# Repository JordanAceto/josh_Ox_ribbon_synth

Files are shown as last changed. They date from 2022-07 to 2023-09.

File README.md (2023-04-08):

# josh_Ox_ribbon_synth
Ribbon synth for [Josh Oxford](https://www.joshoxford.com/)

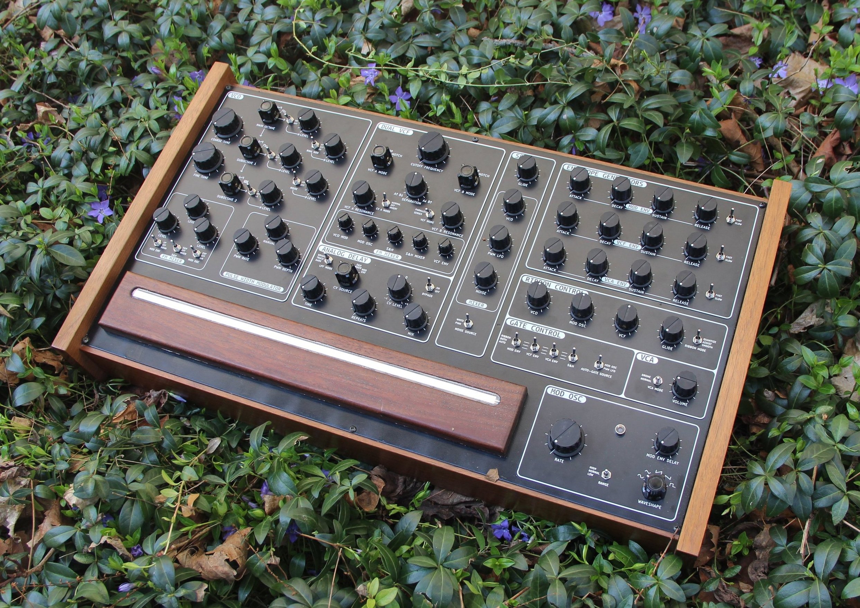
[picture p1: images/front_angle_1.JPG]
synth front synth from front


## Main Features 
- Single VCO with two sub-oscillators
- Transformer/diode based Ring Modulator
- Dual State-Variable Filter
- Bucket brigade Analog Delay with modulation
- Envelope VCA
- Volume VCA
- Three ADSR's
- Sample and Hold
- Flexible gate control
- Versatile Modulation Oscillator
- Ribbon controller with quantizer

## Status:

A complete synthesizer has been built with the current documents here. This instrument has been road tested on a few gigs. The current files represent a working instrument.

There are a few small PCB kludges required, and some potential future enhancements.
See the `github Issues` and `github Discussions` for little things that could be improved and an idea of what may change in the future.

The synth is constructed with semi-independent PCBs and panels for the major circuit blocks, which allows for gradually upgrading the components over time.

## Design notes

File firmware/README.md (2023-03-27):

# Rust Language STM32L412KBU Digital Ribbon Controller

## The firmware is installed on an STM32 microcontroller on the ribbon board via SWD header

---

## What it does
- Reads the analog ribbon controller and converts it into position and finger-down information
- Reads incoming MIDI messages and merges MIDI note information with the ribbon control
- Generates analog 1volt/octave and gate signals which can be used to control the VCO, MODOSC, VCF, and ADSRs

---

## Features
- Independent VCO, MODOSC, and VCF attenuators
- Glide control
- Quantizer for VCO only with three modes:
  - QUANTIZE: hard quantization, notes zipper to one another
  - ASSIST: initial finger presses attempt to play in-tune, but sliding is smooth
  - SMOOTH: unquantized smooth ribbon

---

## MIDI implementation
- There is some MIDI functionality baked into the hardware, but it is not complete.
- Same for the software, MIDI input is farther along than MIDI output.
- At this moment, there is no MIDI jack exposed to the outside world, so there is no way for the user to use MIDI.
- It is possible that future improvements will expand on the MIDI functionality. There are internal headers on the ribbon circuit board for future MIDI IO expansion.

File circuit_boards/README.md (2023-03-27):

# Ox Ribbon Synth Circuit Boards

## The synth is made up of the following components:
- Power Entry and step-down AC transformer
- AC-DC power supply board
    - Provides regulated +/- 15 VDC to the rest of the system
- Main VCO board
    - Contains two fully featured sub-scillators, a ring-modulator, pulse-width modulation LFO, and audio mixer
- VCF/VCA/BBD board
    - Contains a dual State Variable Filter setup with series/parallel switching and rich modulation
    - Linear VCA for envelope control
    - Analog delay effects unit
    - Linear VCA for final volume control
- Sample & Hold board
    - With three input mixer, white/pink noise source, and glide control
- Modulation Oscillator
    - Wide frequency range, five waveforms, and delayed modulation capability
- ADSR board
    - Three independent ADSR generators
- Ribbon board
    - Generates ribbon CV and gate signals
    - routes and combines ribbon gate and auto-gate

## Each major system component has its own subdirectory with:
- All files needed to edit the schematic and PCB layout with KiCad
- Documentation files needed to build and troubleshoot the circuits

## The approximate current draw of the circuitboards is:

| Board | V+ | V- |
| --- | ----- | ----- |
| ADSR | 30mA  | 20mA  |
| main VCO  | 120mA | 100mA |
| mod osc | 20mA  | 10mA  |
| ribbon | 40mA  | 20mA  |
| S&H | 20mA  | 20mA  |
| VCF/VCA | 60mA  | 50mA  |
| | | |
| **TOTAL** | 290mA | 220mA |

## The block diagram below illustrates how the components interact:
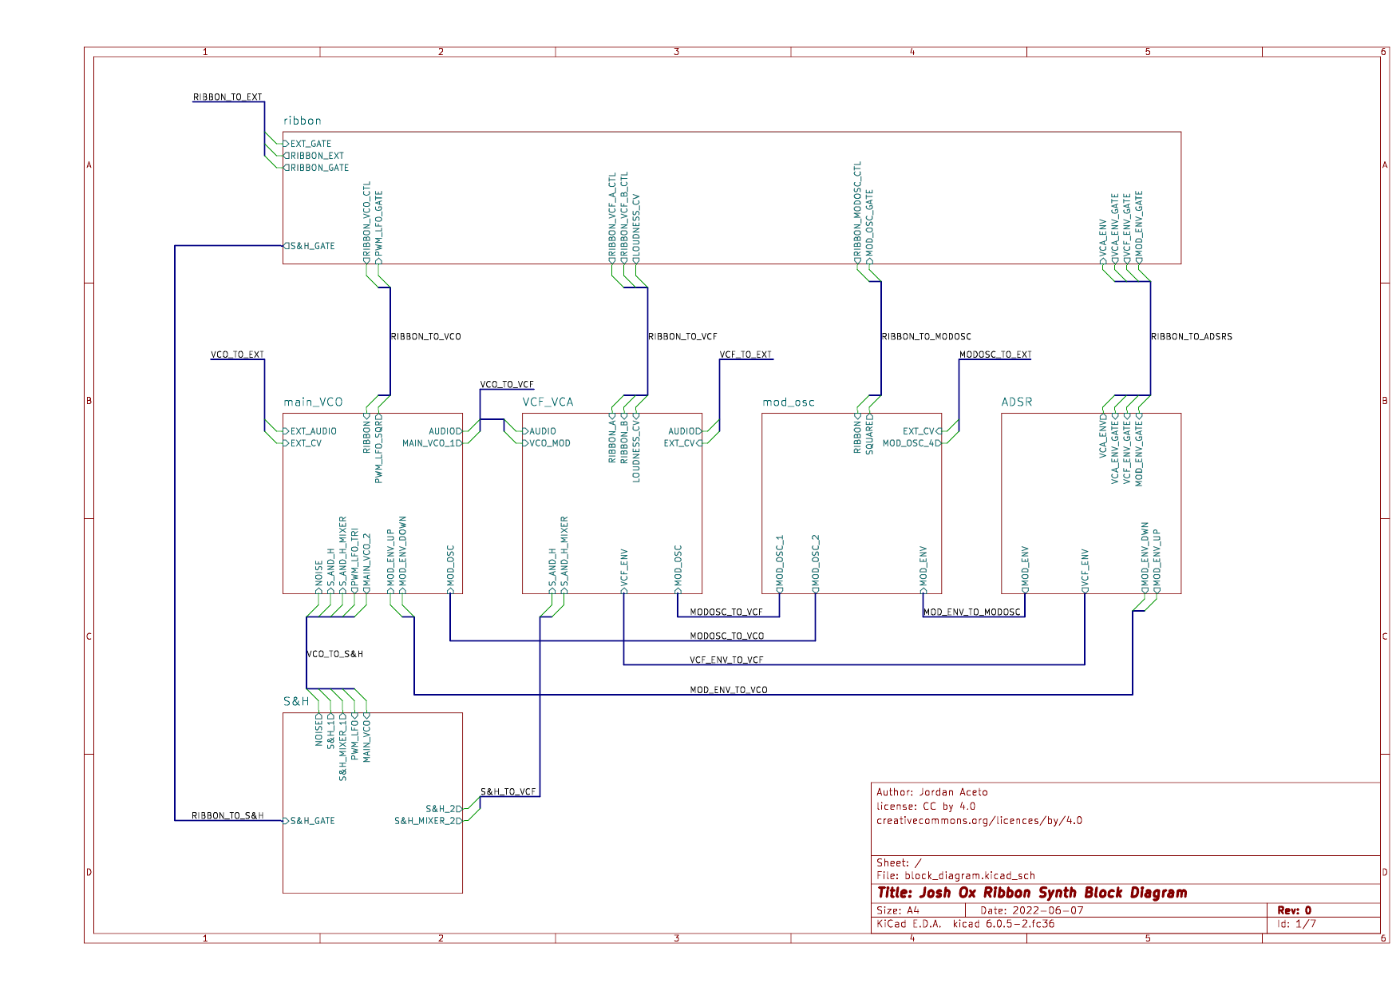
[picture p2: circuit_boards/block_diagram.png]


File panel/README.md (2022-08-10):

# Panel Files

The front panel is made of an aluminum sheet, with individual 0.8mm thick PCB panels for each major circuit block.

The PCB panels are a cheap way to get a decent looking front panel. Using individual panels keeps the cost of each panel down, and allows for flexibility: if a circuit block needs to be modified in the future, we can remake just the individual panel section, and not the whole front panel.

See the individual directories for details.

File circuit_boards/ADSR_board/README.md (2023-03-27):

# Triple ADSR Board

## [SCHEMATIC](https://github.com/JordanAceto/josh_Ox_ribbon_synth/blob/master/circuit_boards/ADSR_board/docs/ADSR_board_schematic.pdf)

Three ADSR envelope generators with short and long time range switch.

A comparator and analog switch ensure that the sustain control reacts quickly during sustain phases, even when the decay control is set for long time constants.

pcb render

pcb render

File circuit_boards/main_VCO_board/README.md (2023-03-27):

# Complex VCO

## [SCHEMATIC](https://github.com/JordanAceto/josh_Ox_ribbon_synth/blob/master/circuit_boards/main_VCO_board/docs/main_VCO_board_schematic.pdf)

Single VCO with tons 'o extra stuff
- SSI2130 VCO core
- sine, triangle, sawtooth, and variable pulse waveforms
- two suboscillators, each with all four waveforms, phase modulated (not locked) to the main VCO
- PWM LFO
- transformer/diode based ring modulator
- audio mixer
- FM mixer

pcb render

pcb render

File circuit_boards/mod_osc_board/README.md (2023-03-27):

# Modulation Oscillator

## [SCHEMATIC](https://github.com/JordanAceto/josh_Ox_ribbon_synth/blob/master/circuit_boards/mod_osc_board/docs/mod_osc_board_schematic.pdf)

Auxilliary modulation oscillator
- SSI21340 VCO core
- sine, triangle, up and down-going sawtooth, and square waveforms
- wide frequency range with three range settings (low, normal, high)
- tracks the ribbon controller

pcb render

pcb render

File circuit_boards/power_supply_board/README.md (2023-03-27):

# Power Supply Board

## [SCHEMATIC](https://github.com/JordanAceto/josh_Ox_ribbon_synth/blob/master/circuit_boards/power_supply_board/docs/power_supply_schematic.pdf)

This is an unremarkable LM317/LM337 based bipolar 15 volt DC supply which supplies power to the rest of the system.

pcb render

pcb render

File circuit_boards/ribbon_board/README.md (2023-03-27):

# ribbon_board

## [SCHEMATIC](https://github.com/JordanAceto/josh_Ox_ribbon_synth/blob/master/circuit_boards/ribbon_board/docs/ribbon_board_schematic.pdf)

Digital ribbon controller, gate combiner, and VCA control scaler

PCB front

PCB back

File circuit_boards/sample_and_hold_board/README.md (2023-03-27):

# Sample And Hold

## [SCHEMATIC](https://github.com/JordanAceto/josh_Ox_ribbon_synth/blob/master/circuit_boards/sample_and_hold_board/docs/sample_and_hold_board_schematic.pdf)

Basic Sample & Hold with three input mixer, noise source, and glide control.

pcb render

pcb render

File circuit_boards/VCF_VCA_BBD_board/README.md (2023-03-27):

# VCF/VCA/BBD Board

## [SCHEMATIC](https://github.com/JordanAceto/josh_Ox_ribbon_synth/blob/master/circuit_boards/VCF_VCA_BBD_board/docs/VCF_VCA_BBD_board_schematic.pdf)

This board contains a dual State Variable Filter, Bucket Brigade Analog Delay, and two linear audio VCAs.

### State Variable Filters
- each filter has Lowpass, Bandpass, Highpass and Notch outputs
- filters can be routed in either Serial or Parallel configuration
- CV mixer for a variety of modulation
- control to filter A can be inverted relative to filter B

### Analog Delay
- about 40 milliseconds to 1 second of delay
- modulation input with attenuverter
- three lowpass filter modes:
    - `BRIGHT`: no filtration, aliasing occurs at long delay times. Aliasing is normally avoided, but it can sound good in a nasty way. Useful for extreme effects
    - `TRACK`: lowpass filter tracks the delay clock, brighter at short times and darker at long times
    - `DARK`: classic warm BBD sound

### VCAs
- one VCA for the volume ADSR before the analog delay
- one VCA for the final master volume control after the delay

pcb render

pcb render

## Measurements to aid in calibration (no ribbon ctl, no modulation, knob swept ccw to cw, approx):
- VCF freq range: 12Hz, 12kHz
- delay clk: 100kHz, 4kHz
- delay lpf
    - track mode: 60kHz, 3kHz
    - bright mode: fixed 20kHz
    - dark mode: fixed 3kHz

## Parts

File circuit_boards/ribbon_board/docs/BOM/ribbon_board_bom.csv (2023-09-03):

# | Reference | Qty | Value | Footprint | DNP
1 | C201, C202, C203, C204, C205, C206, C207, C208, C209, C210, C211, C301, C302, C303, C304, C306, C307, C308, C309, C310, C311, C312, C903, C904, C906, C909, C910, C911, C912, C913, C914, C915, C916, C917 | 34 | 100n | Capacitor_SMD:C_0603_1608Metric
2 | C212, C213 | 2 | 4p3 | Capacitor_SMD:C_0603_1608Metric
3 | C305, C907 | 2 | 1u | Capacitor_SMD:C_0805_2012Metric
4 | C901, C902 | 2 | 10u | Capacitor_THT:CP_Radial_D6.3mm_P2.50mm
5 | C905 | 1 | 2u2 | Capacitor_SMD:C_0805_2012Metric
6 | D201 | 1 | DNF | Diode_SMD:D_SOD-123 | DNP
7 | D202, D301, D501, D502, D503, D504, D601, D602, D603, D604, D701, D702, D703, D704, D801, D802, D803, D804 | 18 | 1N4148W | Diode_SMD:D_SOD-123
8 | D302, D303 | 2 | 5v1 | Diode_SMD:D_SOD-123
9 | FB1001, FB1002 | 2 | 100R @ 100MHz | Inductor_SMD:L_0805_2012Metric
10 | J1 | 1 | VCO_port | Connector_Molex:Molex_KK-254_AE-6410-03A_1x03_P2.54mm_Vertical
11 | J2 | 1 | VCF_port | Connector_Molex:Molex_KK-254_AE-6410-05A_1x05_P2.54mm_Vertical
12 | J3 | 1 | mod_osc_port | Connector_Molex:Molex_KK-254_AE-6410-04A_1x04_P2.54mm_Vertical
13 | J4 | 1 | ADSR_port | Connector_Molex:Molex_KK-254_AE-6410-05A_1x05_P2.54mm_Vertical
14 | J5 | 1 | S&H_port | Connector_Molex:Molex_KK-254_AE-6410-02A_1x02_P2.54mm_Vertical
15 | J6 | 1 | ext_port | Connector_Molex:Molex_KK-254_AE-6410-04A_1x04_P2.54mm_Vertical
16 | J7 | 1 | power_entry | Connector_IDC:IDC-Header_2x05_P2.54mm_Vertical
17 | J8 | 1 | MIDI_IO_port | Connector_Molex:Molex_KK-254_AE-6410-05A_1x05_P2.54mm_Vertical
18 | J201 | 1 | SWD_header | Connector_PinHeader_2.54mm:PinHeader_1x04_P2.54mm_Vertical
19 | R101, R102, R204, R313, R904 | 5 | 1k | Resistor_SMD:R_0805_2012Metric
20 | R201 | 1 | 22 | Resistor_SMD:R_0805_2012Metric
21 | R202 | 1 | DNF | Resistor_SMD:R_0805_2012Metric | DNP
22 | R203, R206, R309, R310, R401, R402, R403, R404 | 8 | 10k | Resistor_SMD:R_0805_2012Metric
23 | R205 | 1 | 220 | Resistor_SMD:R_0805_2012Metric
24 | R207, R208 | 2 | 47 | Resistor_SMD:R_0805_2012Metric
25 | R301, R302, R303, R304 | 4 | 20k | Resistor_SMD:R_0805_2012Metric
26 | R305, R306, R307, R308 | 4 | 68k | Resistor_SMD:R_0805_2012Metric
27 | R311, R314, R405, R406, R501, R502, R601, R602, R701, R702, R801, R802, R903 | 13 | 100k | Resistor_SMD:R_0805_2012Metric
28 | R312, R407, R408 | 3 | 1M2 | Resistor_SMD:R_0805_2012Metric
29 | R315, R316, R317, R318 | 4 | 12k | Resistor_SMD:R_0805_2012Metric
30 | R901 | 1 | 82k | Resistor_SMD:R_0805_2012Metric
31 | R902 | 1 | 200k | Resistor_SMD:R_0805_2012Metric
32 | RV201 | 1 | 10k | Potentiometer_THT:Potentiometer_Alpha_RD901F-40-00D_Single_Vertical
33 | RV202, RV203 | 2 | 10k c.d. | Potentiometer_THT:Potentiometer_Alpha_RD901F-40-00D_Single_Vertical
34 | RV204 | 1 | 10k c.d. | Potentiometer_THT:Potentiometer_Alpha_RD901F-40-00D_Single_Vertical
35 | RV301, RV302, RV303, RV304 | 4 | 5k | Potentiometer_THT:Potentiometer_Bourns_3296W_Vertical
36 | RV901 | 1 | 100k | Potentiometer_THT:Potentiometer_Alpha_RD901F-40-00D_Single_Vertical
37 | SP201 | 1 | softpot | Connector_Molex:Molex_KK-254_AE-6410-03A_1x03_P2.54mm_Vertical
38 | SW201, SW501, SW601, SW701, SW801 | 5 | SW_SPDT_MSM | custom_footprints:SPDT_mini_toggle
39 | SW202 | 1 | MIDI_CH | Button_Switch_THT:SW_DIP_SPSTx04_Slide_9.78x12.34mm_W7.62mm_P2.54mm
40 | SW401, SW901 | 2 | SW_SPDT | custom_footprints:SPDT_mini_toggle
41 | TP201 | 1 | RAW_RIBBON | TestPoint:TestPoint_Keystone_5000-5004_Miniature
42 | TP301 | 1 | VCO_RIBBON | TestPoint:TestPoint_Keystone_5000-5004_Miniature
43 | TP302 | 1 | MODOSC_RIBBON | TestPoint:TestPoint_Keystone_5000-5004_Miniature
44 | TP303 | 1 | VCF_RIBBON | TestPoint:TestPoint_Keystone_5000-5004_Miniature
45 | TP304 | 1 | AUX_CV | TestPoint:TestPoint_Keystone_5000-5004_Miniature
46 | TP401 | 1 | rib_gate | TestPoint:TestPoint_Keystone_5000-5004_Miniature
47 | TP402 | 1 | auto_gate | TestPoint:TestPoint_Keystone_5000-5004_Miniature
48 | TP901 | 1 | VCA_ADSR_CV | TestPoint:TestPoint_Keystone_5000-5004_Miniature
49 | TP902 | 1 | VCA_VOL_CV | TestPoint:TestPoint_Keystone_5000-5004_Miniature
50 | TP1001 | 1 | V+ | TestPoint:TestPoint_Keystone_5000-5004_Miniature
51 | TP1002 | 1 | V- | TestPoint:TestPoint_Keystone_5000-5004_Miniature
52 | TP1003 | 1 | GND | TestPoint:TestPoint_Bridge_Pitch7.62mm_Drill1.3mm
53 | TP1004 | 1 | 3v3 | TestPoint:TestPoint_Keystone_5000-5004_Miniature
54 | U1 | 1 | STM32L412K8Ux | Package_DFN_QFN:QFN-32-1EP_5x5mm_P0.5mm_EP3.45x3.45mm
55 | U2 | 1 | VO0600T | Package_SO:SOIC-8_3.9x4.9mm_P1.27mm
56 | U3, U4 | 2 | SN74LV1T34DBV | Package_TO_SOT_SMD:SOT-23-5
57 | U5 | 1 | DAC8164 | Package_SO:TSSOP-16_4.4x5mm_P0.65mm
58 | U6, U7, U8, U9 | 4 | TL072 | Package_SO:SOIC-8_3.9x4.9mm_P1.27mm
59 | U10 | 1 | 4081 | Package_SO:SOIC-14_3.9x8.7mm_P1.27mm
60 | U1004 | 1 | L78L05_SOT89 | Package_TO_SOT_SMD:SOT-89-3
61 | U1006 | 1 | L78L33_SOT89 | Package_TO_SOT_SMD:SOT-89-3
62 | Y1 | 1 | 32_768KHZ | Crystal:Crystal_SMD_MicroCrystal_CC7V-T1A-2Pin_3.2x1.5mm

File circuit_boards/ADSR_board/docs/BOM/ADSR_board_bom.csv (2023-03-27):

# | Reference | Qty | Value | Footprint | DNP
1 | C101, C102 | 2 | 10u | Capacitor_THT:CP_Radial_D6.3mm_P2.50mm
2 | C103, C104, C205, C206, C207, C208, C209, C210, C305, C306, C307, C308, C309, C310, C405, C406, C407, C408, C409, C410 | 20 | 100n | Capacitor_SMD:C_0805_2012Metric
3 | C201, C202, C301, C302, C401, C402 | 6 | 1n | Capacitor_SMD:C_0805_2012Metric
4 | C203, C303, C403 | 3 | 2u2 | Capacitor_THT:CP_Radial_D6.3mm_P2.50mm
5 | C204, C304, C404 | 3 | 22u | Capacitor_THT:CP_Radial_D6.3mm_P2.50mm
6 | D201, D202, D301, D302, D401, D402 | 6 | 1N4148W | Diode_SMD:D_SOD-123
7 | J1 | 1 | ribbon_port | Connector_Molex:Molex_KK-254_AE-6410-05A_1x05_P2.54mm_Vertical
8 | J2 | 1 | modosc_port | Connector_Molex:Molex_KK-254_AE-6410-02A_1x02_P2.54mm_Vertical
9 | J3 | 1 | VCO_port | Connector_Molex:Molex_KK-254_AE-6410-03A_1x03_P2.54mm_Vertical
10 | J4 | 1 | VCF_port | Connector_Molex:Molex_KK-254_AE-6410-03A_1x03_P2.54mm_Vertical
11 | J5 | 1 | power_entry | Connector_IDC:IDC-Header_2x05_P2.54mm_Vertical
12 | Q201, Q301, Q401 | 3 | MMBT3904 | Package_TO_SOT_SMD:SOT-23
13 | R101, R102, R201, R202, R211, R301, R302, R311, R401, R402, R411 | 11 | 100k | Resistor_SMD:R_0805_2012Metric
14 | R203, R204, R212, R214, R303, R304, R312, R314, R403, R404, R412, R414 | 12 | 10k | Resistor_SMD:R_0805_2012Metric
15 | R205, R305, R405 | 3 | 5k6 | Resistor_SMD:R_0805_2012Metric
16 | R206, R207, R208, R306, R307, R308, R406, R407, R408 | 9 | 22 | Resistor_SMD:R_0805_2012Metric
17 | R209, R309, R409 | 3 | 100 | Resistor_SMD:R_0805_2012Metric
18 | R210, R310, R410 | 3 | 2k7 | Resistor_SMD:R_0805_2012Metric
19 | R213, R313, R413 | 3 | 2M2 | Resistor_SMD:R_0805_2012Metric
20 | RV201, RV202, RV204, RV301, RV302, RV304, RV401, RV402, RV404 | 9 | 1MA | Potentiometer_THT:Potentiometer_Alpha_RD901F-40-00D_Single_Vertical
21 | RV203, RV303, RV403 | 3 | 10k | Potentiometer_THT:Potentiometer_Alpha_RD901F-40-00D_Single_Vertical
22 | SW201, SW301, SW401 | 3 | SW_SPDT | custom_footprints:SPDT_mini_toggle
23 | TP1 | 1 | MOD env | TestPoint:TestPoint_Keystone_5000-5004_Miniature
24 | TP2 | 1 | inv mod env | TestPoint:TestPoint_Keystone_5000-5004_Miniature
25 | TP3 | 1 | VCF env | TestPoint:TestPoint_Keystone_5000-5004_Miniature
26 | TP4 | 1 | VCA env | TestPoint:TestPoint_Keystone_5000-5004_Miniature
27 | TP5 | 1 | V+ | TestPoint:TestPoint_Keystone_5000-5004_Miniature
28 | TP6 | 1 | GND | TestPoint:TestPoint_Bridge_Pitch7.62mm_Drill1.3mm
29 | TP7 | 1 | V- | TestPoint:TestPoint_Keystone_5000-5004_Miniature
30 | U101, U203, U303, U403 | 4 | TL072 | Package_SO:SOIC-8_3.9x4.9mm_P1.27mm
31 | U201, U301, U401 | 3 | TLC555 | Package_SO:SOIC-8_3.9x4.9mm_P1.27mm
32 | U202, U302, U402 | 3 | CD4052B | Package_SO:SOIC-16_3.9x9.9mm_P1.27mm
33 | U204, U304, U404 | 3 | DG470EY | Package_SO:SOIC-8_3.9x4.9mm_P1.27mm

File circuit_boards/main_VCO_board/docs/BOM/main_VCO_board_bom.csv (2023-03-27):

# | Reference | Qty | Value | Footprint | DNP
1 | C201, C402, C403, C404, C502, C803, C901, C1001, C1603, C1701, C1801, C2003, C2004, C2005, C2006, C2101, C2102, C2103, C2104 | 19 | 100p | Capacitor_SMD:C_0805_2012Metric
2 | C202, C601, C1401 | 3 | 1u | Capacitor_THT:C_Rect_L7.2mm_W5.5mm_P5.00mm_FKS2_FKP2_MKS2_MKP2
3 | C301, C801, C1601 | 3 | 10u | Capacitor_SMD:C_0805_2012Metric
4 | C302, C1101, C1202, C1901 | 4 | 10n | Capacitor_SMD:C_0805_2012Metric
5 | C303 | 1 | 3N9 COG | Capacitor_SMD:C_0805_2012Metric
6 | C401 | 1 | 10u BP | Capacitor_THT:C_Rect_L7.2mm_W3.5mm_P5.00mm_FKS2_FKP2_MKS2_MKP2
7 | C501 | 1 | 220n | Capacitor_THT:C_Rect_L7.0mm_W2.5mm_P5.00mm
8 | C701, C1201, C1501, C2001, C2002, C2201 | 6 | 10p | Capacitor_SMD:C_0805_2012Metric
9 | C802, C1602 | 2 | 10u BP | Capacitor_THT:C_Radial_D6.3mm_H5.0mm_P2.50mm
10 | C2301, C2302, C2303, C2304, C2305, C2306, C2307, C2308, C2309, C2310, C2313, C2314, C2315, C2316, C2317, C2318, C2321, C2322, C2323, C2324, C2325, C2326, C2327, C2328, C2329, C2330, C2331, C2332, C2333, C2334, C2335, C2336, C2337, C2338, C2339, C2340, C2341, C2342 | 38 | 100n | Capacitor_SMD:C_0805_2012Metric
11 | C2311, C2312 | 2 | 10u | Capacitor_THT:CP_Radial_D6.3mm_P2.50mm
12 | C2319, C2320 | 2 | 470n | Capacitor_SMD:C_0805_2012Metric
13 | D301, D302, D601, D602, D1001, D1002, D1801, D1802 | 8 | 1N4148W | Diode_SMD:D_SOD-123
14 | D501, D502, D2101, D2102, D2103, D2104 | 6 | BAT48ZFILM | Diode_SMD:D_SOD-123
15 | J101 | 1 | ribbon_port | Connector_Molex:Molex_KK-254_AE-6410-03A_1x03_P2.54mm_Vertical
16 | J102 | 1 | modosc_port | Connector_Molex:Molex_KK-254_AE-6410-02A_1x02_P2.54mm_Vertical
17 | J103 | 1 | ADSR_port | Connector_Molex:Molex_KK-254_AE-6410-03A_1x03_P2.54mm_Vertical
18 | J104 | 1 | S&H_port | Connector_Molex:Molex_KK-254_AE-6410-06A_1x06_P2.54mm_Vertical
19 | J105 | 1 | ext_con | Connector_Molex:Molex_KK-254_AE-6410-03A_1x03_P2.54mm_Vertical
20 | J106 | 1 | vcf_port | Connector_Molex:Molex_KK-254_AE-6410-03A_1x03_P2.54mm_Vertical
21 | J501 | 1 | aux_pwm | Connector_PinHeader_2.54mm:PinHeader_1x02_P2.54mm_Vertical
22 | J2301 | 1 | power_entry | Connector_IDC:IDC-Header_2x05_P2.54mm_Vertical
23 | JP101 | 1 | rm_x_select | Connector_PinHeader_2.54mm:PinHeader_1x03_P2.54mm_Vertical
24 | Q401 | 1 | 2N7002 | Package_TO_SOT_SMD:SOT-23
25 | Q1101, Q1102, Q1901, Q1902 | 4 | MMBT3904 | Package_TO_SOT_SMD:SOT-23
26 | R201 | 1 | 150k | Resistor_SMD:R_0805_2012Metric
27 | R202 | 1 | 56k | Resistor_SMD:R_0805_2012Metric
28 | R203, R804, R1004, R1006, R1604, R1804, R1806 | 7 | 120k | Resistor_SMD:R_0805_2012Metric
29 | R204, R205, R304, R306, R307, R308, R309, R310, R311, R317, R401, R403, R405, R501, R505, R506, R507, R508, R509, R602, R704, R705, R706, R805, R807, R808, R809, R811, R813, R815, R902, R1203, R1504, R1505, R1506, R1605, R1607, R1608, R1609, R1611, R1613, R1615, R1702, R2002, R2004, R2008, R2009, R2010, R2011, R2012, R2015, R2101, R2102, R2103, R2105, R2107, R2108, R2109, R2110, R2111, R2201, R2202, R2203, R2204, R2205 | 65 | 100k | Resistor_SMD:R_0805_2012Metric
30 | R206, R702, R703, R814, R1502, R1503, R1614, R2005, R2006 | 9 | 200k | Resistor_SMD:R_0805_2012Metric
31 | R301, R302, R406, R603, R604, R803, R1103, R1106, R1201, R1603, R1903, R1906, R2001, R2303, R2304 | 15 | 10k | Resistor_SMD:R_0805_2012Metric
32 | R303, R402, R901, R1701, R2206 | 5 | 33k | Resistor_SMD:R_0805_2012Metric
33 | R305 | 1 | 1M | Resistor_SMD:R_0805_2012Metric
34 | R312, R502 | 2 | 270k | Resistor_SMD:R_0805_2012Metric
35 | R313 | 1 | 47k | Resistor_SMD:R_0805_2012Metric
36 | R314 | 1 | 270 | Resistor_SMD:R_0805_2012Metric
37 | R315 | 1 | 470k | Resistor_SMD:R_0805_2012Metric
38 | R316, R319, R321, R2302 | 4 | 4k7 | Resistor_SMD:R_0805_2012Metric
39 | R318 | 1 | 3k9 | Resistor_SMD:R_0805_2012Metric
40 | R320, R1108, R1109, R1908, R1909 | 5 | 12k | Resistor_SMD:R_0805_2012Metric
41 | R322, R1105, R1905 | 3 | 18k | Resistor_SMD:R_0805_2012Metric
42 | R404, R503 | 2 | 100 | Resistor_SMD:R_0805_2012Metric
43 | R407, R408, R409, R2013 | 4 | 20k | Resistor_SMD:R_0805_2012Metric
44 | R504, R1102, R1107, R1205, R1902, R1907, R2007 | 7 | 2k2 | Resistor_SMD:R_0805_2012Metric
45 | R510, R511, R806, R810, R1206, R1606, R1610 | 7 | 1k | Resistor_SMD:R_0805_2012Metric
46 | R601 | 1 | 1M5 | Resistor_SMD:R_0805_2012Metric
47 | R701, R812, R1501, R1612, R2016 | 5 | 180k | Resistor_SMD:R_0805_2012Metric
48 | R801, R1601 | 2 | 8k2 | Resistor_SMD:R_0805_2012Metric
49 | R802, R1602 | 2 | 2k7 | Resistor_SMD:R_0805_2012Metric
50 | R1001, R1002, R1005, R1202, R1801, R1802, R1805 | 7 | 15k | Resistor_SMD:R_0805_2012Metric
51 | R1003, R1803 | 2 | 7k5 | Resistor_SMD:R_0805_2012Metric
52 | R1101, R1901 | 2 | 27k | Resistor_SMD:R_0805_2012Metric
53 | R1104, R1904 | 2 | 390 | Resistor_SMD:R_0805_2012Metric
54 | R1204, R2003 | 2 | 10M | Resistor_SMD:R_0805_2012Metric
55 | R1401 | 1 | 2M2 | Resistor_SMD:R_0805_2012Metric
56 | R2014 | 1 | 220k | Resistor_SMD:R_0805_2012Metric
57 | R2104, R2106 | 2 | 330 | Resistor_SMD:R_0805_2012Metric
58 | R2112 | 1 | 560k | Resistor_SMD:R_0805_2012Metric
59 | R2207 | 1 | 82k | Resistor_SMD:R_0805_2012Metric
60 | R2301 | 1 | 1k8 | Resistor_SMD:R_0805_2012Metric
61 | RV201, RV202 | 2 | 10k | Potentiometer_THT:Potentiometer_Alpha_RD901F-40-00D_Single_Vertical
62 | RV203, RV204, RV205, RV501, RV502, RV503, RV2201, RV2202, RV2203, RV2204, RV2205 | 11 | 100k | Potentiometer_THT:Potentiometer_Alpha_RD901F-40-00D_Single_Vertical
63 | RV301, RV302, RV303, RV802, RV1602 | 5 | 5k | Potentiometer_THT:Potentiometer_Bourns_3296W_Vertical
64 | RV701, RV801, RV1101, RV1102, RV1501, RV1601, RV1901, RV1902, RV2001, RV2101, RV2102 | 11 | 50k | Potentiometer_THT:Potentiometer_Bourns_3296W_Vertical
65 | SW201, SW202, SW203 | 3 | SW_SPDT_CO | custom_footprints:SPDT_mini_toggle
66 | SW301, SW602, SW1402 | 3 | SR1712F-0204 | custom_footprints:SR1712F_rotary_switch
67 | SW601, SW1401, SW2101 | 3 | SW_DPDT_CO | custom_footprints:DPDT_mini_toggle
68 | SW2201, SW2202 | 2 | SW_SPDT | custom_footprints:SPDT_mini_toggle
69 | TP101 | 1 | pwm_cv | TestPoint:TestPoint_Keystone_5000-5004_Miniature
70 | TP102 | 1 | oct_0 | TestPoint:TestPoint_Keystone_5000-5004_Miniature
71 | TP103 | 1 | oct_1 | TestPoint:TestPoint_Keystone_5000-5004_Miniature
72 | TP104 | 1 | oct_2 | TestPoint:TestPoint_Keystone_5000-5004_Miniature
73 | TP105 | 1 | ring_mod | TestPoint:TestPoint_Keystone_5000-5004_Miniature
74 | TP106 | 1 | mix | TestPoint:TestPoint_Keystone_5000-5004_Miniature
75 | TP801, TP1601 | 2 | anim_LFO | TestPoint:TestPoint_Keystone_5000-5004_Miniature
76 | TP2301 | 1 | V+ | TestPoint:TestPoint_Keystone_5000-5004_Miniature
77 | TP2302 | 1 | V- | TestPoint:TestPoint_Keystone_5000-5004_Miniature
78 | TP2303 | 1 | GND | TestPoint:TestPoint_Bridge_Pitch7.62mm_Drill1.3mm
79 | TP2304 | 1 | +5_REF | TestPoint:TestPoint_Keystone_5000-5004_Miniature
80 | TP2305 | 1 | +2V5 | TestPoint:TestPoint_Keystone_5000-5004_Miniature
81 | TP2306 | 1 | -5_REF | TestPoint:TestPoint_Keystone_5000-5004_Miniature
82 | TP2307 | 1 | +5 | TestPoint:TestPoint_Keystone_5000-5004_Miniature
83 | TP2308 | 1 | -5 | TestPoint:TestPoint_Keystone_5000-5004_Miniature
84 | TR2101, TR2102 | 2 | Triad_TY_141P | custom_footprints:Triad_TY-141P
85 | U1, U2, U6, U8, U11, U12, U14, U15, U16 | 9 | TL074 | Package_SO:SOIC-14_3.9x8.7mm_P1.27mm
86 | U3, U7, U13 | 3 | LM311 | Package_SO:SOIC-8_3.9x4.9mm_P1.27mm
87 | U4 | 1 | SSI2130 | custom_footprints:PQN32_HandSoldering
88 | U5 | 1 | 4013 | Package_SO:SOIC-14_3.9x8.7mm_P1.27mm
89 | U9 | 1 | LM555xM | Package_SO:SOIC-8_3.9x4.9mm_P1.27mm
90 | U10 | 1 | DG413xY | Package_SO:SOIC-16_3.9x9.9mm_P1.27mm
91 | U17 | 1 | NE5532 | Package_SO:SOIC-8_3.9x4.9mm_P1.27mm
92 | U18 | 1 | TL072 | Package_SO:SOIC-8_3.9x4.9mm_P1.27mm
93 | U19 | 1 | DG447DV | Package_SO:TSOP-6_1.65x3.05mm_P0.95mm
94 | U2301 | 1 | L78L05_SOT89 | Package_TO_SOT_SMD:SOT-89-3
95 | U2302 | 1 | L79L05_SOT89 | Package_TO_SOT_SMD:SOT-89-3
96 | U2303 | 1 | LM4040C-2.5 | Package_TO_SOT_SMD:SOT-23
97 | U2304 | 1 | LM4040DBZ-5 | Package_TO_SOT_SMD:SOT-23

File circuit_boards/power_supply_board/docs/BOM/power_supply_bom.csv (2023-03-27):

# | Reference | Qty | Value | Footprint | DNP
1 | C1, C2 | 2 | 3300u | Capacitor_THT:CP_Radial_D18.0mm_P7.50mm
2 | C3, C4, C5, C6 | 4 | 100n | Capacitor_THT:C_Rect_L7.0mm_W2.5mm_P5.00mm
3 | C7, C8 | 2 | 10u | Capacitor_THT:CP_Radial_D6.3mm_P2.50mm
4 | D1, D2, D3, D4, D5, D6, D7, D8 | 8 | 1N4002 | Diode_THT:D_DO-41_SOD81_P10.16mm_Horizontal
5 | J1, J2, J3, J4, J5, J6, J7, J8 | 8 | power_out | Connector_IDC:IDC-Header_2x05_P2.54mm_Vertical
6 | J9 | 1 | AC_power_in | Connector_Molex:Molex_Mini-Fit_Jr_5566-04A_2x02_P4.20mm_Vertical
7 | R1, R2 | 2 | 240 | Resistor_THT:R_Axial_DIN0207_L6.3mm_D2.5mm_P10.16mm_Horizontal
8 | RV1, RV2 | 2 | 5k | Potentiometer_THT:Potentiometer_Bourns_3296W_Vertical
9 | TP1 | 1 | V+ | TestPoint:TestPoint_Keystone_5000-5004_Miniature
10 | TP2 | 1 | V- | TestPoint:TestPoint_Keystone_5000-5004_Miniature
11 | TP3 | 1 | GND | TestPoint:TestPoint_Bridge_Pitch7.62mm_Drill1.3mm
12 | U1 | 1 | LM317_TO-220 | Package_TO_SOT_THT:TO-220-3_Vertical
13 | U2 | 1 | LM337_TO220 | Package_TO_SOT_THT:TO-220-3_Vertical

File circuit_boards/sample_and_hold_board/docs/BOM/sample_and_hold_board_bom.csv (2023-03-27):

# | Reference | Qty | Value | Footprint | DNP
1 | C1, C2 | 2 | 100p | Capacitor_SMD:C_0805_2012Metric
2 | C3, C8 | 2 | 10p | Capacitor_SMD:C_0805_2012Metric
3 | C4, C6 | 2 | 47u | Capacitor_THT:CP_Radial_D6.3mm_P2.50mm
4 | C5, C11, C15, C20 | 4 | 10u | Capacitor_THT:CP_Radial_D6.3mm_P2.50mm
5 | C7 | 1 | 1n | Capacitor_SMD:C_0805_2012Metric
6 | C9 | 1 | 3n3 | Capacitor_SMD:C_0805_2012Metric
7 | C10 | 1 | 47n | Capacitor_SMD:C_0805_2012Metric
8 | C12 | 1 | 2n2 | Capacitor_SMD:C_0805_2012Metric
9 | C13 | 1 | 470n | Capacitor_THT:C_Rect_L7.2mm_W5.5mm_P5.00mm_FKS2_FKP2_MKS2_MKP2
10 | C14 | 1 | 2n2 | Capacitor_THT:C_Rect_L7.2mm_W2.5mm_P5.00mm_FKS2_FKP2_MKS2_MKP2
11 | C16, C17, C18, C19, C21, C22, C23, C24 | 8 | 100n | Capacitor_SMD:C_0805_2012Metric
12 | D1 | 1 | 1N4148W | Diode_SMD:D_SOD-123
13 | J1 | 1 | VCO_port | Connector_Molex:Molex_KK-254_AE-6410-06A_1x06_P2.54mm_Vertical
14 | J2 | 1 | VCF_port | Connector_Molex:Molex_KK-254_AE-6410-03A_1x03_P2.54mm_Vertical
15 | J3 | 1 | ribbon_port | Connector_Molex:Molex_KK-254_AE-6410-02A_1x02_P2.54mm_Vertical
16 | J4 | 1 | power_entry | Connector_IDC:IDC-Header_2x05_P2.54mm_Vertical
17 | Q1, Q3 | 2 | MMBT3904 | Package_TO_SOT_SMD:SOT-23
18 | Q2 | 1 | 2N3904 | Package_TO_SOT_THT:TO-92_Inline_Wide
19 | R1, R2, R4, R5, R6, R16, R27 | 7 | 100k | Resistor_SMD:R_0805_2012Metric
20 | R3, R11 | 2 | 47k | Resistor_SMD:R_0805_2012Metric
21 | R7 | 1 | 47 | Resistor_SMD:R_0805_2012Metric
22 | R8, R19, R22, R25, R28 | 5 | 10k | Resistor_SMD:R_0805_2012Metric
23 | R9, R17 | 2 | 470k | Resistor_SMD:R_0805_2012Metric
24 | R10 | 1 | 33k | Resistor_SMD:R_0805_2012Metric
25 | R12 | 1 | 150k | Resistor_SMD:R_0805_2012Metric
26 | R13 | 1 | 3k9 | Resistor_SMD:R_0805_2012Metric
27 | R14 | 1 | 82k | Resistor_SMD:R_0805_2012Metric
28 | R15 | 1 | 18k | Resistor_SMD:R_0805_2012Metric
29 | R18 | 1 | 390k | Resistor_SMD:R_0805_2012Metric
30 | R20, R21 | 2 | 1M | Resistor_SMD:R_0805_2012Metric
31 | R23 | 1 | 5k6 | Resistor_SMD:R_0805_2012Metric
32 | R24 | 1 | 150 | Resistor_SMD:R_0805_2012Metric
33 | R26 | 1 | 1k8 | Resistor_SMD:R_0805_2012Metric
34 | RV1, RV2, RV3 | 3 | 100k | Potentiometer_THT:Potentiometer_Alpha_RD901F-40-00D_Single_Vertical
35 | RV4 | 1 | 1M | Potentiometer_THT:Potentiometer_Alpha_RD901F-40-00D_Single_Vertical
36 | SW1 | 1 | SW_SPDT | custom_footprints:SPDT_mini_toggle
37 | TP1 | 1 | S&H mixer | TestPoint:TestPoint_Keystone_5000-5004_Miniature
38 | TP2 | 1 | S&H | TestPoint:TestPoint_Keystone_5000-5004_Miniature
39 | TP3 | 1 | trigger | TestPoint:TestPoint_Keystone_5000-5004_Miniature
40 | TP4 | 1 | white noise | TestPoint:TestPoint_Keystone_5000-5004_Miniature
41 | TP5 | 1 | pink noise | TestPoint:TestPoint_Keystone_5000-5004_Miniature
42 | TP6 | 1 | V+ | TestPoint:TestPoint_Keystone_5000-5004_Miniature
43 | TP7 | 1 | GND | TestPoint:TestPoint_Bridge_Pitch7.62mm_Drill1.3mm
44 | TP8 | 1 | V- | TestPoint:TestPoint_Keystone_5000-5004_Miniature
45 | U1, U2, U3 | 3 | TL072 | Package_SO:SO-8_5.3x6.2mm_P1.27mm
46 | U4 | 1 | LF398_SOIC14 | Package_SO:SOIC-14_3.9x8.7mm_P1.27mm

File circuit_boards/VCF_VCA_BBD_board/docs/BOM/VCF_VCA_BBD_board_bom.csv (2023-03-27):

# | Reference | Qty | Value | Footprint | DNP
1 | C101 | 1 | 10u | Capacitor_THT:C_Radial_D6.3mm_H7.0mm_P2.50mm
2 | C201, C203, C301, C303, C502, C503, C1105, C1302, C1303 | 9 | 1n | Capacitor_SMD:C_0805_2012Metric
3 | C202, C204, C302, C304, C801, C802, C803, C804, C1001, C1002, C1003, C1004 | 12 | 220p C0G | Capacitor_SMD:C_0805_2012Metric
4 | C401, C402, C403, C404, C405, C501, C504, C601, C1201, C1202, C1203, C1301, C1304 | 13 | 100p | Capacitor_SMD:C_0805_2012Metric
5 | C701, C706, C901, C903, C906, C1101, C1104 | 7 | 470n | Capacitor_THT:C_Rect_L7.0mm_W3.5mm_P5.00mm
6 | C702, C1103 | 2 | 220p | Capacitor_SMD:C_0805_2012Metric
7 | C703, C1102 | 2 | 220n | Capacitor_SMD:C_0805_2012Metric
8 | C704, C902, C904, C905 | 4 | 10u | Capacitor_SMD:C_0805_2012Metric
9 | C705 | 1 | 2u2 | Capacitor_SMD:C_0805_2012Metric
10 | C805, C1005, C1205 | 3 | 470p | Capacitor_SMD:C_0805_2012Metric
11 | C907, C908, C1207, C1403, C1404, C1405, C1406, C1407, C1408, C1409, C1410, C1411, C1412, C1413, C1414, C1415, C1416, C1417, C1418, C1419, C1420, C1421, C1422, C1423, C1424, C1425, C1426, C1427, C1428, C1429, C1430, C1431, C1432, C1433, C1434, C1435, C1436, C1437, C1438, C1439, C1440, C1441, C1442, C1443 | 44 | 100n | Capacitor_SMD:C_0805_2012Metric
12 | C1106 | 1 | 33p | Capacitor_SMD:C_0805_2012Metric
13 | C1204 | 1 | 10n | Capacitor_SMD:C_0805_2012Metric
14 | C1206 | 1 | 330p C0G | Capacitor_SMD:C_0805_2012Metric
15 | C1401, C1402 | 2 | 10u | Capacitor_THT:CP_Radial_D6.3mm_P2.50mm
16 | D101, D102 | 2 | 2v4 | Diode_SMD:D_SOD-123
17 | D201, D202, D301, D302 | 4 | 5v1 | Diode_SMD:D_SOD-123
18 | D401, D402, D403, D404, D901, D902, D1201, D1202, D1203, D1204 | 10 | 1N4148W | Diode_SMD:D_SOD-123
19 | J2 | 1 | ext_port | Connector_Molex:Molex_KK-254_AE-6410-04A_1x04_P2.54mm_Vertical
20 | J3 | 1 | mod_osc_port | Connector_Molex:Molex_KK-254_AE-6410-02A_1x02_P2.54mm_Vertical
21 | J4 | 1 | S&H_port | Connector_Molex:Molex_KK-254_AE-6410-03A_1x03_P2.54mm_Vertical
22 | J5 | 1 | ADSR_port | Connector_Molex:Molex_KK-254_AE-6410-03A_1x03_P2.54mm_Vertical
23 | J6 | 1 | ribbon_port | Connector_Molex:Molex_KK-254_AE-6410-05A_1x05_P2.54mm_Vertical
24 | J7 | 1 | power_entry | Connector_IDC:IDC-Header_2x05_P2.54mm_Vertical
25 | J101 | 1 | VCO_port | Connector_Molex:Molex_KK-254_AE-6410-03A_1x03_P2.54mm_Vertical
26 | JP801, JP1001 | 2 | self_osc | Connector_PinHeader_2.54mm:PinHeader_1x02_P2.54mm_Vertical
27 | Q1201 | 1 | MMBT3904 | Package_TO_SOT_SMD:SOT-23
28 | Q1202 | 1 | BCM847 | custom_footprints:SOT457
29 | R101, R401, R402, R403, R404, R405, R406, R407, R408, R409, R410, R411, R413, R414, R415, R417, R419, R420, R421, R422, R424, R502, R505, R601, R602, R603, R604, R702, R903, R904, R905, R908, R909, R910, R1104, R1201, R1205, R1218, R1302, R1305, R1402, R1403 | 42 | 100k | Resistor_SMD:R_0805_2012Metric
30 | R102, R815, R1015 | 3 | 1k | Resistor_SMD:R_0805_2012Metric
31 | R201, R203, R204, R206, R208, R209, R210, R211, R212, R301, R303, R304, R306, R308, R309, R310, R311, R312, R506, R507, R509, R1306, R1307, R1309 | 24 | 30k | Resistor_SMD:R_0805_2012Metric
32 | R202, R302, R416, R423 | 4 | 390k | Resistor_SMD:R_0805_2012Metric
33 | R205, R305, R706, R801, R803, R804, R806, R808, R810, R811, R813, R814, R911, R1001, R1003, R1004, R1006, R1008, R1010, R1011, R1013, R1014, R1101, R1219, R1220, R1221, R1224 | 27 | 10k | Resistor_SMD:R_0805_2012Metric
34 | R207, R213, R307, R313, R503, R508, R1303, R1308 | 8 | 270 | Resistor_SMD:R_0805_2012Metric
35 | R412, R426 | 2 | 18k | Resistor_SMD:R_0805_2012Metric
36 | R418, R425, R1212 | 3 | 220k | Resistor_SMD:R_0805_2012Metric
37 | R501, R1301 | 2 | 10M | Resistor_SMD:R_0805_2012Metric
38 | R504, R901, R902, R906, R907, R1304 | 6 | 4k7 | Resistor_SMD:R_0805_2012Metric
39 | R701 | 1 | 150k | Resistor_SMD:R_0805_2012Metric
40 | R703, R705, R1214 | 3 | 22k | Resistor_SMD:R_0805_2012Metric
41 | R704, R1102, R1204 | 3 | 2M2 | Resistor_SMD:R_0805_2012Metric
42 | R802, R805, R809, R812, R1002, R1005, R1009, R1012 | 8 | 200 | Resistor_SMD:R_0805_2012Metric
43 | R807, R1007 | 2 | 51k | Resistor_SMD:R_0805_2012Metric
44 | R816, R1016 | 2 | 12k | Resistor_SMD:R_0805_2012Metric
45 | R817, R1017 | 2 | 56k | Resistor_SMD:R_0805_2012Metric
46 | R1103 | 1 | 68k | Resistor_SMD:R_0805_2012Metric
47 | R1105 | 1 | 270k | Resistor_SMD:R_0805_2012Metric
48 | R1202, R1206, R1217 | 3 | 1M | Resistor_SMD:R_0805_2012Metric
49 | R1203, R1207, R1208 | 3 | 200k | Resistor_SMD:R_0805_2012Metric
50 | R1209 | 1 | 2k 3300ppm/C PTC | Resistor_THT:R_Axial_DIN0207_L6.3mm_D2.5mm_P10.16mm_Horizontal
51 | R1210 | 1 | 110k | Resistor_SMD:R_0805_2012Metric
52 | R1211 | 1 | 330 | Resistor_SMD:R_0805_2012Metric
53 | R1213 | 1 | 15k | Resistor_SMD:R_0805_2012Metric
54 | R1215 | 1 | 5k6 | Resistor_SMD:R_0805_2012Metric
55 | R1216 | 1 | 47k | Resistor_SMD:R_0805_2012Metric
56 | R1222 | 1 | 2k2 | Resistor_SMD:R_0805_2012Metric
57 | R1223 | 1 | 6k8 | Resistor_SMD:R_0805_2012Metric
58 | R1225 | 1 | 470k | Resistor_SMD:R_0805_2012Metric
59 | R1401 | 1 | 3k9 | Resistor_SMD:R_0805_2012Metric
60 | RV201, RV301, RV401, RV402, RV403, RV404, RV405, RV406, RV601, RV701, RV1101 | 11 | 100k | Potentiometer_THT:Potentiometer_Alpha_RD901F-40-00D_Single_Vertical
61 | RV407, RV602 | 2 | 100k c.d. | Potentiometer_THT:Potentiometer_Alpha_RD901F-40-00D_Single_Vertical
62 | RV408, RV410, RV1201, RV1202, RV1206 | 5 | 100k | Potentiometer_THT:Potentiometer_Bourns_3296W_Vertical
63 | RV409, RV411 | 2 | 5k | Potentiometer_THT:Potentiometer_Bourns_3296W_Vertical
64 | RV901, RV902, RV903, RV904, RV1204, RV1205 | 6 | 10k | Potentiometer_THT:Potentiometer_Bourns_3296W_Vertical
65 | RV1203 | 1 | 100 | Potentiometer_THT:Potentiometer_Bourns_3296W_Vertical
66 | SW1, SW2, SW4 | 3 | SR1712F-0204 | custom_footprints:SR1712F_rotary_switch
67 | SW3 | 1 | series_parallel_switch | custom_footprints:DPDT_mini_toggle
68 | SW5 | 1 | delay_bypass_switch | custom_footprints:SPDT_mini_toggle
69 | SW401 | 1 | SW_SPDT_MSM | custom_footprints:SPDT_mini_toggle
70 | SW1201 | 1 | SW_DP_on_on_on | custom_footprints:DPDT_mini_toggle
71 | TP101 | 1 | DRY | TestPoint:TestPoint_Keystone_5000-5004_Miniature
72 | TP102 | 1 | CV_A | TestPoint:TestPoint_Keystone_5000-5004_Miniature
73 | TP103 | 1 | ENV_VCA | TestPoint:TestPoint_Keystone_5000-5004_Miniature
74 | TP104 | 1 | VCF_A | TestPoint:TestPoint_Keystone_5000-5004_Miniature
75 | TP105 | 1 | DELAY | TestPoint:TestPoint_Keystone_5000-5004_Miniature
76 | TP106 | 1 | CV_B | TestPoint:TestPoint_Keystone_5000-5004_Miniature
77 | TP107 | 1 | FINAL_AUDIO | TestPoint:TestPoint_Keystone_5000-5004_Miniature
78 | TP108 | 1 | VCF_B | TestPoint:TestPoint_Keystone_5000-5004_Miniature
79 | TP601 | 1 | COMPRESSOR | TestPoint:TestPoint_Keystone_5000-5004_Miniature
80 | TP602 | 1 | BBD_LPF_1 | TestPoint:TestPoint_Keystone_5000-5004_Miniature
81 | TP603 | 1 | BBD_LPF_2 | TestPoint:TestPoint_Keystone_5000-5004_Miniature
82 | TP901 | 1 | BBD_1 | TestPoint:TestPoint_Keystone_5000-5004_Miniature
83 | TP902 | 1 | BBD_2 | TestPoint:TestPoint_Keystone_5000-5004_Miniature
84 | TP1201 | 1 | BBD_LPF_CV | TestPoint:TestPoint_Keystone_5000-5004_Miniature
85 | TP1401 | 1 | V+ | TestPoint:TestPoint_Keystone_5000-5004_Miniature
86 | TP1402 | 1 | V- | TestPoint:TestPoint_Keystone_5000-5004_Miniature
87 | TP1403 | 1 | GND | TestPoint:TestPoint_Bridge_Pitch7.62mm_Drill1.3mm
88 | TP1404 | 1 | REF+ | TestPoint:TestPoint_Keystone_5000-5004_Miniature
89 | TP1405 | 1 | REF- | TestPoint:TestPoint_Keystone_5000-5004_Miniature
90 | U1, U2, U4, U5, U6, U7, U8, U9, U13, U17, U18, U19, U23, U24 | 14 | TL072 | Package_SO:SOIC-8_3.9x4.9mm_P1.27mm
91 | U3, U10 | 2 | SSI2164 | Package_SO:SOIC-16_3.9x9.9mm_P1.27mm
92 | U11 | 1 | NE570 | Package_DIP:DIP-16_W7.62mm_Socket
93 | U12, U16 | 2 | SSI2140 | Package_SO:TSSOP-20_4.4x6.5mm_P0.65mm
94 | U14, U15 | 2 | MN3005 | custom_footprints:DIP-8-14_W7.62mm_Socket
95 | U20 | 1 | LM331 | Package_DIP:DIP-8_W7.62mm_Socket
96 | U21 | 1 | 4013 | Package_SO:SOIC-14_3.9x8.7mm_P1.27mm
97 | U22 | 1 | CD4049 | Package_SO:TSSOP-16_4.4x5mm_P0.65mm
98 | U1407 | 1 | LM4040DBZ-5 | Package_TO_SOT_SMD:SOT-23

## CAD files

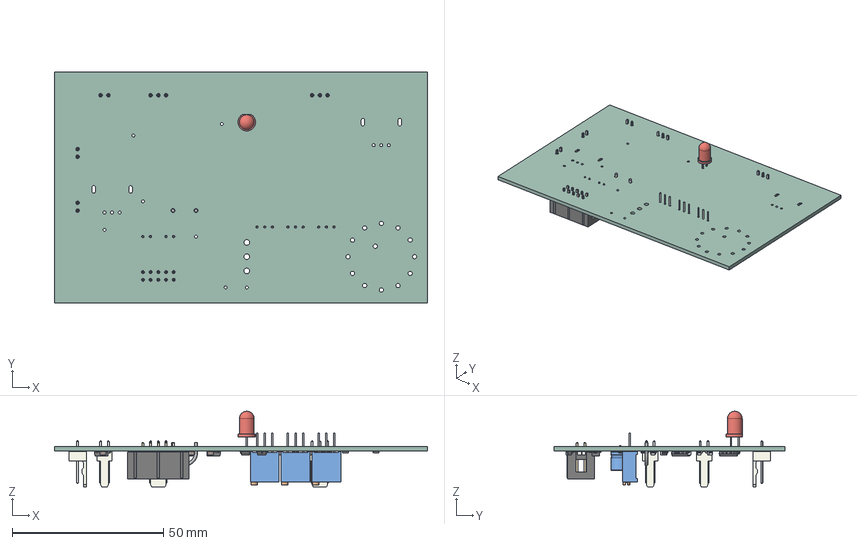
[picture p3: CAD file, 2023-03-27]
circuit_boards/mod_osc_board/docs/3D/mod_osc_board.step
123.2 x 76.2 x 25.0 mm
PCB

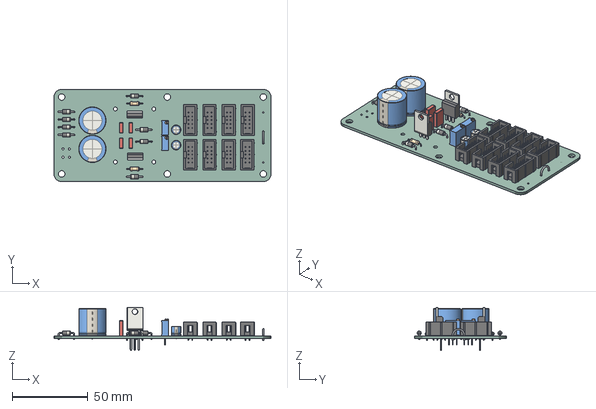
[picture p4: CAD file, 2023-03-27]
circuit_boards/power_supply_board/docs/3D/power_supply.step
143.5 x 61.0 x 28.5 mm
PCB

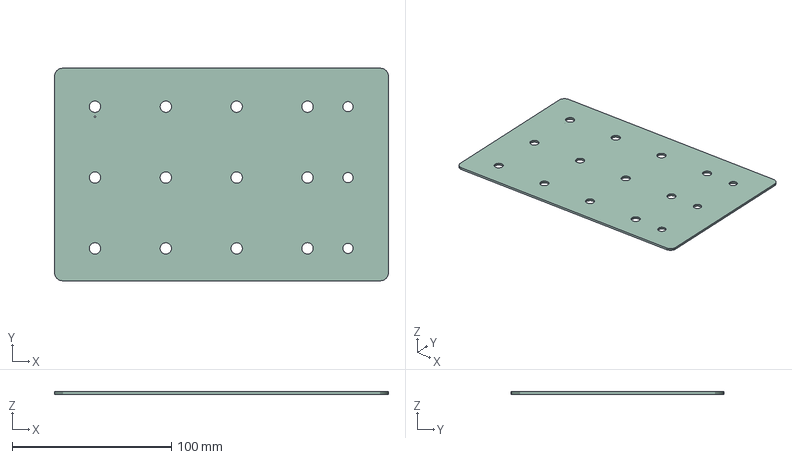
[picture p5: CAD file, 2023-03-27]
panel/ADSR_pcb_panel/docs/3D/ADSR_pcb_panel.step
209.6 x 133.4 x 1.58 mm

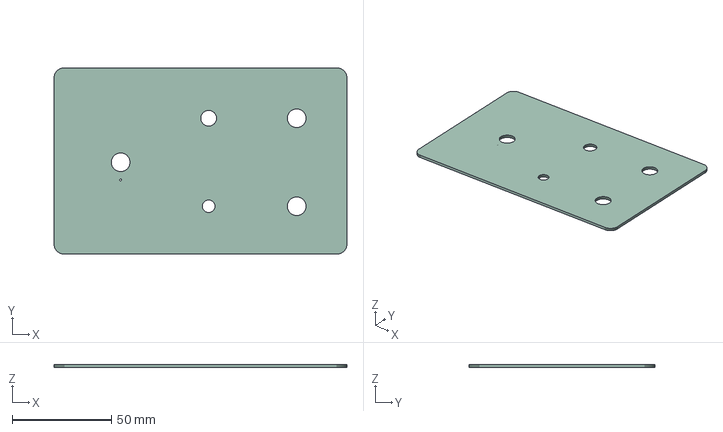
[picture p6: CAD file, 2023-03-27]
panel/mod_osc_pcb_panel/docs/3D/mod_osc_pcb_panel.step
148.0 x 94.0 x 1.58 mm

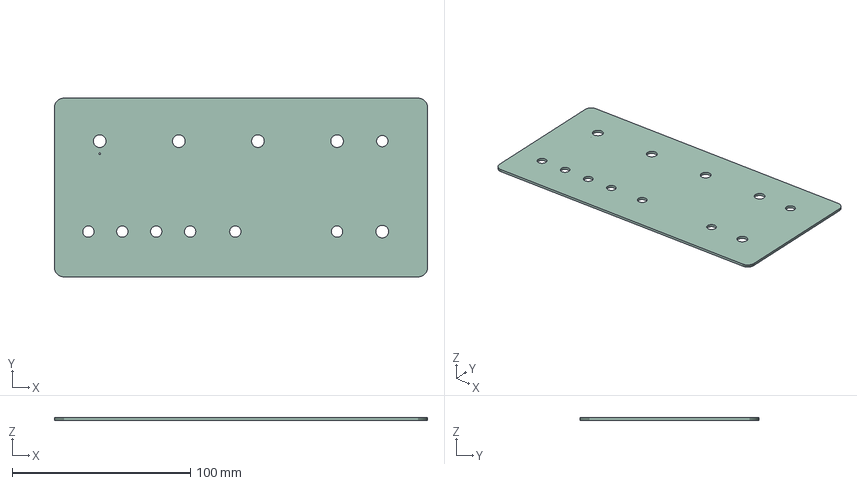
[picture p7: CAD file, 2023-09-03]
panel/ribbon_pcb_panel/docs/3D/ribbon_pcb_panel.step
209.6 x 100.3 x 1.58 mm

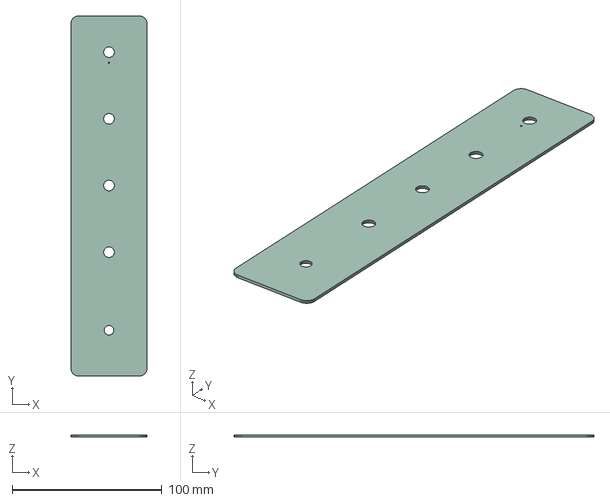
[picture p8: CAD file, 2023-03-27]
panel/s_and_h_pcb_panel/docs/3D/s_and_h_pcb_panel.step
50.8 x 240.0 x 1.58 mm

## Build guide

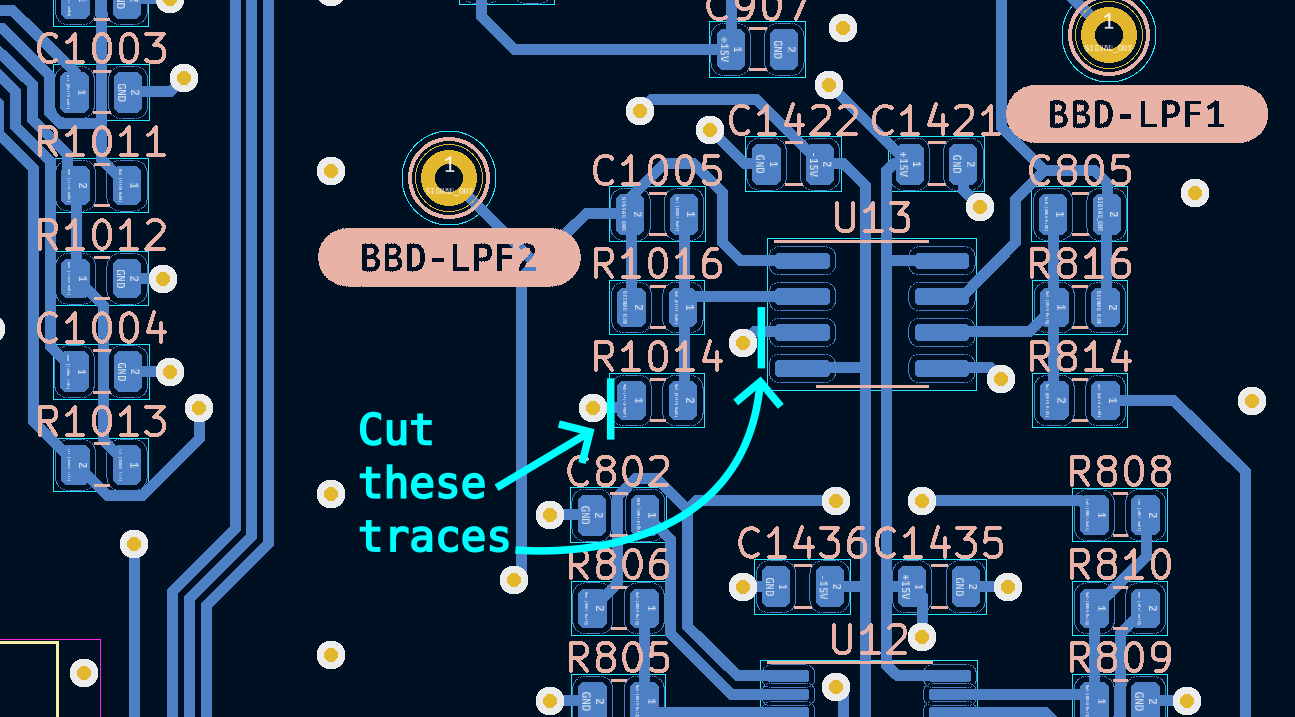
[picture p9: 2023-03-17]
circuit_boards/VCF_VCA_BBD_board/pcb_kludges/images/opamp_step_1.png

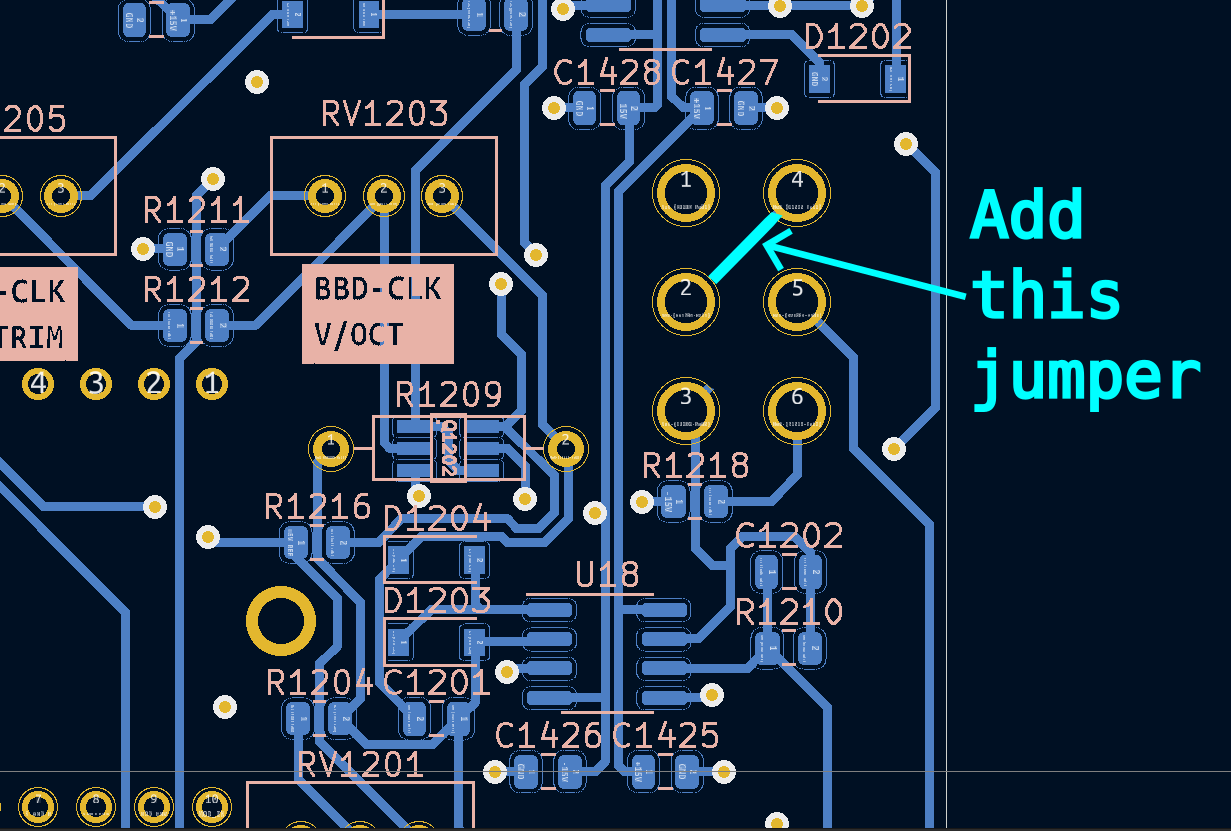
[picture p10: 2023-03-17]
circuit_boards/VCF_VCA_BBD_board/pcb_kludges/images/switch_step_3.png

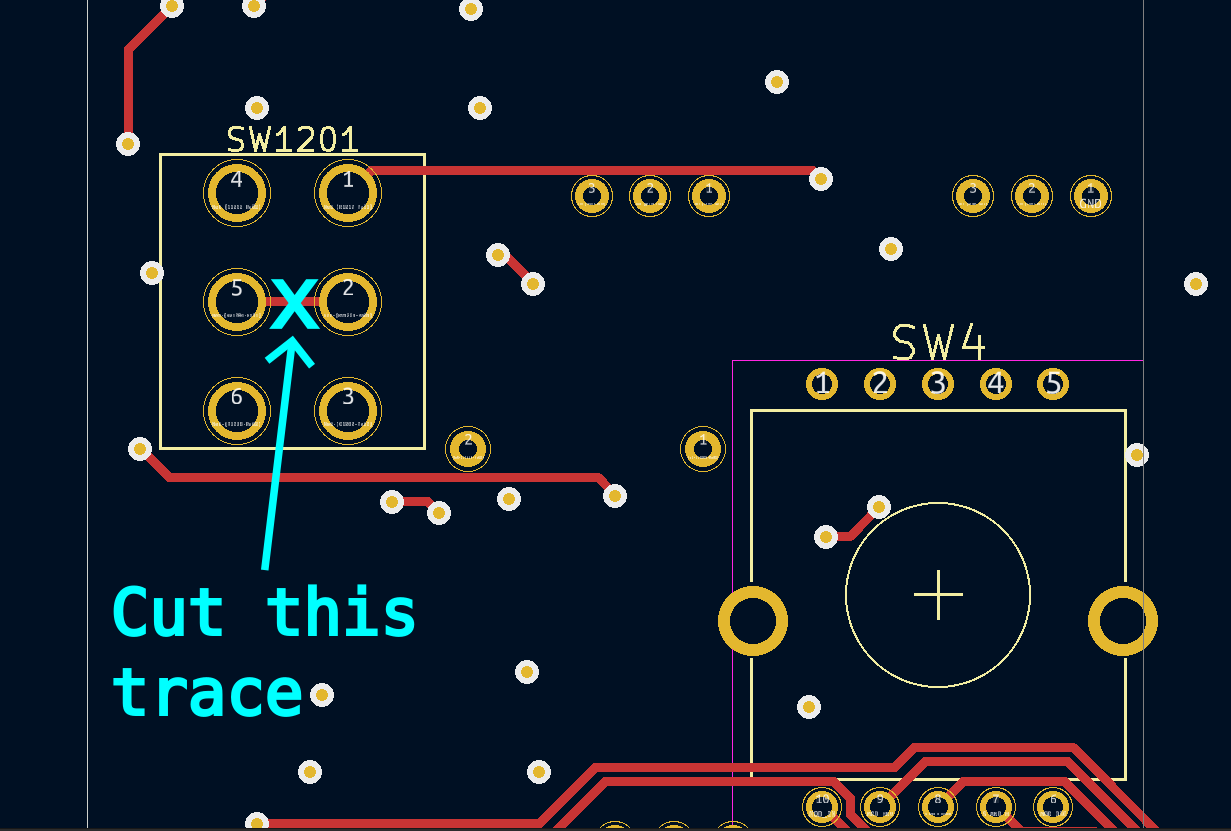
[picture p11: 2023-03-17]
circuit_boards/VCF_VCA_BBD_board/pcb_kludges/images/switch_step_1.png

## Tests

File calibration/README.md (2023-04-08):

# Calibration Instructions

The steps below outline how to calibrate the instrument.

These instructions assume some familiarity with synthesizer calibration and access to test gear such as multimeters, oscilloscopes, frequency counters, and audio amplifiers for listening.

To calibrate the 1 volt per octave response of the VCO, Mod Osc, and VCF you can either use the calibrated ribbon controller in `QUANTIZE` mode or use external gear capable of providing a calibrated 1v/oct signal. This could be a CV sequencer or keyboard.

These are not exhaustive, step-by-step instructions, but it should be enough to get you going if you know what you're doing.

Be aware that there is mains voltage inside the synth, keep away from the IEC power inlet, fuse holder, and power switch.

---

## Accessing the electronics

The easiest way to access the inside of the instrument for calibration, repairs, or mods is to remove the wooden **bottom** cover. Leave the front panel attached to the wooden frame.

Once the bottom cover is off, I usually set the instrument on its side so that it sticks up in the air tall-ways. This makes it easier to access the front panel controls, jacks, and circuitboards all at the same time. It makes calibration easier if you can tweak the front panel controls as you adjust the internal trim potentiometers.

---

## Power Supply Board

**GOAL:** Provide +15.00 and -15.00 volts DC to the rest of the system

The power supply board must be calibrated first thing, before any other circuit board calibration is attempted.

1. Apply 120VAC mains power to the IEC jack and turn the power switch ON
2. Clip the black lead of a multimeter to the `GND` test point
3. Monitor the `V+` test point with the red lead of the multimeter and adjust `RV1` for +15VDC
4. Do the same process with the `V-` test point and adjust `RV2` for -15VDC

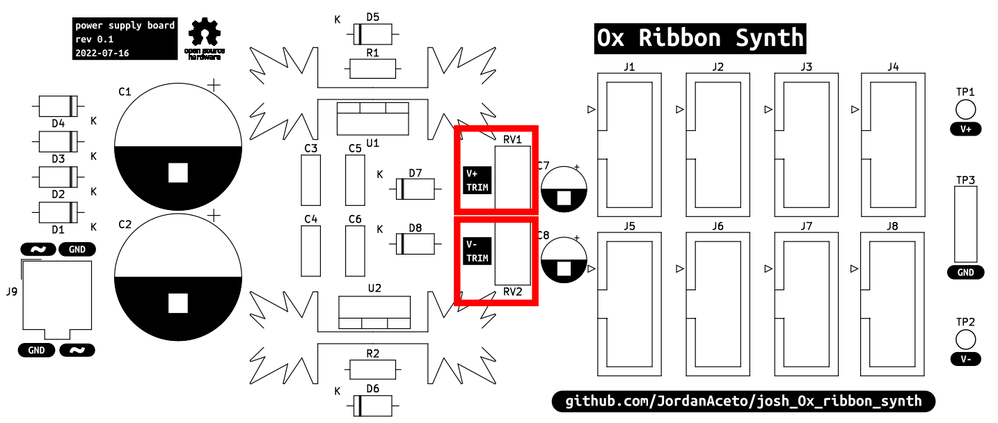
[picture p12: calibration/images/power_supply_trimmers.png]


---

## Ribbon board

**GOAL:** Adjust the ribbon controller so that octaves are 1.000 volts apart

There are three ribbon outputs to calibrated:
1. Main VCO ribbon control
2. MODOSC ribbon control
3. VCF ribbon control
4. There is a 4th ribbon `AUX CTL`, currently unused

To calibrate the VCO control:
1. Turn the front panel `VCO` attenuator on the Ribbon front panel all the way clockwise
2. Set the front  panel `RIBBON MODE` switch to `QUANTIZE`
3. Slide your finger to the lowest point on the ribbon
4. Measure the voltage at the `VCO CTL` output, either on the Molex header or the small test point near the `VCO CTL` trimmer
5. This should be a very small voltage near 0.000, jot down the measured voltage as DELTA. If it is closer to 0.08 volts, make sure you're pressing at the lowest point of the ribbon
6. Slide your finger to the highest note on the ribbon
7. Adjust the `VCO CTL` trimmer until you measure (4.000 + DELTA) volts DC

Repeat these steps for the `MODOSC CTL` and `VCF CTL` trimmers
- Note that only the VCO ribbon signal is quantized, so expect more drifiting and variation from the MODOSC and VCF ribbon signals
- The VCO control is the most important. For the MODOSC and VCF just get them "good enough"
- Ignore the `AUX CTL` trimmer, unless you have added some functionality of your own

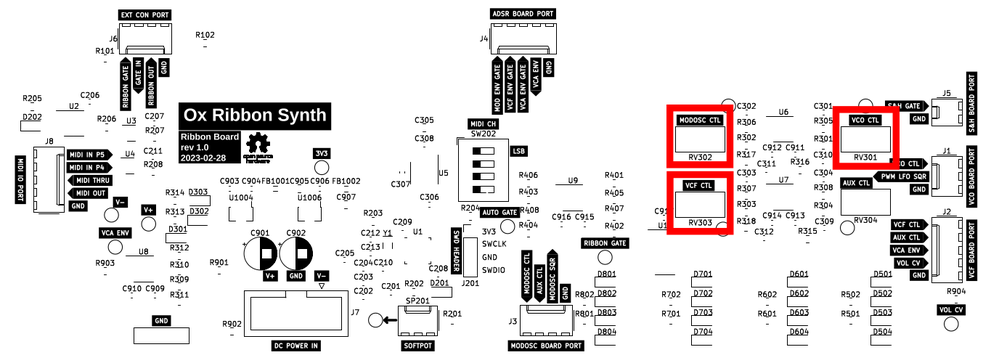
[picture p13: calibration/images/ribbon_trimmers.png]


---

## Main VCO Board

This board has a **lot** of trimmers, but it is less scary than it looks.

There are three main calibration groups:
- 1 volt per octave and tuning related calibration
- Suboscillator waveshape calibration
- Ring modulator reject calibration

Of these, the tuning calibration is the most important, the waveshape trimming is a matter of taste, and the ring-mod calibration can be ignored with no ill effect.

### VCO tuning calibration

**GOAL:** Trim the VCO to play in tune when fed with 1volt/octave CV sources

There are three trimmers relating to tuning:
- `BASE TRIM` sets the base frequency for the VCO
- `SCALE TRIM` sets the 1 volt per octave scaling
- `H.F. TRIM` compensates for high frequency tuning errors

To calibrate the VCO tuning:
1. Turn all VCO modulation controls to zero
2. Use the calibrated ribbon controller set to `QUANTIZE` mode or inject a 1 volt per octave signal into the `VCO CV IN` jack
3. Monitor the VCO signal with a frequency counter and/or audio amplifier
    - the `MAIN OSC` test point is a convenient place to grab the signal
    - alternately use the main output jack and set the VCF and VCA to allow signal through
4. Instead of rewriting existing instructions, refer to the [SSI2130 datasheet](https://www.soundsemiconductor.com/downloads/ssi2130datasheet.pdf) calibration section, on page 12.

If you have calibrated VCO tuning before, you can largely ignore the instructions above and "wing it", calibration should be relatively straightforward.

Note that if you intend to only use the instrument with the built in ribbon controller, then VCO tuning is largely irrelevant. Just adjust it so that the range feels good to you.



### Suboctave calibration

**GOAL:** Trim the suboctaves for clean waveforms and minimal glitches

The two suboctave circuits each have several trimmers for calibrating the waveshapes. These trimmers are largely identical between Suboctave 1 and Suboctave 2, except that Suboctave 2 has an extra trimmer for calibrating the special pulse wave.

Note that the suboctave waveshapes are derived from the original sawtooth by adding pulses, full wave rectifying, and distorting the signal. The resulting waveshapes are relatively clean, but expect some glitches and discontinuities in the waveshapes. Adjust the trimmers to the best of your ability, but don't expect perfection and trust your ears.

Suboctave 1 calibration procedure:
1. Monitor the `SUBOCT 1` test point with an oscilloscope
2. Turn Suboctave 1 to the "-0 octave" position (same octave as the main VCO)
3. Set the Suboctave 1 waveshape switch to `SAWTOOTH`
4. Adjust the trimmers labeled `(1)` and `(2)` in the image below for the cleanest sawtooth
5. Set the Suboctave 1 waveshape switch to `TRIANGLE`
6. Adjust the trimmer labeled `(3)` for the cleanest triangle
7. Set the Suboctave 1 waveshape switch to `SINE`
8. Adjust trimmers `(4)` and `(5)` for the cleanest sine wave



Suboctave 2 calibration:
1. Steps `1` through `8` are identical to suboctave 1, using the trimmers indicated below
2. Set the Suboctave 2 waveshape switch to `PULSE`
3. Adjust trimmer `(6)` so that the tops of the pulse train all line up



### Ring modulator calibration

**GOAL:** Minimize ring modulator bleedthrough

I personally do not bother with this calibration, and in fact I do not even install the two ring-mod trimmers. This is not a precise balanced modulator, but rather a clangorous noise maker.

But if you wish to improve the dry signal bleedthrough of the ring mod, you can adjust the trimmers indicated below.

To do this you will need to kill the signal to each input one at a time while monitoring the output. It will be an iterative process to find trimmer settings with the least signal bleedthrough when only one signal is present. Or adjust them until it sounds good to you, or ignore them completely. IMO it sounds good no matter what you do here.



---

## Mod OSC Board

**GOAL:** Trim the MODOSC VCO to play in tune when fed with 1volt/octave CV sources

The Modulation Oscillator uses the same VCO core as the main VCO, and the tuning calibration is identical except that the frequency range goes lower.

See the [SSI2130 datasheet](https://www.soundsemiconductor.com/downloads/ssi2130datasheet.pdf) page 12 again for calibration instructions, or use your ears and a tuner. You can inject an external CV signal into the `MOD OSC CV IN` jack or use the calibrated ribbon controller.

The Mod Osc is intended primarily for modulation duties, and precise tuning is not as critical as the main VCO.

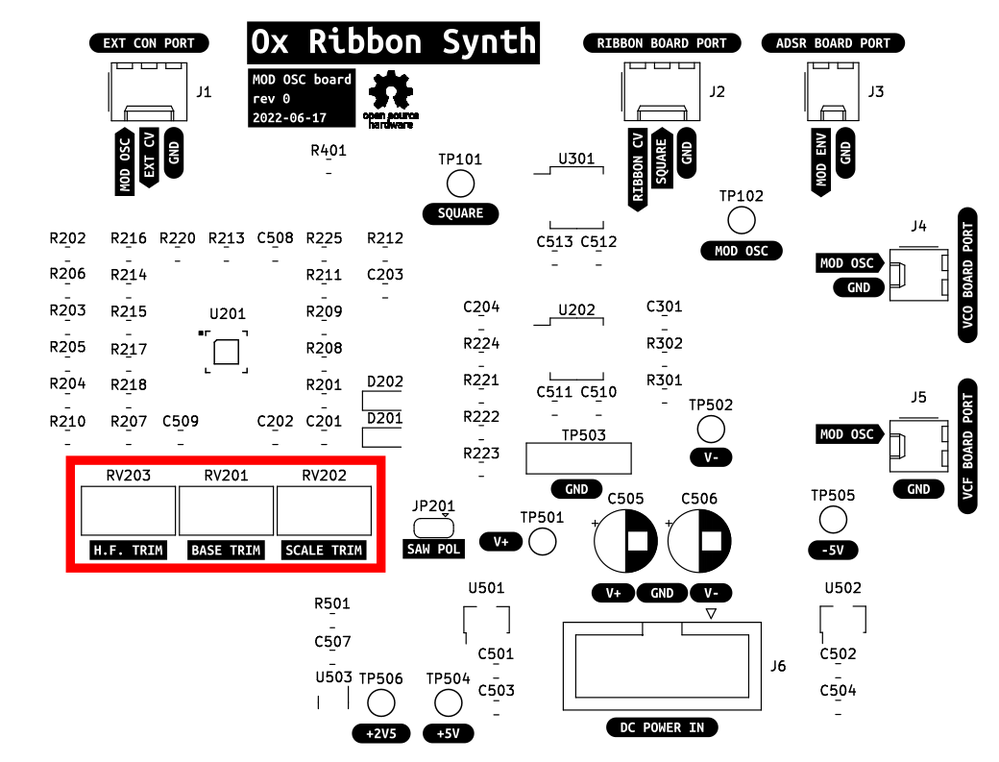
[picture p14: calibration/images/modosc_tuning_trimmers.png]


---

## VCF/VCA/BBD board

The dual VCF has a couple of trimmers for calibration. The VCA does not require any calibration. The BBD analog delay has many trimmers, but several of them are not necessary to obsess over. 

### VCF tuning calibration

**GOAL** Trim the filters to play in tune when fed with 1volt/octave CV sources

1. Set the `SERIES/PARALLEL` switch to `PARALLEL` operation
2. Turn all audio sources (VCO, ring-mod, noise, etc) all the way off
3. Turn the VCF A resonance up until it self oscillates, and turn the VCF B resonance control all the way down
4. Inject a CV signal into the `VCF CV IN` jack or use the calibrated ribbon controller as the control voltage source
5. Monitor the self oscillating VCF with an audio amplifier/frequency counter/tuner
6. Adjust the `1V/OCT A TRIM` so that the self oscillating signal plays roughly in tune
7. Repeat this process for VCF B

Note that the tuning probably won't be as good as the VCO. Just get it in the ballpark, don't go crazy.

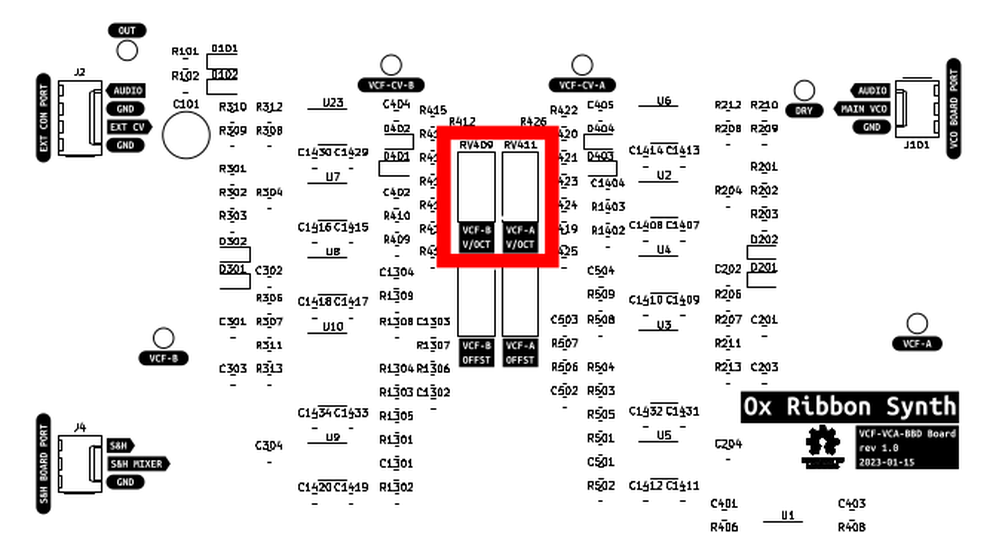
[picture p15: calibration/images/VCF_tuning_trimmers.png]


### VCF base frequency calibration

**GOAL** Adjust the filters so that the base frequency when the controls are turned all the way down feels good to the user

This calibration is largely a matter of taste. Here is what I do:

1. Adjust the VCO to be around 30Hz
2. Set the VCO waveshape to `PULSE`
3. Send just the main VCO into the VCF via the audio mixer
4. Set both VCF A and VCF B to lowpass mode
6. Turn the VCF Manual Frequency control fully CCW, set the Separation control to 12 o'clock
5. Adjust the `BASE FREQ n TRIM` trimmers such that the audio is *just barely* silenced
6. Sweep the VCF frequency control around a bit with various input signals and see if it feels good, if not tweak the `BASE FREQ n TRIM` trimmers

Once the VCF tuning and base frequency are roughly trimmed, I go back and make sure that they track well together and are very close to the same frequency when the Separation control is at 12 o'clock. 

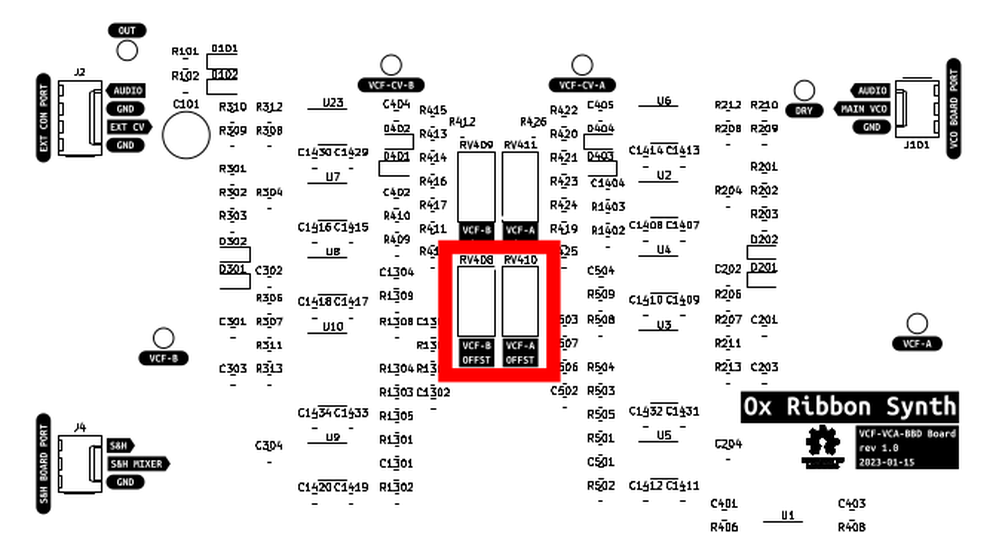
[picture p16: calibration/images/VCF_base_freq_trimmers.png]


### BBD bias calibration

**GOAL** Maximize BBD headroom

The analog delay chips may be biased for maximum headroom. This is a matter of taste, and you may prefer the sound of more asymmetric distortion.

1. Set the delay time somewhere between 10 o'clock and 1 o'clock, it is not critical exactly where
2. Set the delay repeats all the way down
3. Set the VCO waveshape to `SINE` or `TRIANGLE`
4. Send just the main VCO into the VCF via the audio mixer
5. Set both VCF A and VCF B to lowpass mode, frequency all with way up and resonance all the way down
6. Monitor the signal at the `BBD-1` test point
7. Experiment with turning the level of the VCO up and down, and adjusting the `BBD-1 BIAS` trim pot
8. At some points you should see asymmetric clipping on either the top or bottom of the waveform
9. Adjust the `BBD-1 BIAS` trimpot to allow the largest possible input signal through without clipping
10. Do some listening tests with various settings, trust your ears
11. Repeat for BBD 2

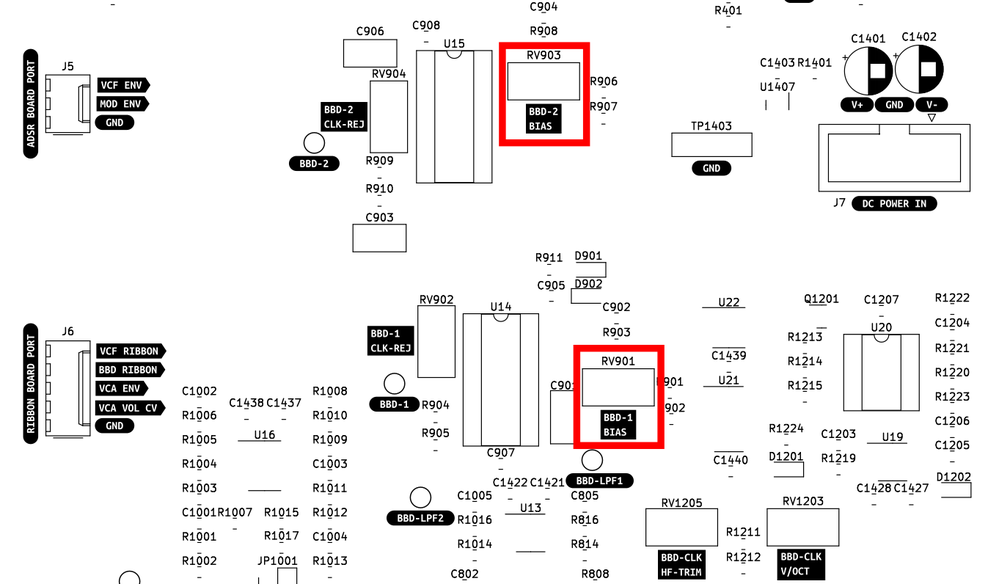
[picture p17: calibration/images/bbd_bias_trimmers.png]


### BBD clock reject calibration

**GOAL** Minimize BBD clock bleedthrough

The analog delay has trimmers to reject clock frequencies from bleeding into the audio. This is one you want to get right, but it is not hard.

Note that this delay design intentionally pushes the delay time past what is reasonable for this kind of circuit. It is intended that at maxumum delay time there will be aliasing and noise introduced for gritty and unusual sounds. If you need to compromise on minimizing bleedthrough over some range, favor making the bottom 2/3 of the delay time knob sound good. The far clockwise end of the delay time knob is for crazy time.

1. Turn off all audio signals going into the VCF board
2. Set the delay time to somewhere between 1 o'clock and maximum
3. Turn the delay repeats all the way down
4. Turn the delay mix fully clockwise
5. Set the `LPF MODE` switch to `BRIGHT`
6. Set the delay `BYPASS` switch to `ON`
7. Listen to the main output jack with an audio amplifier
8. With enough volume you will probably hear an annoying high pitched sound that changes pitch when you adjust the delay time control, this is the BBD clock bleeding into the audio path
9. Adjust the `BBD-n CLK-REJ` trimmers to minimize the bleedthrough, this may be iterative, so go back and forth between them to get the noise as low as possible
10. Sweep the delay time up and down to make sure the bleedthrough doesn't have any trouble spots at certain frequencies
11. You can also monitor this signal with an oscilloscope, I find it easier to minimize by ear but a scope can help to verify things

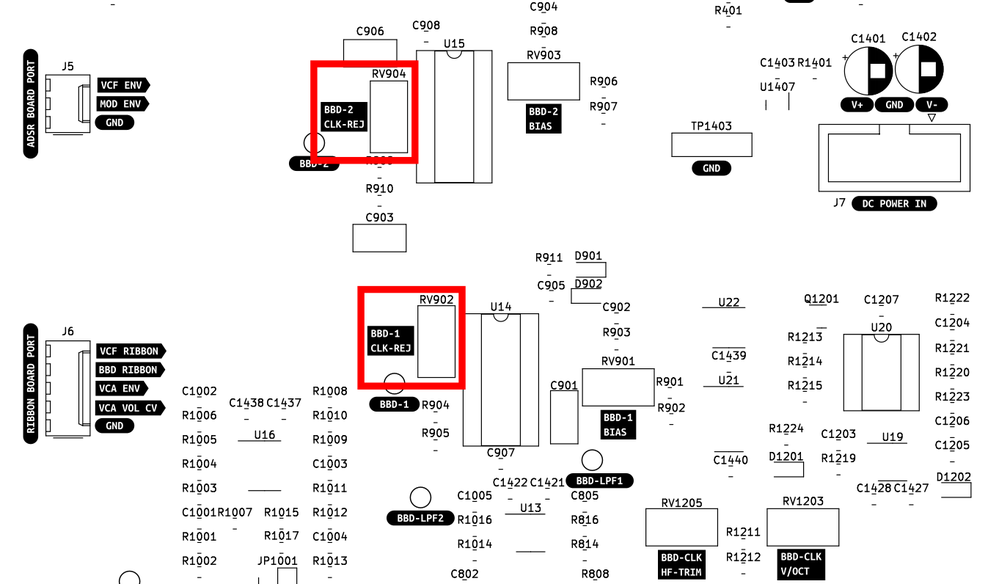
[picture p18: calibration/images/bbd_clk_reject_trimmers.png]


### BBD clock scaling

**GOAL** Trim the BBD clock to have a nice range for the user

The analog delay has a complex clock circuit, allowing for 1volt/octave scaling. However, this complexity is somewhat wasted. There is no great reason to calibrate for good tracking. What matters is that the range of the delay time feels good to the user.

The `BBD-CLK HF-TRIM` is an optional high-frequency compensation circuit, this can be ignored completely.

If you hack the instrument to somehow respond to 1volt/octave delay control, then adjust these trimmers to get the delay as in-tune as possible. But otherwise don't worry about them too much.

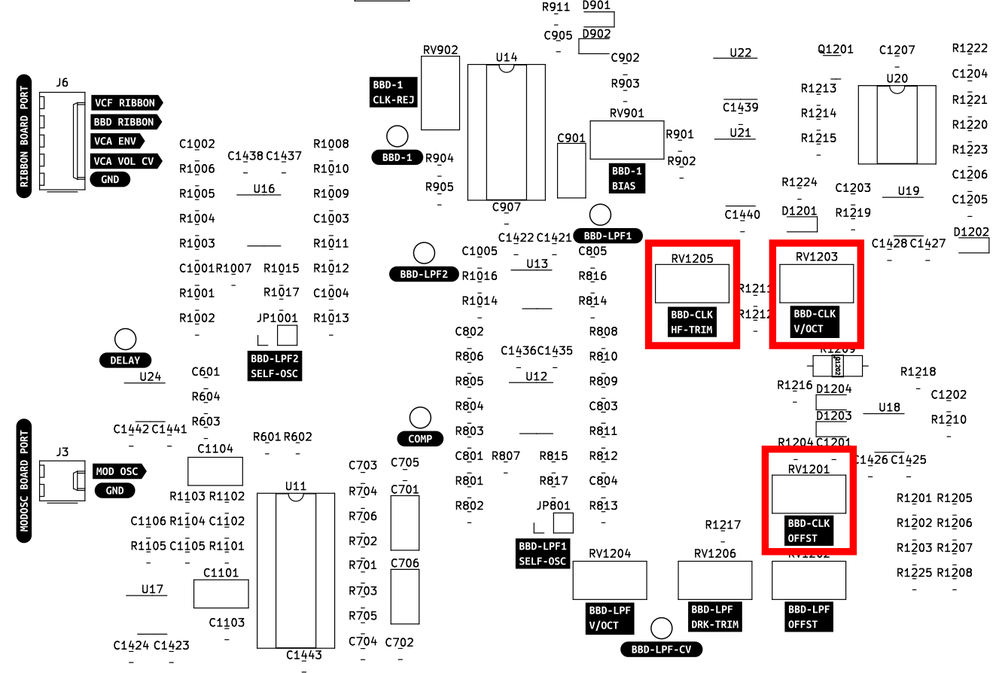
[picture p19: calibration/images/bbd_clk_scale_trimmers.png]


### BBD LPF scaling

**GOAL** To make the analog delay pre/post lowpass filters track along with the delay clock when the `LPF MODE` switch is in the `TRACK` position

Like the BBD clock, the filtering scheme is a bit too complex for its own good. There are pre and post 24dB/octave tracking lowpass filters which can be calibrated to follow the delay time.

For normal use, it is not important to precisely adjust these trimmers, just tune by ear so it sounds nice in `TRACK` mode.

If you do plan on calibrating for decent 1volt/octave tracking, there are `BBD-LPFn SELF-OSC` jumpers installed which will cause the lowpass filters to self-oscillate when shorted. This allows you to monitor the BBD clock and LPF together to verify that the frequencies track together.

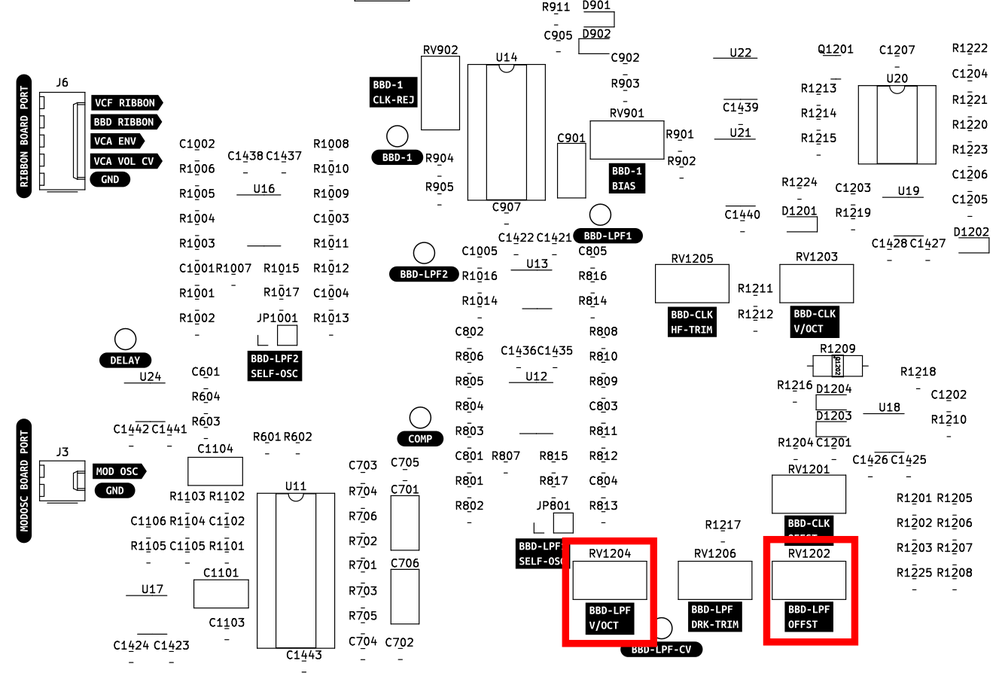
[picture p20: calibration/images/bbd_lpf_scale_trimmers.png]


### BBD LPF dark mode trim

**GOAL** Set the BBD pre/post lowpass filters to a fixed cutoff frequency when the `LPF MODE` switch is in the `DARK` position

This calibration is a matter of taste. Classic analog delay pedals typically had a lowpass frequency of somewhere around 3kHz. 

Either set this trimmer by ear with the `LPF MODE` switch is in the `DARK` position, or short the `BBD-LPFn SELF-OSC` jumpers and verify with a frequency counter.

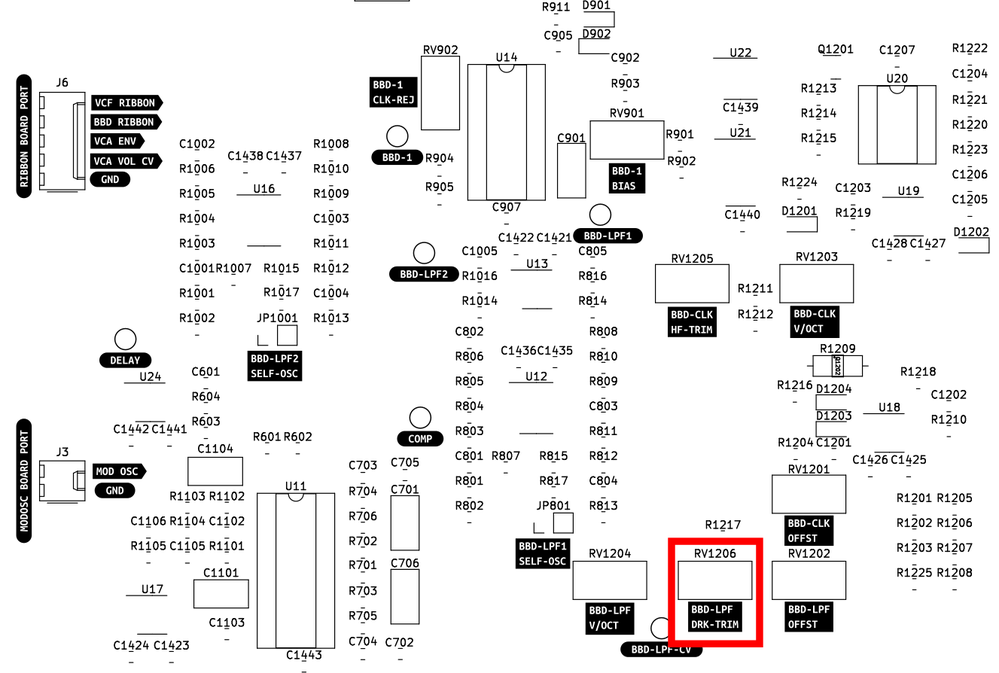
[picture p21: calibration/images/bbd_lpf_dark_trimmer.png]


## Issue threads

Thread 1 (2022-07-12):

Ribbon pcb has no trimmer silkscreen descriptions

JordanAceto, 2022-07-12:
On the Ribbon board, there are two trimmers, but neither has any text on the silkscreen hinting at what they do.

See the other boards for the format used. I've been making little KibBuzzard text blocks near the trimmers.

JordanAceto, 2023-03-17:
New ribbon board has labels.

Closed 2023-03-17.

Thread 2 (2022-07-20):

Main VCO ring mod input switching does not work

JordanAceto, 2022-07-20:
The ring mod on the main VCO board takes two inputs:
- the X input gets a main VCO wave, either octave zero or octave 2 selected by a jumper
- the Y input gets either the Mod Osc, or suboct 1, selected by the panel switch

The problem is, when the suboctaves are turned off via their own panel mount switches, they never make it to the ring mod. D'oh.

This could be fixed in a kludgy way by cutting a couple of PCB traces on the main VCO board and running a couple of jumper wires. This is probably what I'll do for this version.

When/if I ever do a Mark II the ring mod input circuitry should be rethought.

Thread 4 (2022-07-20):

Main VCO linear FM gain is a little low

JordanAceto, 2022-07-20:
On the main VCO board, the Mod Osc can be used as a linear or exponential FM source.

The linear modulation depth feels a little low.

Increase the gain by reducing R402 to about 50k and increasing C401 to 1uF. The C401 footprint will probably be too small with this new value, but it will probably physically fit if you need to kludge it temporarily.

Consider even changing C401 to a much larger value. There are already 10uF bipolar caps in the BOM, maybe just use one of those.

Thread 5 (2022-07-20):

Suboctave 2 comparator oscillates on rising edge

JordanAceto, 2022-07-20:
The LM311 comparator for the suboctave 2 saw-animator (U13) has a burst of oscillations on the rising edge, but only when fed from the "1 octave down" setting of switch SW1401.

This does not stop the suboctave from working, and it doesn't even change the sound all that much, but it should be fixed.

In general, I probably need to think a little harder about all the LM311 comparators, and be more careful with the PCB layout.

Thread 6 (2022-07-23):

VCF base freq trim has too wide range

JordanAceto, 2022-07-23:
The base frequency trimmers on the VCF/VCA board set the base frequency for the two VCFs.

The range of these trimmers is a little wider than it needs to be, and when the filters are calibrated the trimmers end up near the far end of their travel

Rethink these trimmers so that the filters are resting at about 10Hz when they are in the middle of their range and the manual frequency pot is turned all the way down, and make it so they have a range of no more than 1.5 octaves or so.

Reducing the range will make it easier to get the two filters to have the exact same cutoff frequency when the separation knob is at 12 o'clock.

This is not a major problem, the board works well and calibrates without too much hassle, but this would be an enhancement.

JordanAceto, 2023-03-17:
Tweaked when analog delay added.

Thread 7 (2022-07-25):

VCF notch filter setting sounds lame

JordanAceto, 2022-07-25:
The VCF setup has lowpass, bandpass, highpass, and notch settings, selectable by rotary switch.

The notch setting works properly, but it just isn't that exciting sounding. The dominant reaction to it is "is that what it's supposed to sound like?"

IMO the notch option could just be removed. This would be as easy as installing a 3-throw version of the rotary switch instead of the current 4-throw version. This could save a dual opamp if a pcb revision happens too.

Alternately, you could think of ways to spice up the notch. Maybe adding a little bit of dry signal would give it more of a phase shifter sound?

JordanAceto, 2022-07-27:
Note: after speaking with Ox, he agrees that it isn't super impressive sounding, but wants to keep it for teaching purposes. He sometimes uses this instrument while teaching classes on synthesis, and uses all the filter modes including the notch.

Still, see if there is a way to make it a little juicier sounding while keeping the notch quality for teaching.

JordanAceto, 2023-03-17:
VCF notch setting slightly tweaked when analog delay was added. It's _fine_

Closed 2023-03-17.

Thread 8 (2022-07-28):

main VCO board: noise switch to the audio mixer should be ON-OFF-On with WHITE-OFF-PINK noise

JordanAceto, 2022-07-28:
On the main VCO board, each audio signal going into the audio mixer has a switch to turn it on or off. Most signals use an ON-OFF-On switch to select two versions of the signal, such as the suboctaves which allow you to choose between base octave and -1 octave versions, and the ring-mod which allows you to choose between VCO*Modosc and VCO*VCO.

Right now, the WHITE/PINK noise switch is on the S&H board. But it would be more useful if this switch were moved to the VCO, and changed to the ON-OFF-ON topology as described.

This will require modifying both the S&H board and the main VCO board. The wire headers that connect the S&H and VCO will need an extra wire to carry the pink noise signal.

Whether or not to keep the WHITE/PINK noise switch on the S&H is an open question. I'm somewhat inclined to remove it, but otoh maybe just leave it there as well. The noise is sampled by the S&H, white vs pink doesn't make tons of difference here. But the noise can also modulate the VCO and VCF via the S&H mixer, and white and pink will sound a little different when used directly as modulation sources.

My general plan now is: change the VCO switch to WHITE-OFF-PINK, and add a wire to the headers connecting the VCO and S&H. Leave the WHITE/PINK switch on the S&H board. I could be convinced to change this setup though. Give it some thought.

JordanAceto, 2022-08-19:
Note that Ox has recently requested that the switches go `MODE 1 -> MODE 2 -> OFF`, instead of `MODE 1 -> OFF -> MODE 2`.

There is another open issue about this.

I'm not positive this change will happen, but make sure to coordinate any noise switch changes with broader changes to the switch order.

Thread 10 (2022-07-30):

Master volume and PWM LFO rate potentiometers should be 100k audio taper

JordanAceto, 2022-07-30:
This one is pretty simple, just change the master volume pot (on the ribbon board) and the PWM LFO pot (on the main VCO board) from 100k linear pots to 100k audio taper pots.

This will make the volume and PWM rate knobs feel more gradual. As it is the volume jumps up fast and the PWM rate goes from really-slow to pretty-fast over a very small rotation.

JordanAceto, 2022-08-12:
I replaced the master volume pot on Ox's physical instrument. I'm going to wait to see how he feels about the PWM LFO rate, I'm not 100% sure this one is needed.

JordanAceto, 2023-02-04:
This is a matter of taste. IMO the master volume should be audio taper, and the PWM LFO could go either way, but this is up to preference. I made the master volume audio and the PWM LFO linear in the current instrument. Closing this issue.

Closed 2023-02-04.

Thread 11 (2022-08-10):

Ribbon "bend mode" is not very useful

JordanAceto, 2022-08-10:
The ribbon controller has two modes, select-able with a toggle switch:
- slide more, the "normal" mode where you slide up and down the ribbon
- bend mode, where you "bend up and down" from wherever your finger lands

The bend mode is a little hard to explain, and it also doesn't feel intuitive to use. In practice it feels sort of like a mod-wheel, and could be useful to add vibrato or pitch bend to an existing signal.

But I don't think Ox has ever used it on purpose, and there have been a couple times where the switch was accidentally set to "bend" and it seemed like the ribbon was broken.

IMO the bend mode could be removed. It was a neat idea, but we have not found much musical use for it.

Removing it could simplify the ribbon board by quite a bit, these is a good amount of circuitry devoted to the bend control.

One could also just not install the "slide/bend" switch, and install a small jumper over the switch terminals instead to hardwire slide mode.

Food for thought in case there is a new revision made in the future, but leave it as it is on the current instrument.

JordanAceto, 2023-03-17:
Bend mode removed and quantize mode added with the new digital ribbon.

Closed 2023-03-17.

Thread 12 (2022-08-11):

Ox really wants an integrated analog delay

JordanAceto, 2022-08-11:
When this instrument is used, Ox almost always includes an analog delay pedal in the signal chain. Several times he has requested integrating a delay into the instrument.

I think this is a great idea, the main issue is where to put it.

One idea: compress the VCF panel controls upwards a little bit, and put the analog delay underneath where the VCF FM mixer currently is. I think this could be done in a way that is relatively ergonomic and doesn't look terrible.

In terms of controls, it needs at least:
- delay time
- delay mix
- repeats

But since there is so much modulation available with this instrument, consider adding some modulation capability if there room.

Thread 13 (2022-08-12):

PWM LFO could have a blinky light

JordanAceto, 2022-08-12:
The PWM LFO is used to modulate the pulse width of the main oscillator and sub-oscillators, but it also can be sampled by the S&H, and used as a trigger source for the gate controller.

It would be simple to add a LED which pulsates at the PWM LFO rate. Why not do it if/when a main VCO board rev happens.

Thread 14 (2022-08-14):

ADSR sustain phase could be improved

JordanAceto, 2022-08-14:
With the ADSR design used, if you are holding a note and adjust the sustain control, the sustain level does not follow the knob position.

This is a common way for ADSRs to work, and many commercial instruments share this shortcoming. Many musicians either don't mind this behavior, or don't know that there is an alternative.

Consider upgrading the ADSR board with a design that allows the user to adjust the sustain control in real time, and have the output level quickly follow the sustain knob position when the ADSR is in the sustain phase.

This is easy with digital implementations, but I think we could come up with an analog solution that works as described.

JordanAceto, 2023-03-26:
New ADSR design uses a comparator and analog switch to implement the above behavior.

Closed 2023-03-26.

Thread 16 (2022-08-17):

Mod Osc board uses a different kind of rotary switch and potentiometer

JordanAceto, 2022-08-17:
Most of the boards use alpha SR1712F style rotary switches and alpha RD901F style potentiometers.

The Mod Osc has a 5 position waveform rotary switch. The SR1712F switches don't come in a 5 throw version, so I used an alpha SR2612F style switch instead. Since this kind of switch is taller, I needed to use different potentiometers as well. I used P260T style pots here.

I would prefer it if all the pots and switches were from the same family. The Mod Osc pots and switches have a different amount of mechanical resistance when you turn them compared to all the other boards, and it inflates the BOM.

There are main 2 choices here:
- find a 5 throw rotary switch that is 10mm tall, like the rest of the panel components
- change the Mod Osc waveform select switch to have either 4 or 6 throws, then we can use the SR1712F switches like everywhere else
    - note that going to 6 throws will complicate the switching, as right now I just use the SSI2130 internal mixer

There are a bunch of short rotary switches floating around on aliexpress and similar sites, going under the name `SR16` or `RS16`, maybe this kind of switch would work? I would prefer a name-brand switch that you can get from a standard distributor, but these might work ok.

Investigate a little and think on it.

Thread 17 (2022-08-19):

VCA envelope tails are a bit abrupt

JordanAceto, 2022-08-19:
When the VCA envelope is decaying, the sound does not decay as smoothly as we would like.

This is due to resistor R407 on the VCF/VCA board, which ensures that when zero volts is applied to the CV input, the output signal is completely silenced. It "pushes down" the CV input by a tiny bit.

But if too much current flows through this resistor, it can make the long tails of the volume envelope end abruptly. The final decay doesn't sound as smooth as it should.

Right now the volume pot turns up and down the control voltage that goes to the final VCA. This means when the volume is turned down low, the ADSR signal is small relative to the impact of the "push-down" resistor R407. If instead we always sent the ADSR signal to the VCA CV full-strength, and then attenuated the signal afterwards, I think the un-smooth decay would effect would be reduced.

Since the volume knob is way over on the Ribbon board, we should probably add another VCA just for the master volume. The Ribbon board can send two VCA signals, one is the volume ADSR, and the other is a [0, 5v] master volume control voltage. The final master volume VCA could be exponential control (IE a single SSI216x section plus an opamp), so we can get a nice audio taper from a linear potentiometer on the Ribbon board.

TL;DR add an expo control VCA after the main VCA. The first VCA gets the volume ADSR as a control signal, the final VCA is controlled from the master volume pot.

JordanAceto, 2023-03-26:
The new ADSR and VCA setup fixes this.

Closed 2023-03-26.

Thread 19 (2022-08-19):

VCO audio mixer switches different order

JordanAceto, 2022-08-19:
On the main VCO board, there is a 5 input audio mixer.

Each input can be turned ON/OFF with a toggle switch, and several of the inputs have 3 position switches that go:
- MODE 1
- OFF
- MODE 2

For example, the suboscillators have switches that go:
- the same octave as parent (-0)
- OFF
- minus one octave relative to parent (-1)

For performance reasons, Ox has requested that these switches instead go:
- MODE 1
- MODE 2
- OFF

This way, you can quickly turn a signal OFF by jamming the switch downwards. This is easier to do quickly than setting it to the middle position.

JordanAceto, 2022-08-19:
Note that the FM mixer uses 3 position toggles too. If we change the audio mixer order, we should probably do the FM mixer to for consistency.

JordanAceto, 2023-02-17:
Another sticky point regarding this: The original switch arrangement of `MODE 1 - OFF - MODE 2` allows you to enter any setting from an "off" state.

With the proposed `MODE 1 - MODE 2 - OFF` arrangement, you need to go through `MODE 2` from `OFF` to get to `MODE 1`. If this is an audio or modulation source there will be some discontinuity as the middle position is temporarily engaged on the way to the top position.

IMO the original arrangement has some merit. I personally prefer the middle-off setup. There should be another meeting with Ox to talk about it before deciding anything final.

JordanAceto, 2023-02-17:
Yet another reason to prefer center off: The second suboctave generator gets its input from the last "on" state of the first one.

Meaning, if  `SUBOCT1` is in `-0` or moved to `OFF` from `-0` mode, then `SUBOCT2` will get its input from the undivided `SUBOCT1`. This means that `SUBOCT2` can be either the same base octave or one octave lower than the main oscillator.

But if `SUBOCT1` is in `-1` or moved to `OFF` from `-1`, then `SUBOCT2` will get its input from the already divided `SUBOCT1`. This means that `SUBOCT2` can be either one octave lower or two octaves lower than the main

If we put the `OFF` position downwards, then `SUBOCT2` will **always** get the divided `SUBOCT1` output when `SUBOCT1` is turned **off**. We can't make `SUBOCT2` the same base frequency of the main oscillator when `SUBOCT1` is turned off. This seems like a pretty bad situation to me.

That's a lot of confusing talk to say "if we put the `OFF` position downwards, some useful actions are impossible to do".

JordanAceto, 2023-03-17:
New twist: Ox has suggested small LEDs near each of the audio attenuators to show you which signals are on and off.

These would light up when a signal is on. For signals with two "ON" settings (`RING MOD XX, RING MOD XY`. etc) it could either be a two color red/green LED, or two individual LEDs.

This solves the problem of not being able to easily tell which signals are on while letting us keep the original switch order. Food for thought as we continue to hash out the ideal main VCO board layout.

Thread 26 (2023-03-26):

VCF/VCA/BBD board needs a couple of kludges

JordanAceto, 2023-03-26:
See the [pcb kludges document for the VCF board](https://github.com/JordanAceto/josh_Ox_ribbon_synth/tree/master/circuit_boards/VCF_VCA_BBD_board/pcb_kludges)

If a board revision happens, fix these relatively small issues.

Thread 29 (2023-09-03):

Change ribbon GLIDE control to ribbon DELAY control

JordanAceto, 2023-09-03:
Ox wants to add back in the ribbon signal that controls the Analog Delay.

This means removing the ribbon GLIDE control, which Ox is fine with. The potentiometer position on the RIBBON board that was the GLIDE control can now become the DELAY

On the ribbon PCB there is an AUX RIBBON signal, this will become the DELAY control signal.

Only the physical ribbon front panel needs to be changed, the rest of the changes are either code or schematic only.

1. change the ribbon front panel silkscreen, the rightmost knob changes from GLIDE to DELAY
2. edit the code, remove glide related stuff and add in delay control
3. in the ribbon board schematic, change the GLIDE pot to DELAY pot, and make it center detent (don't need to change the gerbers)
4. On the physical instrument, add a wire from the ribbon board header to the VCF/VCA/BBD board header
5. On the physical instrument, change the new DELAY pot to center detent

JordanAceto, 2023-09-17:
Done in v0.2.1-beta

Closed 2023-09-17.

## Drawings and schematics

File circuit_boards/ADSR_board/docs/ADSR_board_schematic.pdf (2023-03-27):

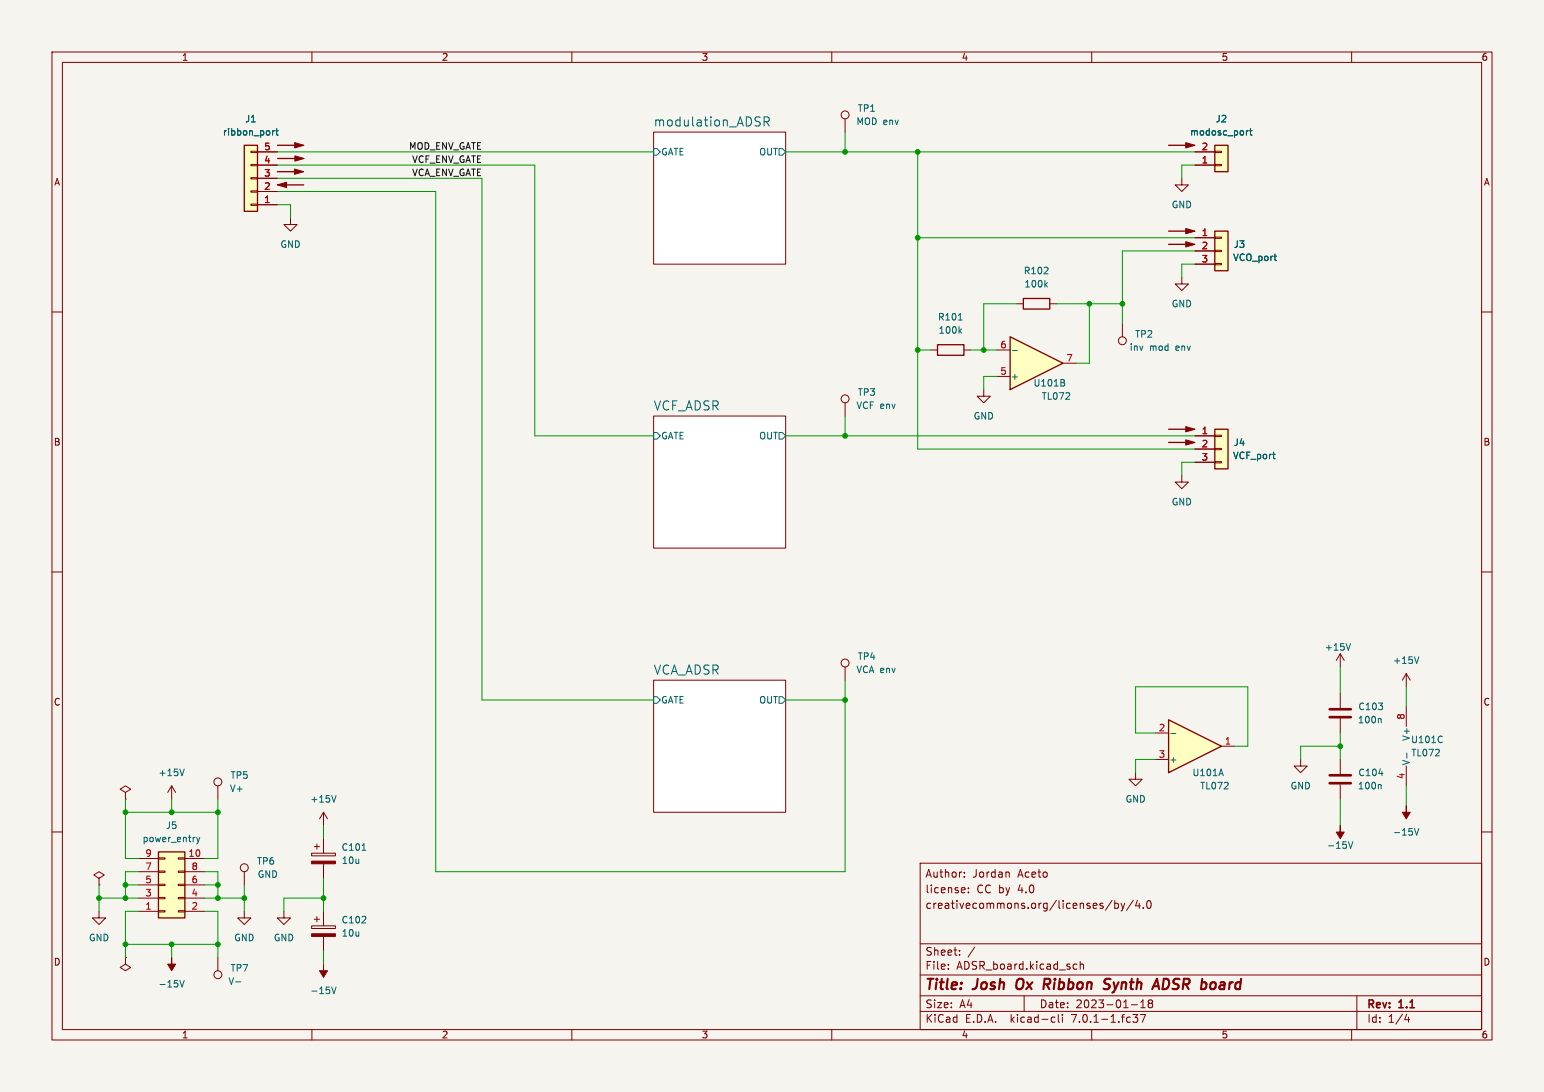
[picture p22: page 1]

File: ADSR_board.kicad_sch Sheet: / creativecommons.org/licenses/by/4.0

Id: 1/4 Title: Josh Ox Ribbon Synth ADSR board

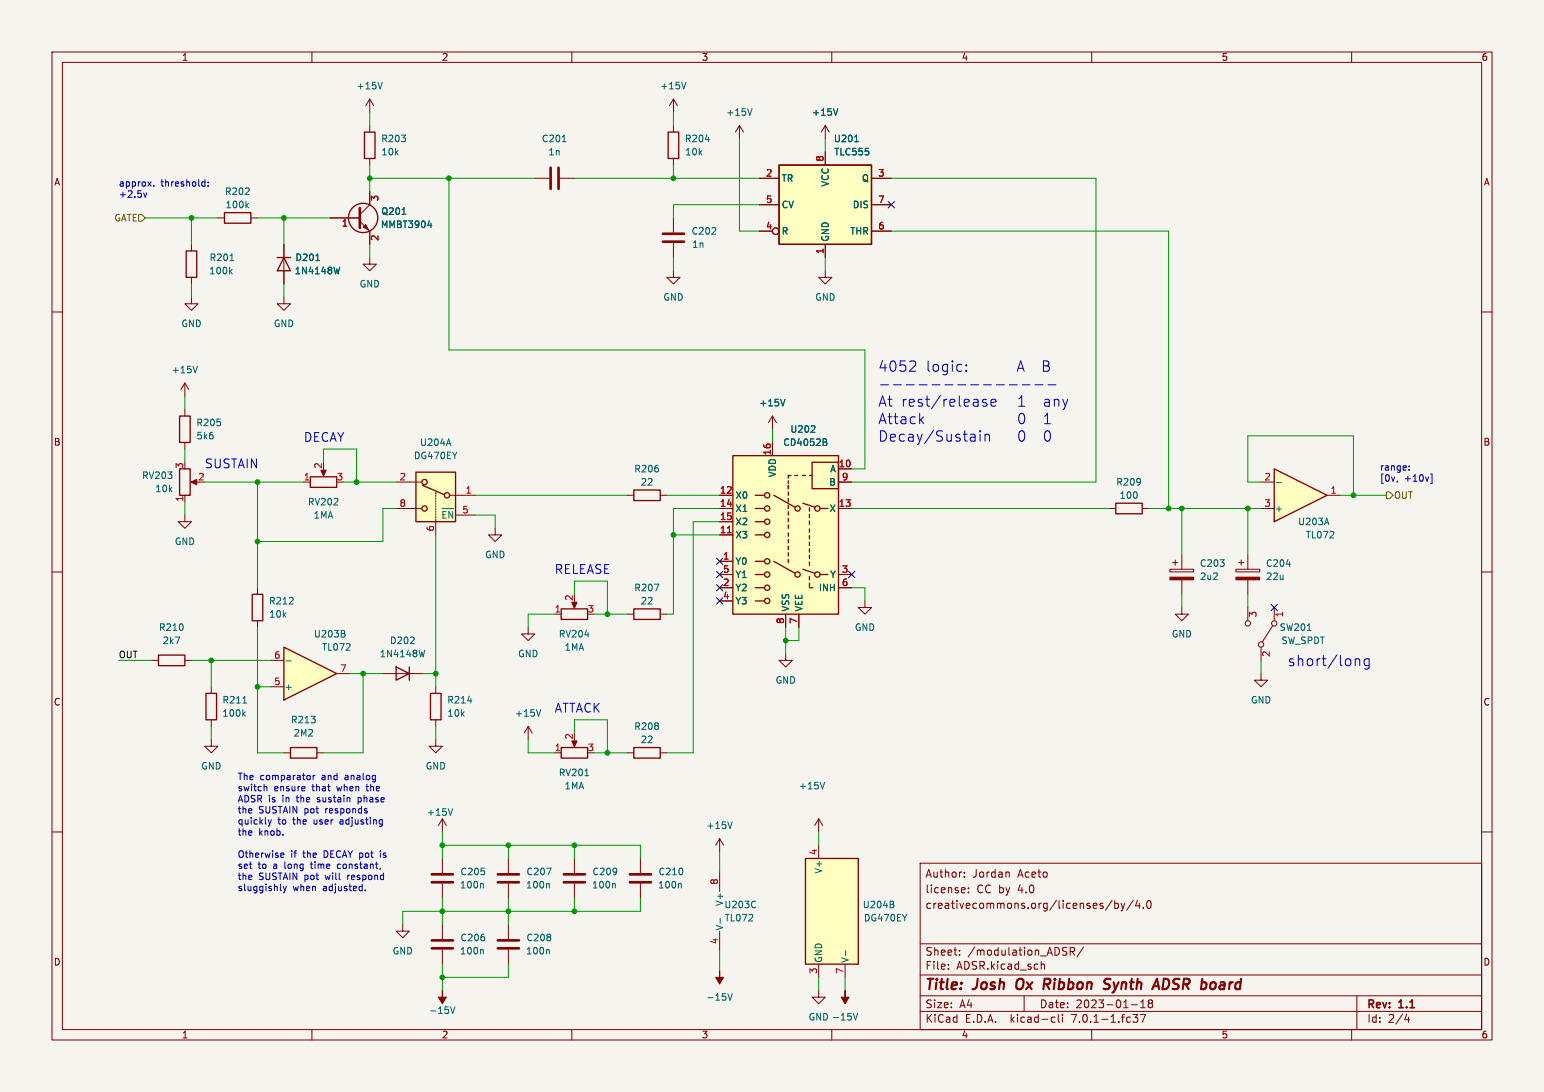
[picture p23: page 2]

switch ensure that when the ADSR is in the sustain phase

the SUSTAIN pot responds
quickly to the user adjusting
the knob. Otherwise if the DECAY pot is

set to a long time constant,
the SUSTAIN pot will respond

creativecommons.org/licenses/by/4.0

File: ADSR.kicad_sch Sheet: /modulation_ADSR/
Id: 2/4 Title: Josh Ox Ribbon Synth ADSR board

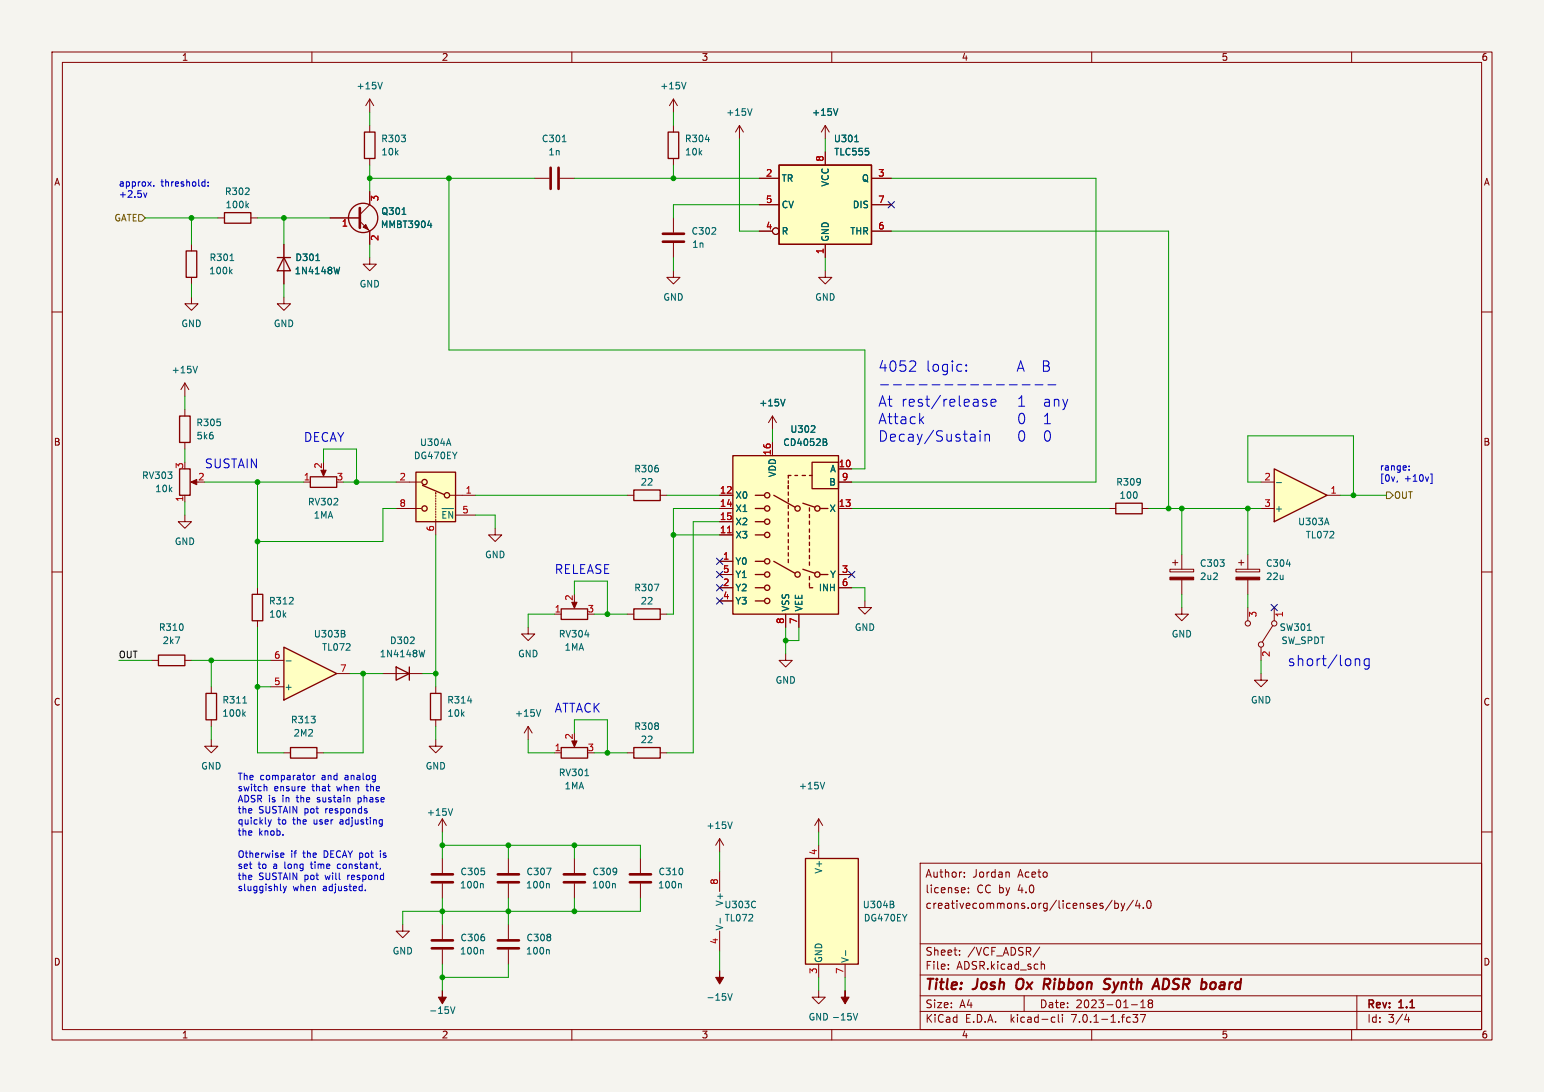
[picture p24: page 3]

switch ensure that when the ADSR is in the sustain phase

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

set to a long time constant,
the SUSTAIN pot will respond

creativecommons.org/licenses/by/4.0

File: ADSR.kicad_sch Sheet: /VCF_ADSR/
Id: 3/4 Title: Josh Ox Ribbon Synth ADSR board

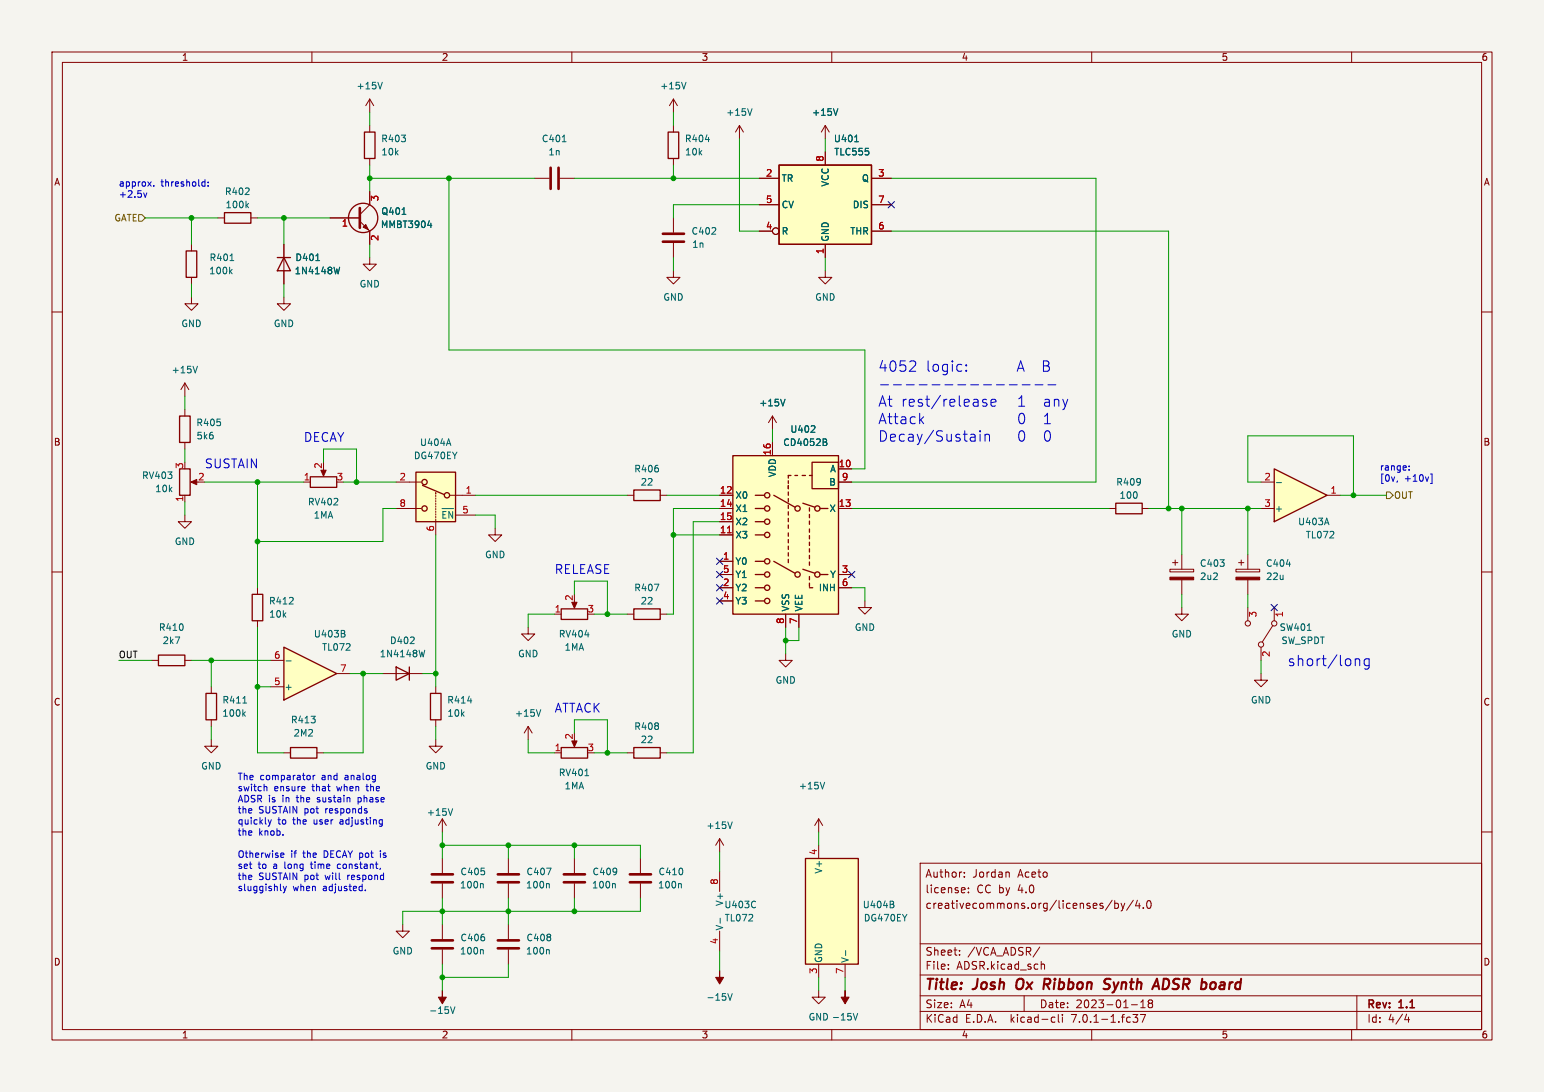
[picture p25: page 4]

switch ensure that when the ADSR is in the sustain phase

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

set to a long time constant,
the SUSTAIN pot will respond

creativecommons.org/licenses/by/4.0

File: ADSR.kicad_sch Sheet: /VCA_ADSR/
Id: 4/4 Title: Josh Ox Ribbon Synth ADSR board

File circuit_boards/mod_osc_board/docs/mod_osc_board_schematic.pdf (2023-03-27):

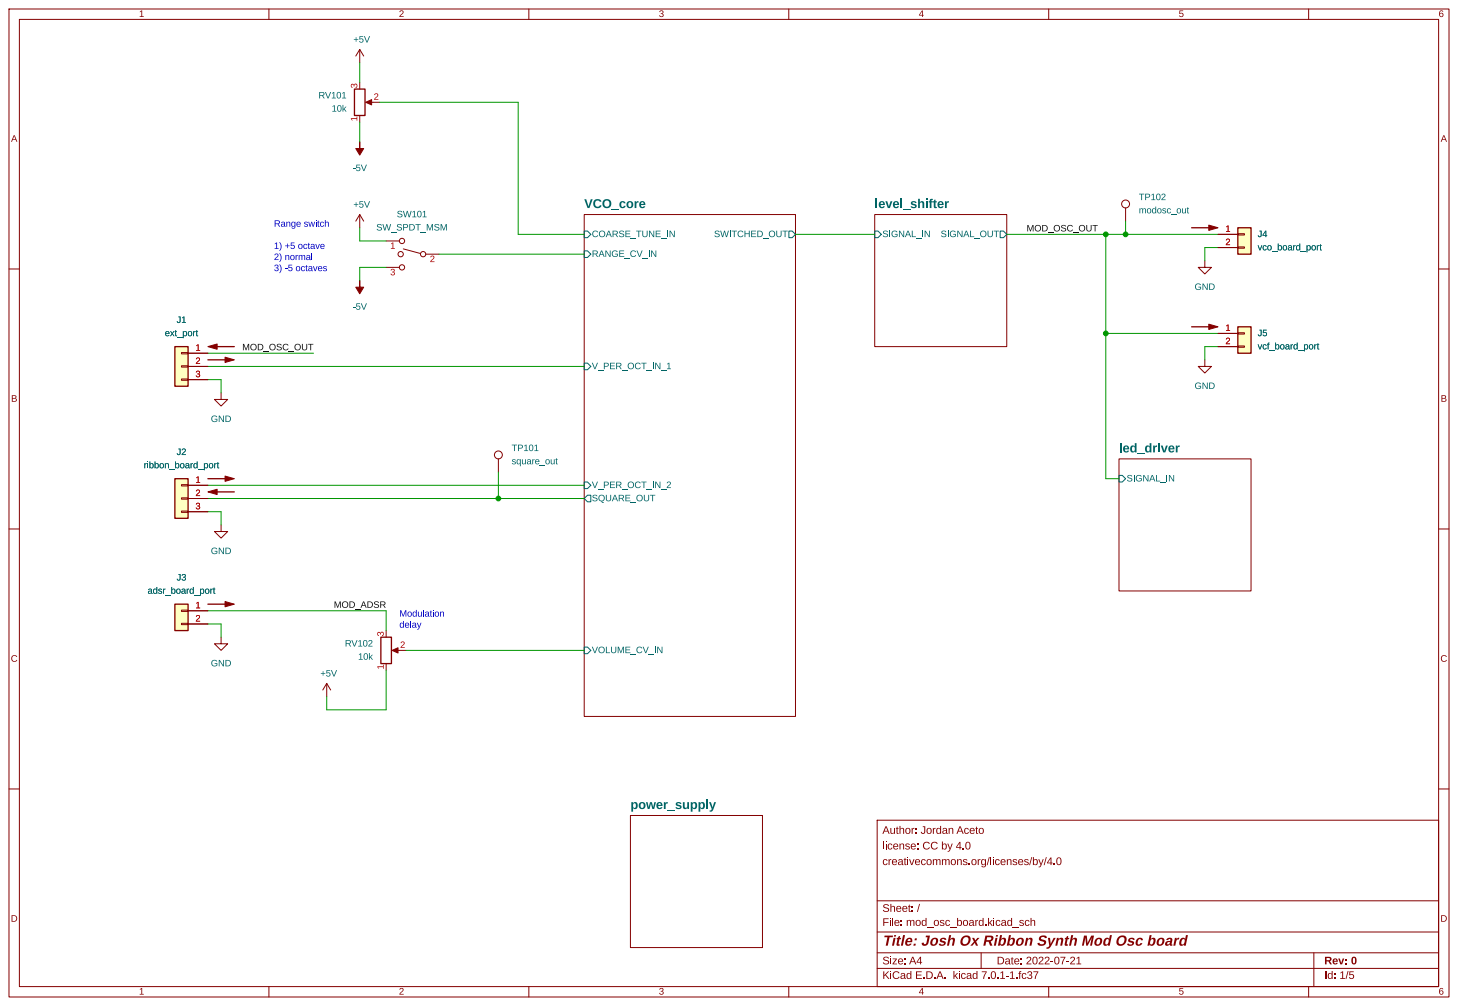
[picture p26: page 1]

license: CC by 4.0 Author: Jordan Aceto

File: mod_osc_board.kicad_sch Sheet: / creativecommons.org/licenses/by/4.0

Id: 1/5 Title: Josh Ox Ribbon Synth Mod Osc board

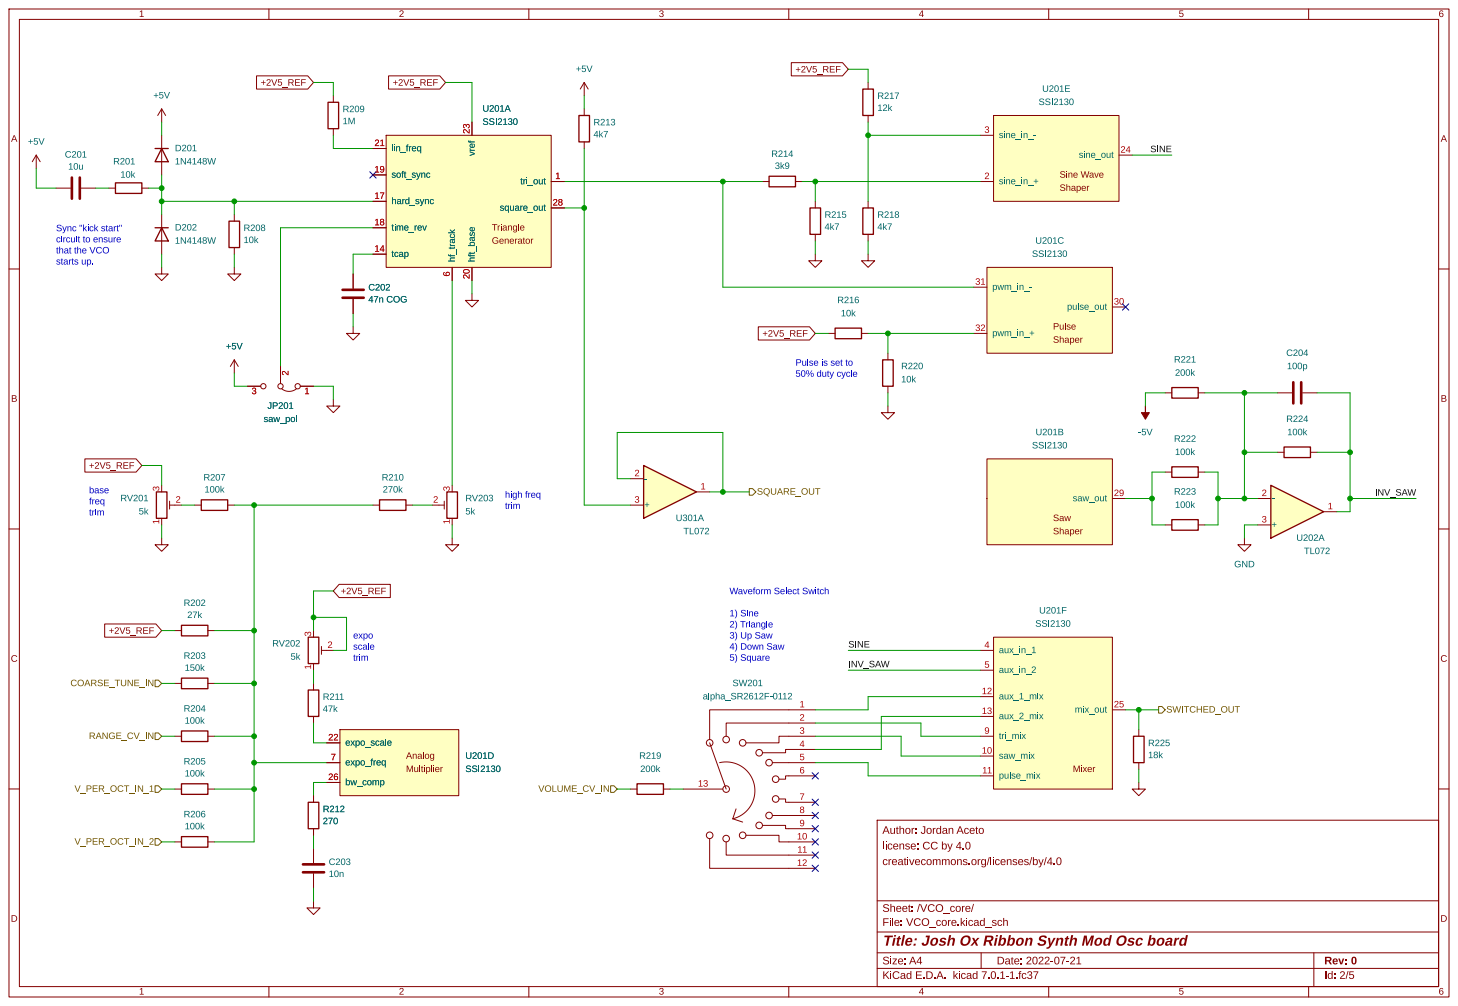
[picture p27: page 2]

Sync "kick start" circuit to ensure
4k7 RANGE_CV_IN

Pulse is set to
50% duty cycle

license: CC by 4.0 Author: Jordan Aceto R212

creativecommons.org/licenses/by/4.0

File: VCO_core.kicad_sch Sheet: /VCO_core/
Id: 2/5 Title: Josh Ox Ribbon Synth Mod Osc board

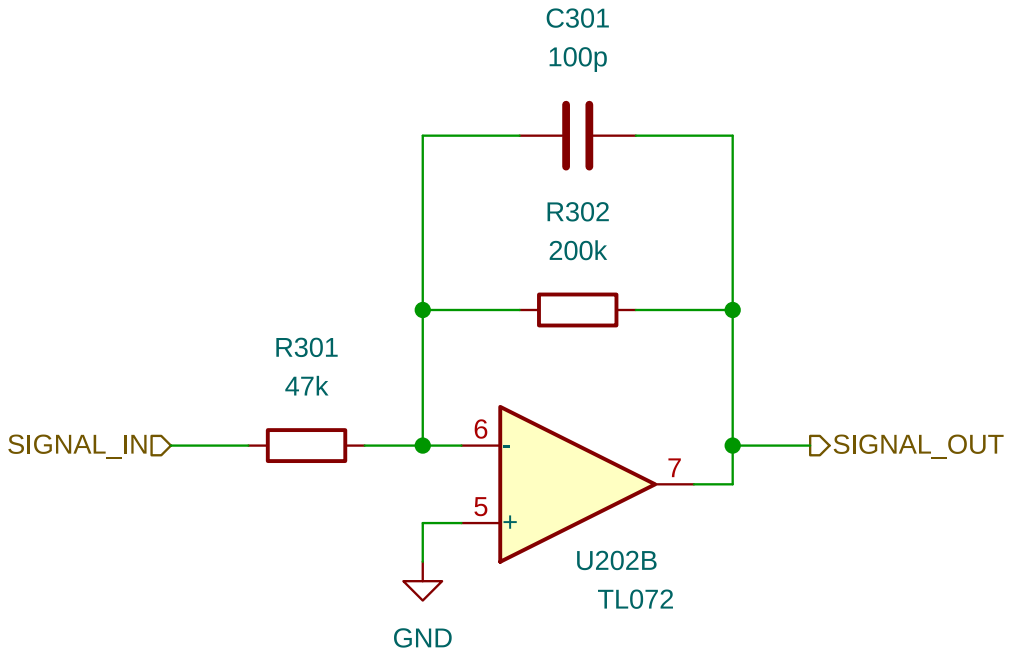
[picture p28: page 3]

license: CC by 4.0 Author: Jordan Aceto R301

creativecommons.org/licenses/by/4.0

File: level_shifter.kicad_sch Sheet: /level_shifter/
Id: 3/5 Title: Josh Ox Ribbon Synth Mod Osc board

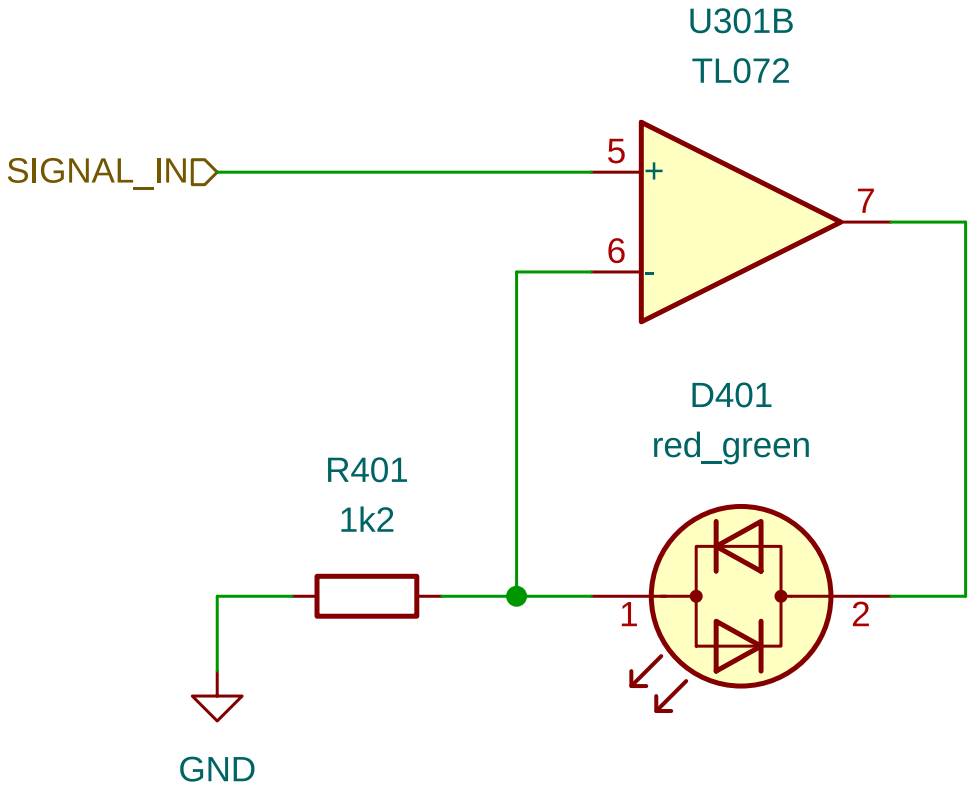
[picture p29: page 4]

license: CC by 4.0 Author: Jordan Aceto GND

creativecommons.org/licenses/by/4.0

File: led_driver.kicad_sch Sheet: /led_driver/
Id: 4/5 Title: Josh Ox Ribbon Synth Mod Osc board

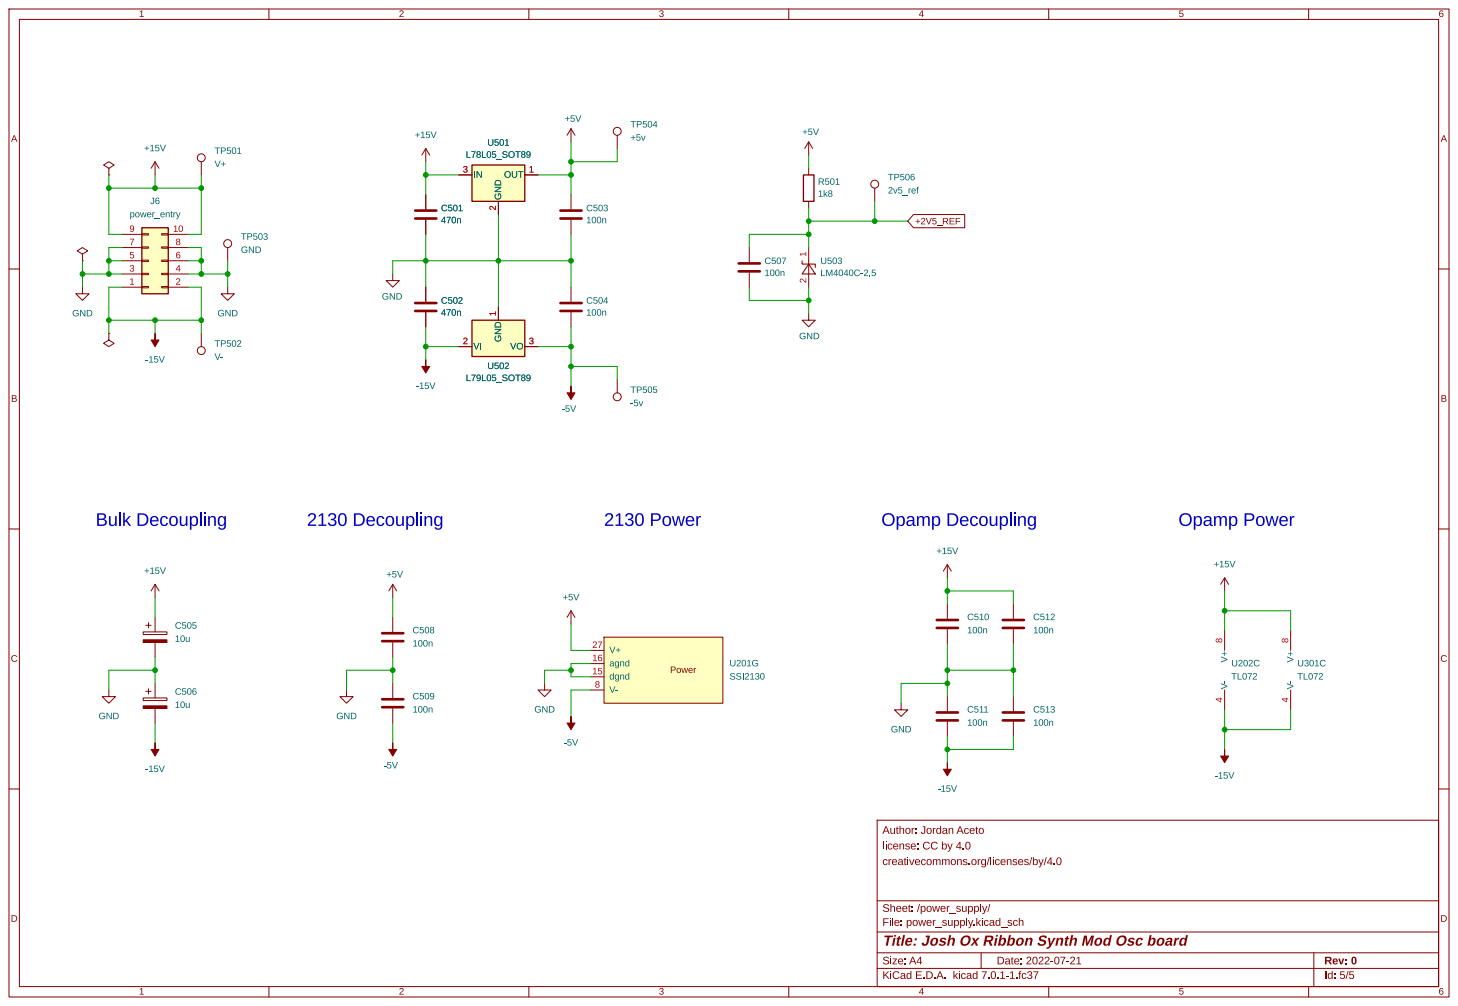
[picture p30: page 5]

license: CC by 4.0 Author: Jordan Aceto

creativecommons.org/licenses/by/4.0

File: power_supply.kicad_sch Sheet: /power_supply/
Id: 5/5 Title: Josh Ox Ribbon Synth Mod Osc board

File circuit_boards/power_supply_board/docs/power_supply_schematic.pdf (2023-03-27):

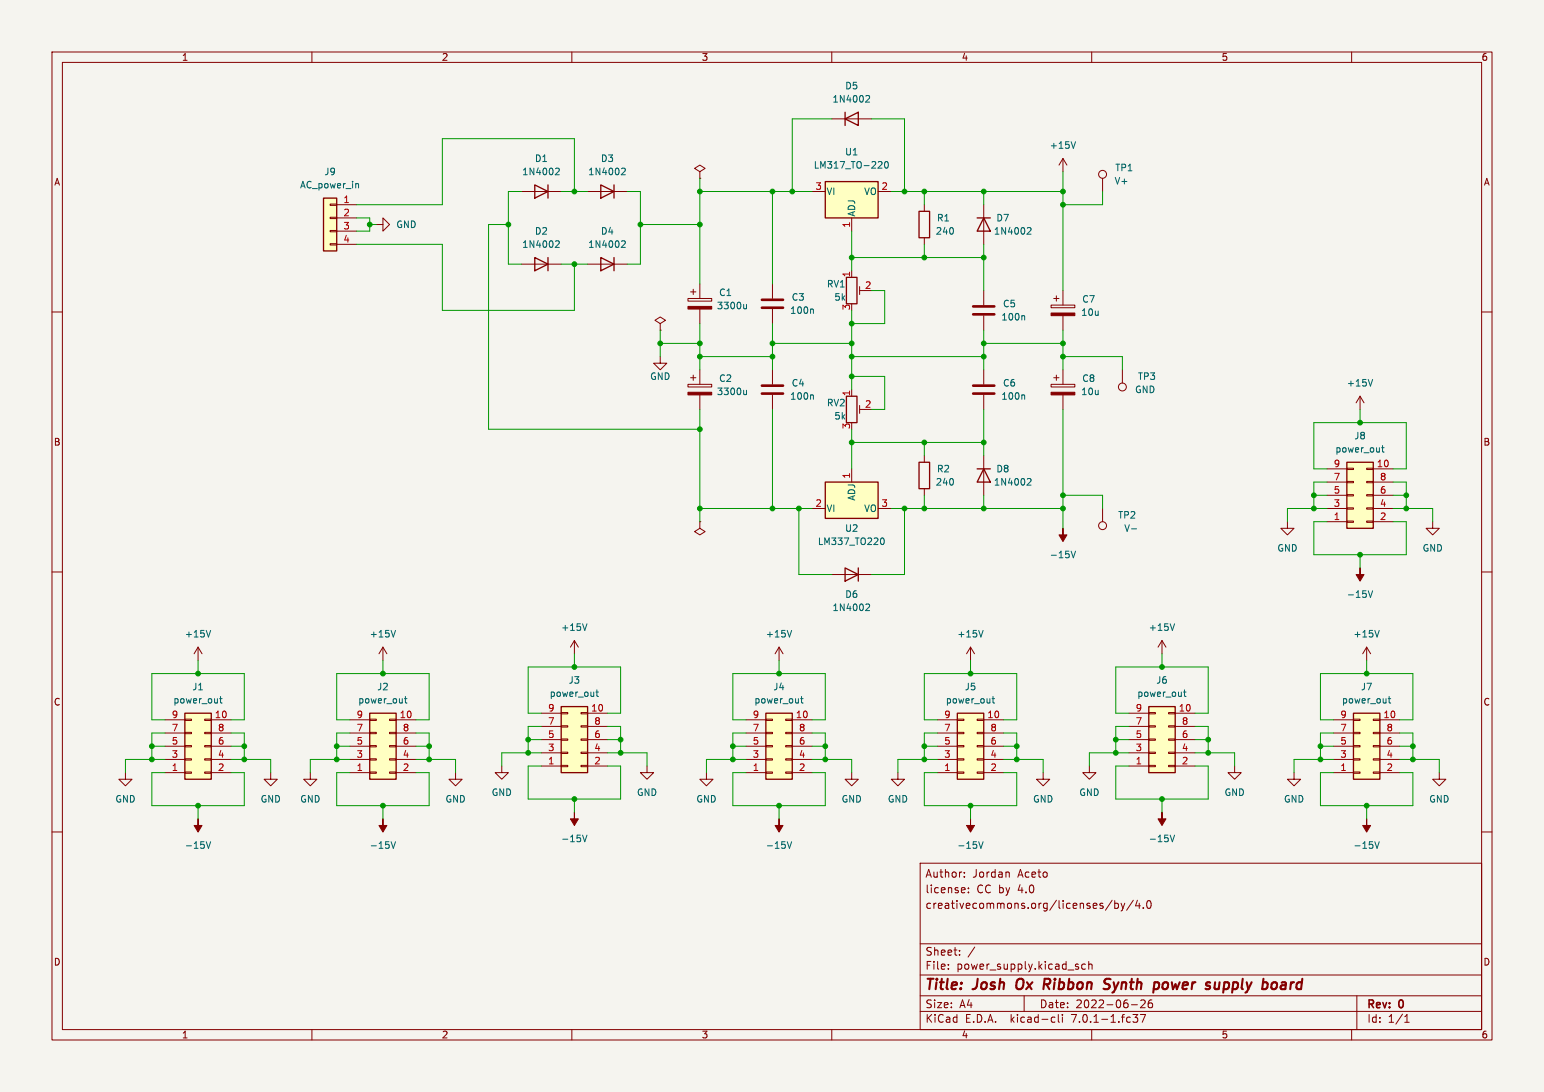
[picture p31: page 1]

Id: 1/1 Title: Josh Ox Ribbon Synth power supply board

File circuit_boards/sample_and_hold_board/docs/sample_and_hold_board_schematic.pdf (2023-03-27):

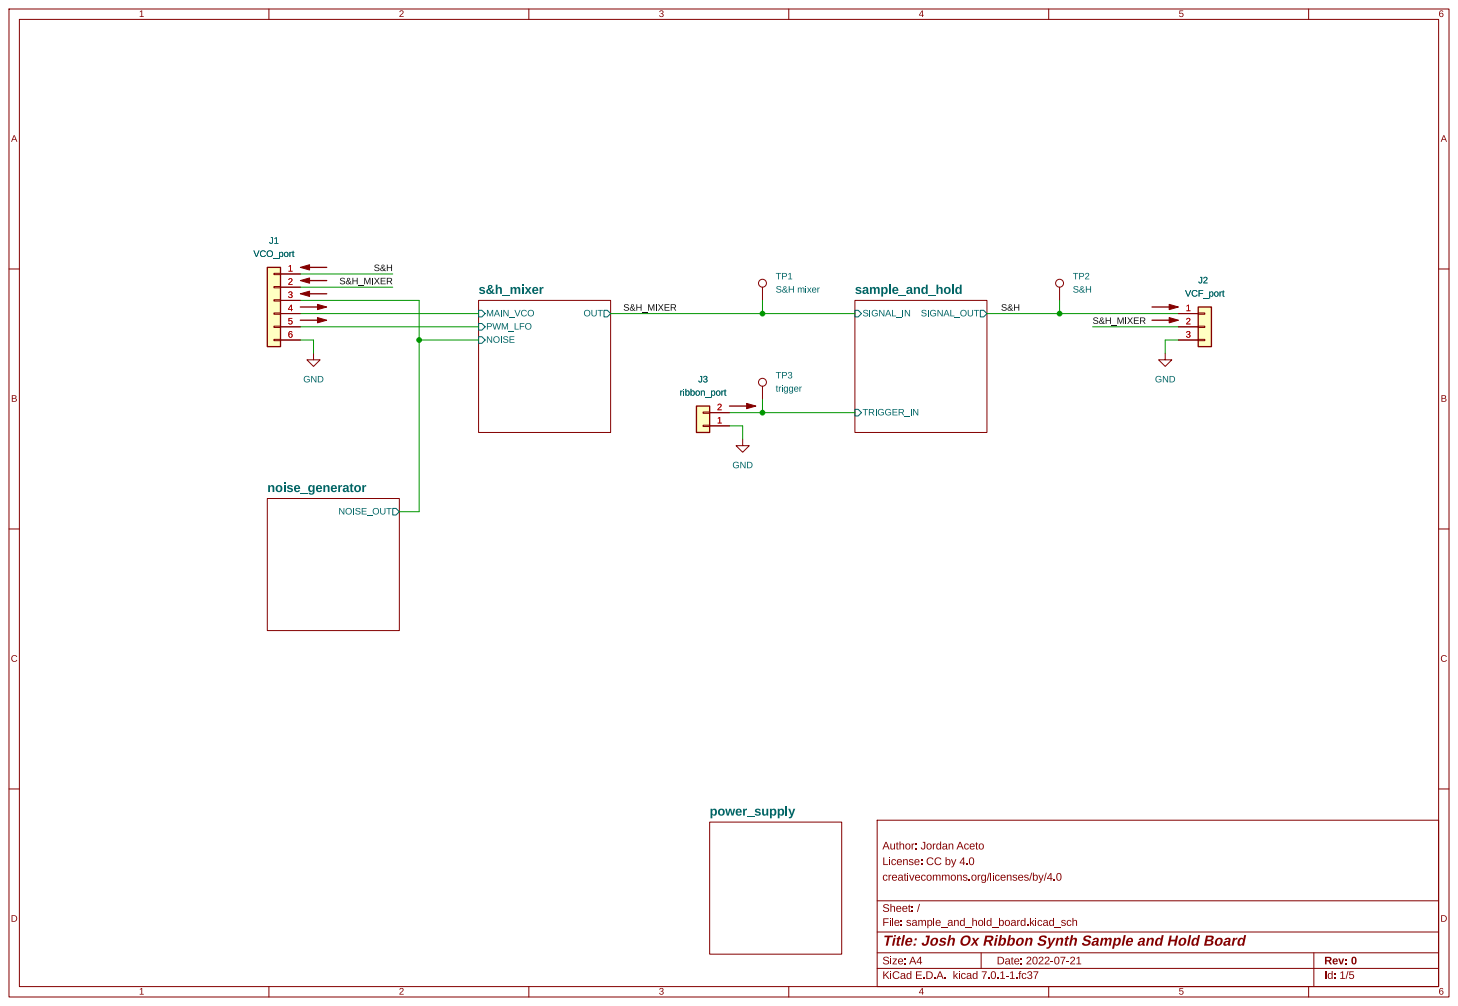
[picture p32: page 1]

5 5 | J3 J3 | 2 2 3 3
6 6

File: sample_and_hold_board.kicad_sch Sheet: / creativecommons.org/licenses/by/4.0

Id: 1/5 Title: Josh Ox Ribbon Synth Sample and Hold Board

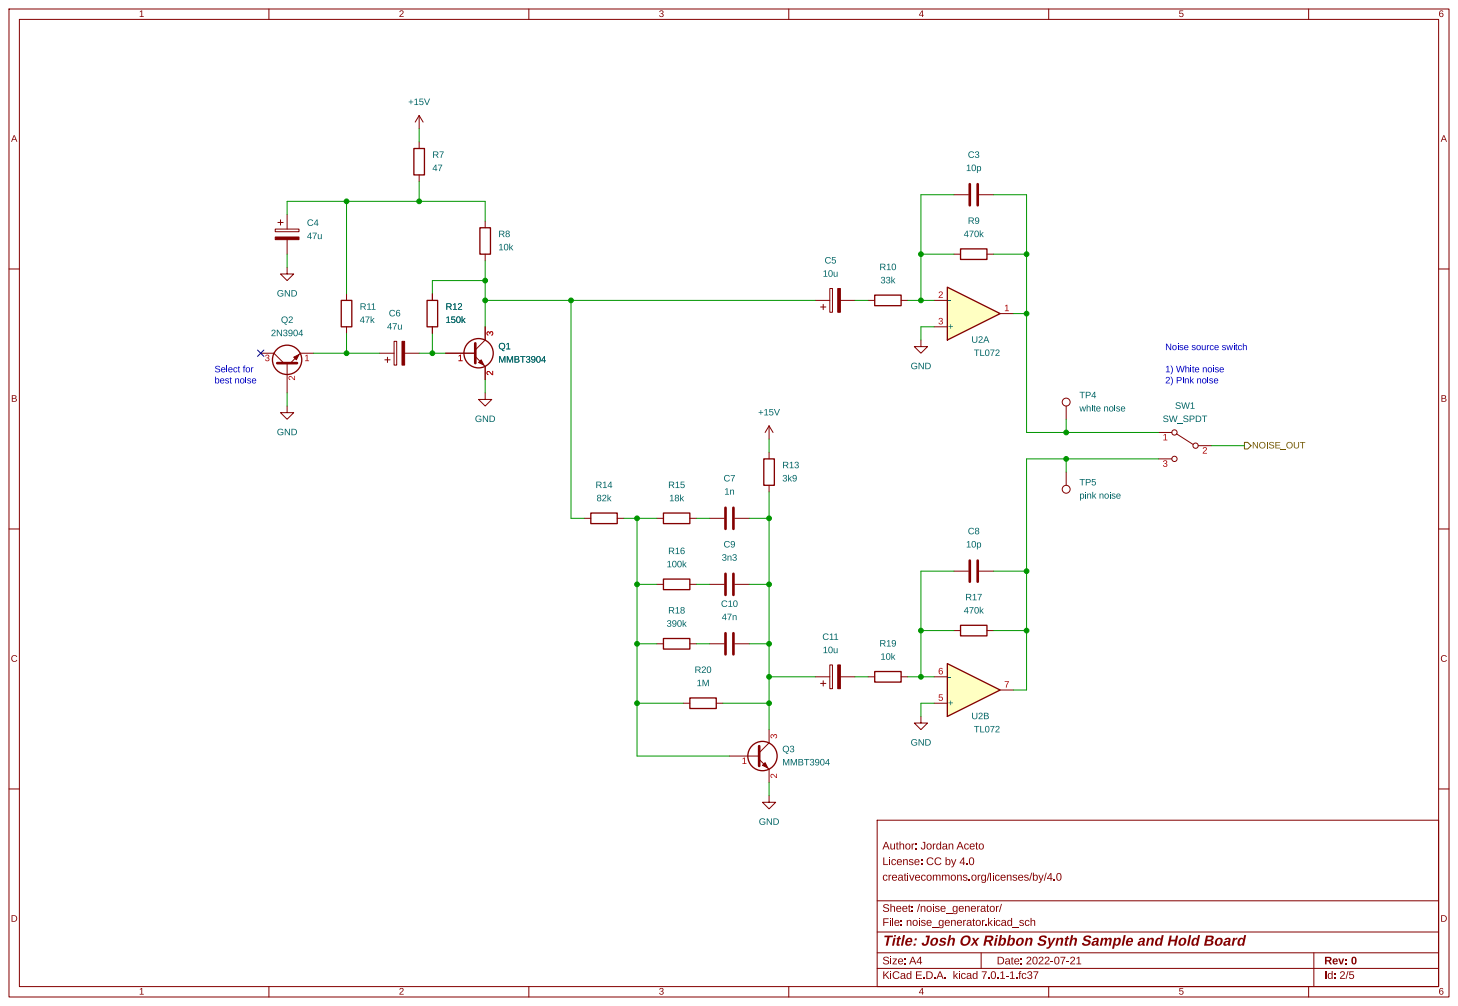
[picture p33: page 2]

2 3 Q1 MMBT3904 NOISE_OUT Select for best noise Noise source switch

License: CC by 4.0 Author: Jordan Aceto

creativecommons.org/licenses/by/4.0

File: noise_generator.kicad_sch Sheet: /noise_generator/
Id: 2/5 Title: Josh Ox Ribbon Synth Sample and Hold Board


License: CC by 4.0 Author: Jordan Aceto

creativecommons.org/licenses/by/4.0

File: s&h_mixer.kicad_sch Sheet: /s&h_mixer/
Id: 3/5 Title: Josh Ox Ribbon Synth Sample and Hold Board


creativecommons.org/licenses/by/4.0

File: sample_and_hold.kicad_sch Sheet: /sample_and_hold/
Id: 4/5 Title: Josh Ox Ribbon Synth Sample and Hold Board


License: CC by 4.0 Author: Jordan Aceto C17

creativecommons.org/licenses/by/4.0

File: power_supply.kicad_sch Sheet: /power_supply/
Id: 5/5 Title: Josh Ox Ribbon Synth Sample and Hold Board

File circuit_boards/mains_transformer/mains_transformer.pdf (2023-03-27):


The mains wiring and stepdown
transformer are connected with
point-to-point wiring, there
is no circuit board for these
components.

Molex MiniFit Jr connector
is attached to the transformer
with appropriate crimped
female pins.

This connector then mates with
the matching connector on the
power supply PCB.

Depending on how long the transformer
wires are from the factory it may
be necessary to use terminal strips
and extra wire to reach the power
supply board.

Approximate current drawn from the wall:
150mA @ 120VAC

Note that the wire colors on
the actual transformers are
sometimes different from the
factory.

Verify the transformer windings
before applying power.

License: CC by 4.0 Author: Jordan Aceto

Id: 1/1 Title: Josh Ox Ribbon Synth Mains Transformer File: mains_transformer.kicad_sch Sheet: / creativecommons.org/licenses/by/4.0

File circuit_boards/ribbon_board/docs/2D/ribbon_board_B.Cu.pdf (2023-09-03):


File: ribbon_board.kicad_pcb Sheet: creativecommons.org/licences/by/4.0

Id: 1/1 Title: Josh Ox Ribbon Synth Ribbon board

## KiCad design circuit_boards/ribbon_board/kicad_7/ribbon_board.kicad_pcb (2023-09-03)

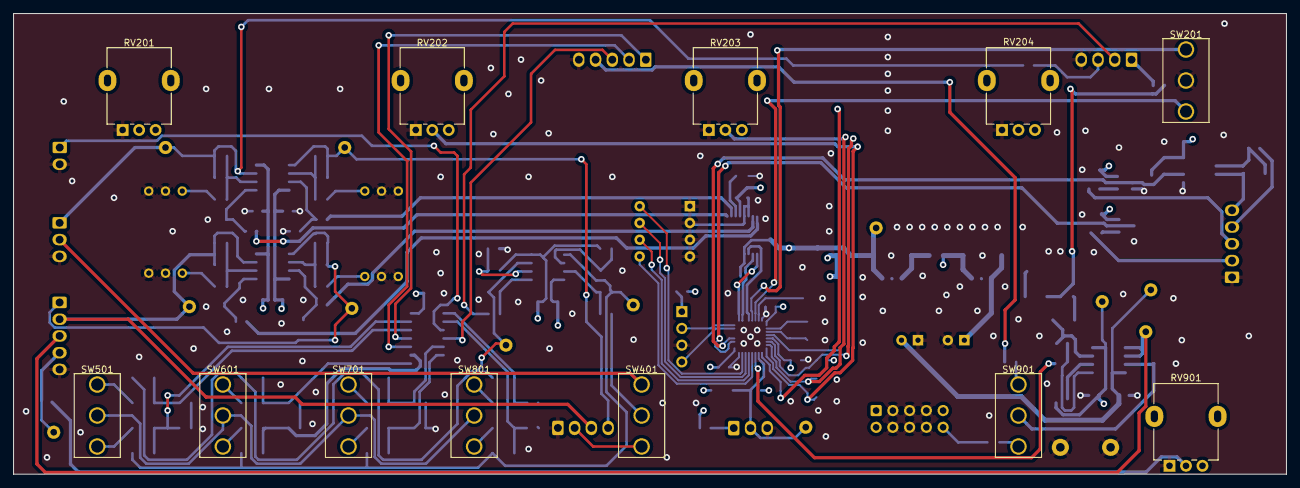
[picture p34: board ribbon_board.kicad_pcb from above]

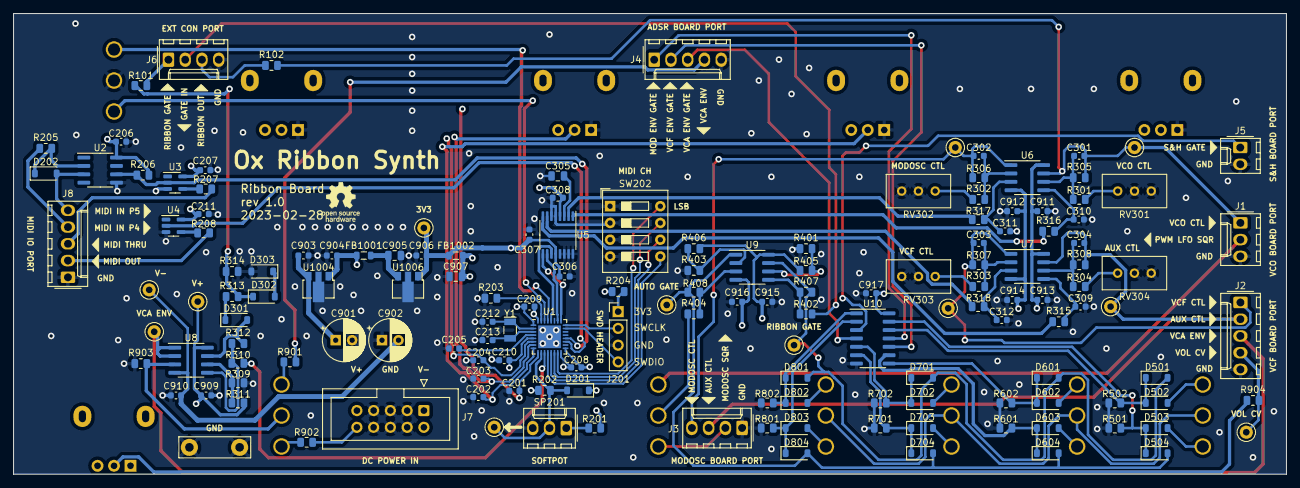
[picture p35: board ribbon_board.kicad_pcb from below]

Board: 4 copper layers, 193.0 x 69.8 mm, 165 parts (153 on the bottom side), 105 nets.

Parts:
C201, C202, C203, C204, C205, C206, C207, C208, C209, C210, C211, C301, C302, C303, C304, C306, C307, C308, C309, C310, C311, C312, C903, C904, C906, C909, C910, C911, C912, C913, C914, C915, C916, C917: 100n; C_0603_1608Metric
C212, C213: 4p3; C_0603_1608Metric
C305, C907: 1u; C_0805_2012Metric
C901, C902: 10u; CP_Radial_D6.3mm_P2.50mm
C905: 2u2; C_0805_2012Metric
D201: DNF; D_SOD-123
D202, D301, D501, D502, D503, D504, D601, D602, D603, D604, D701, D702, D703, D704, D801, D802, D803, D804: 1N4148W; D_SOD-123
D302, D303: 5v1; D_SOD-123
FB1001, FB1002: 100R @ 100MHz; L_0805_2012Metric
J1: VCO_port; Molex_KK-254_AE-6410-03A_1x03_P2.54mm_Vertical
J2: VCF_port; Molex_KK-254_AE-6410-05A_1x05_P2.54mm_Vertical
J3: mod_osc_port; Molex_KK-254_AE-6410-04A_1x04_P2.54mm_Vertical
J4: ADSR_port; Molex_KK-254_AE-6410-05A_1x05_P2.54mm_Vertical
J5: S&H_port; Molex_KK-254_AE-6410-02A_1x02_P2.54mm_Vertical
J6: ext_port; Molex_KK-254_AE-6410-04A_1x04_P2.54mm_Vertical
J7: power_entry; IDC-Header_2x05_P2.54mm_Vertical
J8: MIDI_IO_port; Molex_KK-254_AE-6410-05A_1x05_P2.54mm_Vertical
J201: SWD_header; PinHeader_1x04_P2.54mm_Vertical
R101, R102, R204, R313, R904: 1k; R_0805_2012Metric
R201: 22; R_0805_2012Metric
R202: DNF; R_0805_2012Metric
R203, R206, R309, R310, R401, R402, R403, R404: 10k; R_0805_2012Metric
R205: 220; R_0805_2012Metric
R207, R208: 47; R_0805_2012Metric
R301, R302, R303, R304: 20k; R_0805_2012Metric
R305, R306, R307, R308: 68k; R_0805_2012Metric
R311, R314, R405, R406, R501, R502, R601, R602, R701, R702, R801, R802, R903: 100k; R_0805_2012Metric
R312, R407, R408: 1M2; R_0805_2012Metric
R315, R316, R317, R318: 12k; R_0805_2012Metric
R901: 82k; R_0805_2012Metric
R902: 200k; R_0805_2012Metric
RV201: 10k; Potentiometer_Alpha_RD901F-40-00D_Single_Vertical
RV202, RV203, RV204: 10k c.d.; Potentiometer_Alpha_RD901F-40-00D_Single_Vertical
RV301, RV302, RV303, RV304: 5k; Potentiometer_Bourns_3296W_Vertical
RV901: 100k; Potentiometer_Alpha_RD901F-40-00D_Single_Vertical
SP201: softpot; Molex_KK-254_AE-6410-03A_1x03_P2.54mm_Vertical
SW201, SW501, SW601, SW701, SW801: SW_SPDT_MSM; SPDT_mini_toggle
SW202: MIDI_CH; SW_DIP_SPSTx04_Slide_9.78x12.34mm_W7.62mm_P2.54mm
SW401, SW901: SW_SPDT; SPDT_mini_toggle
TP201: RAW_RIBBON; TestPoint_Keystone_5000-5004_Miniature
TP301: VCO_RIBBON; TestPoint_Keystone_5000-5004_Miniature
TP302: MODOSC_RIBBON; TestPoint_Keystone_5000-5004_Miniature
TP303: VCF_RIBBON; TestPoint_Keystone_5000-5004_Miniature
TP304: AUX_CV; TestPoint_Keystone_5000-5004_Miniature
TP401: rib_gate; TestPoint_Keystone_5000-5004_Miniature
TP402: auto_gate; TestPoint_Keystone_5000-5004_Miniature
TP901: VCA_ADSR_CV; TestPoint_Keystone_5000-5004_Miniature
TP902: VCA_VOL_CV; TestPoint_Keystone_5000-5004_Miniature
TP1001: V+; TestPoint_Keystone_5000-5004_Miniature
TP1002: V-; TestPoint_Keystone_5000-5004_Miniature
TP1003: GND; TestPoint_Bridge_Pitch7.62mm_Drill1.3mm
TP1004: 3v3; TestPoint_Keystone_5000-5004_Miniature
U1: STM32L412K8Ux; QFN-32-1EP_5x5mm_P0.5mm_EP3.45x3.45mm
U2: VO0600T; SOIC-8_3.9x4.9mm_P1.27mm
U3, U4: SN74LV1T34DBV; SOT-23-5
U5: DAC8164; TSSOP-16_4.4x5mm_P0.65mm
U6, U7, U8, U9: TL072; SOIC-8_3.9x4.9mm_P1.27mm
U10: 4081; SOIC-14_3.9x8.7mm_P1.27mm
U1004: L78L05_SOT89; SOT-89-3
U1006: L78L33_SOT89; SOT-89-3
Y1: 32_768KHZ; Crystal_SMD_MicroCrystal_CC7V-T1A-2Pin_3.2x1.5mm

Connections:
+3.3V: C206.1, C207.1, C208.1, C209.1, C211.1, C306.1, C307.1, C906.1, D201.1 (K), FB1002.1, R204.1, R206.1, TP1004.1, U1.1 (VDD), U1.17 (VDD), U2.8 (VCC), U3.5 (VCC), U4.5 (VCC), U5.12 (IOVDD), U1006.1 (OUT)
+3.3VA: C210.1, C308.1, C907.1, FB1002.2, R201.1, RV201.3, RV202.3, RV203.3, RV204.3, U1.5 (VDDA), U5.4 (AVDD)
+5V: C904.1, FB1001.1, R202.1, RV901.3, U1004.1 (OUT)
+15V: C901.1, C903.1, C909.1, C911.1, C913.1, C915.1, C917.1, J7.9, J7.10, R311.2, R405.2, R406.2, R902.1, SW501.2, SW601.2, SW701.2, SW801.2, TP1001.1, U6.8 (V+), U7.8 (V+), U8.8 (V+), U9.8 (V+), U10.14 (VDD), U1004.3 (IN)
-15V: C902.2, C910.2, C912.2, C914.2, C916.2, J7.1, J7.2, TP1002.1, U6.4 (V-), U7.4 (V-), U8.4 (V-), U9.4 (V-)
/EXT_GATE_IN_NORMAL_TO_RIBBON_GATE: J6.2, R402.1
/MOD_OSC_SQR: J3.2, SW401.1 (A)
/OPT_VCF_BBD_CV: C304.2, J2.2, J3.3, R308.2, TP304.1, U7.7
/PWM_LFO_SQR: J1.2, SW401.3 (C)
/VCA_ADSR: J4.4, R901.1
/VCA_ENV_CV: J2.3, TP901.1, U8.1, U8.2 (-)
/VCA_VOL_CV: J2.4, R904.2, TP902.1
/VCO_RIBBON_CTL: C301.2, J1.1, R102.2, R305.2, TP301.1, U6.7
/digital_ribbon_control/DELAY_LEV: C204.1, RV204.2, U1.6 (PA0)
/digital_ribbon_control/GATE_3V3: R310.1, U1.11 (PA5)
/digital_ribbon_control/MIDI_CH_0: SW202.8, U1.15 (PB1)
/digital_ribbon_control/MIDI_CH_1: SW202.7, U1.14 (PB0)
/digital_ribbon_control/MIDI_CH_2: SW202.6, U1.13 (PA7)
/digital_ribbon_control/MIDI_CH_3: SW202.5, U1.12 (PA6)
/digital_ribbon_control/MIDI_IN_P4: J8.4, R205.1
/digital_ribbon_control/MIDI_IN_P5: D202.2 (A), J8.5, U2.3 (C)
/digital_ribbon_control/MIDI_OUT: J8.2, R208.2
/digital_ribbon_control/MIDI_RX: R206.2, U1.20 (PA10), U2.6 (VO), U3.2 (A)
/digital_ribbon_control/MIDI_THRU: J8.3, R207.2
/digital_ribbon_control/MIDI_TX: U1.19 (PA9), U4.2 (A)
/digital_ribbon_control/MODE_SW_1: SW201.1, U1.29 (PB6)
/digital_ribbon_control/MODE_SW_2: SW201.3, U1.30 (PB7)
/digital_ribbon_control/MODOSC_LEV: C202.1, RV202.2, U1.8 (PA2)
/digital_ribbon_control/RAW_RIBBON: D201.2 (A), R202.2, SP201.2, TP201.1, U1.10 (PA4)
/digital_ribbon_control/SPI_CS: U1.25 (PA15), U5.9 (~SYNC)
/digital_ribbon_control/SPI_SCK: U1.26 (PB3), U5.10 (SCLK)
/digital_ribbon_control/SPI_SDO: U1.28 (PB5), U5.11 (DIN)
/digital_ribbon_control/SYS_SWCLK: J201.2, U1.24 (PA14)
/digital_ribbon_control/SYS_SWDIO: J201.4, U1.23 (PA13)
/digital_ribbon_control/VCF_LEV: C203.1, RV203.2, U1.7 (PA1)
/digital_ribbon_control/VCO_LEV: C201.1, RV201.2, U1.9 (PA3)
/gate_controller/MOD_ENV_GATE: J4.1, U10.11
/gate_controller/S&H_GATE: J5.1, U10.3
/gate_controller/VCA_ADSR_gate_logic/AUTO_GATE: D504.2 (A), D604.2 (A), D704.2 (A), D804.2 (A), R408.2, TP402.1, U9.1
/gate_controller/VCA_ADSR_gate_logic/RIBBON_GATE: D501.2 (A), D601.2 (A), D701.2 (A), D801.2 (A), R407.2, TP401.1, U9.7
/gate_controller/VCA_ENV_GATE: J4.3, U10.4
/gate_controller/VCF_ENV_GATE: J4.2, U10.10
/ribbon_scalers/GATE: D302.1 (K), R101.2, R313.2, R314.1
/ribbon_scalers/MODOSC_CTL_OUT: C302.2, J3.4, R306.2, TP302.1, U6.1
/ribbon_scalers/VCF_CTL_OUT: C303.2, J2.1, R307.2, TP303.1, U7.1
GND: C201.2, C202.2, C203.2, C204.2, C205.1, C206.2, C207.2, C208.2, C209.2, C210.2, C211.2, C212.1, C213.1, C305.2, C306.2, C307.2, C308.2, C309.1, C310.1, C311.1, C312.1, C901.2, C902.1, C903.2, C904.2, C905.2, C906.2, C907.2, C909.2, C910.1, C911.2, C912.1, C913.2, C914.1, C915.2, C916.1, C917.2, D303.2 (A), J1.3, J2.5, J3.1, J4.5, J5.2, J6.4, J7.3, J7.4, J7.5, J7.6, J7.7, J7.8, J8.1, J201.3, R203.1, R309.1, R314.2, R401.1, R403.1, R501.2, R502.2, R601.2, R602.2, R701.2, R702.2, R801.2, R802.2, R903.1, RV201.1, RV202.1, RV203.1, RV204.1, RV301.2, RV301.3, RV302.2, RV302.3, RV303.2, RV303.3, RV304.2, RV304.3, RV901.1, SP201.3, SW201.2, SW202.1, SW202.2, SW202.3, SW202.4, TP1003.1, U1.16 (VSS), U1.32 (VSS), U1.33 (VSS), U2.5 (GND), U3.3 (GND), U4.3 (GND), U5.5 (VREFL), U5.6 (GND), U5.13 (A0), U5.14 (A1), U5.15 (~ENABLE), U5.16 (LDAC), U10.7 (VSS), U1004.2 (GND), U1006.2 (GND)
unnamed: D202.1 (K), R205.2, U2.2 (A)
unnamed: D301.2 (A), R312.2, U8.7
unnamed: D301.1 (K), R313.1
unnamed: D302.2 (A), D303.1 (K)
unnamed: D501.1 (K), D502.1 (K), R502.1, U10.12
unnamed: D502.2 (A), SW501.3
unnamed: D503.2 (A), SW501.1
unnamed: D503.1 (K), D504.1 (K), R501.1, U10.13
unnamed: D601.1 (K), D602.1 (K), R602.1, U10.8
unnamed: D602.2 (A), SW601.3
unnamed: D603.2 (A), SW601.1
unnamed: D603.1 (K), D604.1 (K), R601.1, U10.9
unnamed: D701.1 (K), D702.1 (K), R702.1, U10.5
unnamed: D702.2 (A), SW701.3
unnamed: D703.2 (A), SW701.1
unnamed: D703.1 (K), D704.1 (K), R701.1, U10.6
unnamed: D801.1 (K), D802.1 (K), R802.1, U10.1
unnamed: D802.2 (A), SW801.3
unnamed: D803.2 (A), SW801.1
unnamed: D803.1 (K), D804.1 (K), R801.1, U10.2
unnamed: J6.1, R101.1
unnamed: J6.3, R102.1
unnamed: J201.1, R204.2
unnamed: R301.1, RV301.1
unnamed: R302.1, RV302.1
unnamed: R303.1, RV303.1
unnamed: R304.1, RV304.1
unnamed: R904.1, RV901.2
unnamed: R201.2, SP201.1
unnamed: R404.1, SW401.2 (B)
unnamed: R902.2, SW901.1 (A)
unnamed: R903.2, SW901.2 (B), U8.3 (+)
unnamed: R901.2, SW901.3 (C)
unnamed: C205.2, U1.4 (NRST)
unnamed: C212.2, U1.2 (PC14), Y1.1
unnamed: C213.2, U1.3 (PC15), Y1.2
unnamed: R203.2, U1.31 (PH3)
unnamed: R207.1, U3.4 (Y)
unnamed: R208.1, U4.4 (Y)
unnamed: R316.1, U5.1 (VOUTA)
unnamed: R317.1, U5.2 (VOUTB)
unnamed: R318.1, U5.7 (VOUTC)
unnamed: R315.1, U5.8 (VOUTD)
unnamed: C305.1, U5.3 (VREFH/VREFOUT)
unnamed: C311.2, R317.2, U6.3 (+)
unnamed: C302.1, R302.2, R306.1, U6.2 (-)
unnamed: C310.2, R316.2, U6.5 (+)
unnamed: C301.1, R301.2, R305.1, U6.6 (-)
unnamed: C312.2, R318.2, U7.3 (+)
unnamed: C303.1, R303.2, R307.1, U7.2 (-)
unnamed: C309.2, R315.2, U7.5 (+)
unnamed: C304.1, R304.2, R308.1, U7.6 (-)
unnamed: R310.2, R312.1, U8.5 (+)
unnamed: R309.2, R311.1, U8.6 (-)
unnamed: R404.2, R408.1, U9.3 (+)
unnamed: R403.2, R406.1, U9.2 (-)
unnamed: R402.2, R407.1, U9.5 (+)
unnamed: R401.2, R405.1, U9.6 (-)
unnamed: C905.1, FB1001.2, U1006.3 (IN)

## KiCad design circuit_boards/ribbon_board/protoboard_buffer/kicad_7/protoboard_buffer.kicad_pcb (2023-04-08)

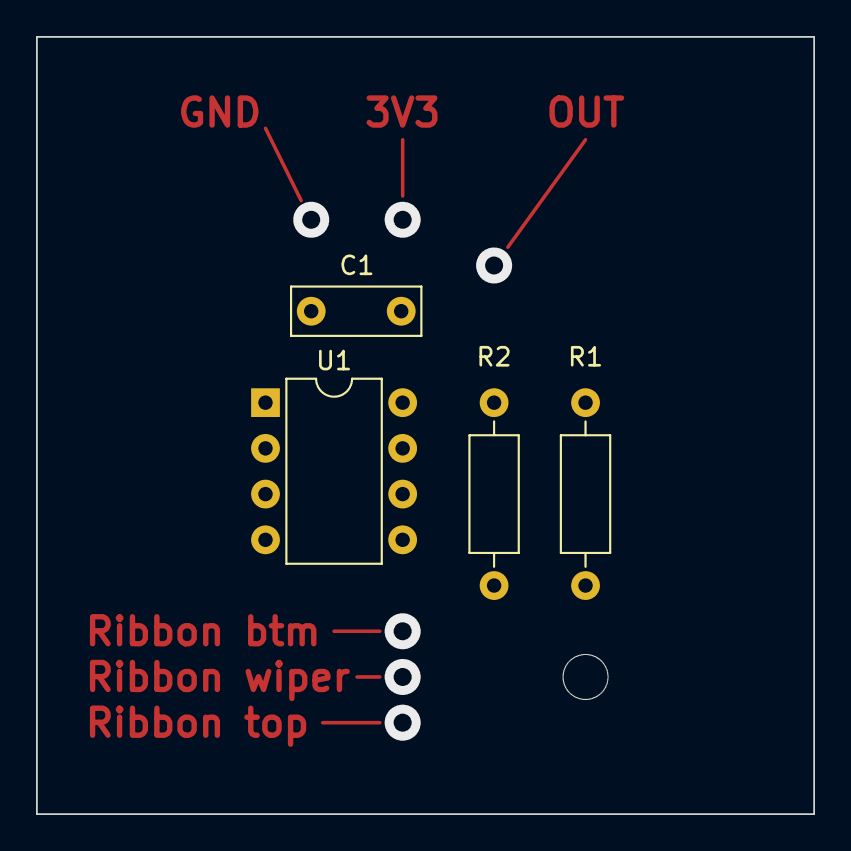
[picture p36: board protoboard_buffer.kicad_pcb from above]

Board: 4 copper layers, 43.2 x 43.2 mm, 4 parts (0 on the bottom side), 5 nets, no tracks yet.

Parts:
C1: 100n; C_Rect_L7.0mm_W2.5mm_P5.00mm
R1: 12k; R_Axial_DIN0207_L6.3mm_D2.5mm_P10.16mm_Horizontal
R2: 1M; R_Axial_DIN0207_L6.3mm_D2.5mm_P10.16mm_Horizontal
U1: MCP6002; DIP-8_W7.62mm

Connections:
+3V3: C1.1, R1.1, R2.1, U1.8 (V+)
GND: C1.2, U1.3 (+), U1.4 (V-)
unnamed: R2.2, U1.5 (+)
unnamed: U1.6 (-), U1.7
unnamed: U1.1, U1.2 (-)

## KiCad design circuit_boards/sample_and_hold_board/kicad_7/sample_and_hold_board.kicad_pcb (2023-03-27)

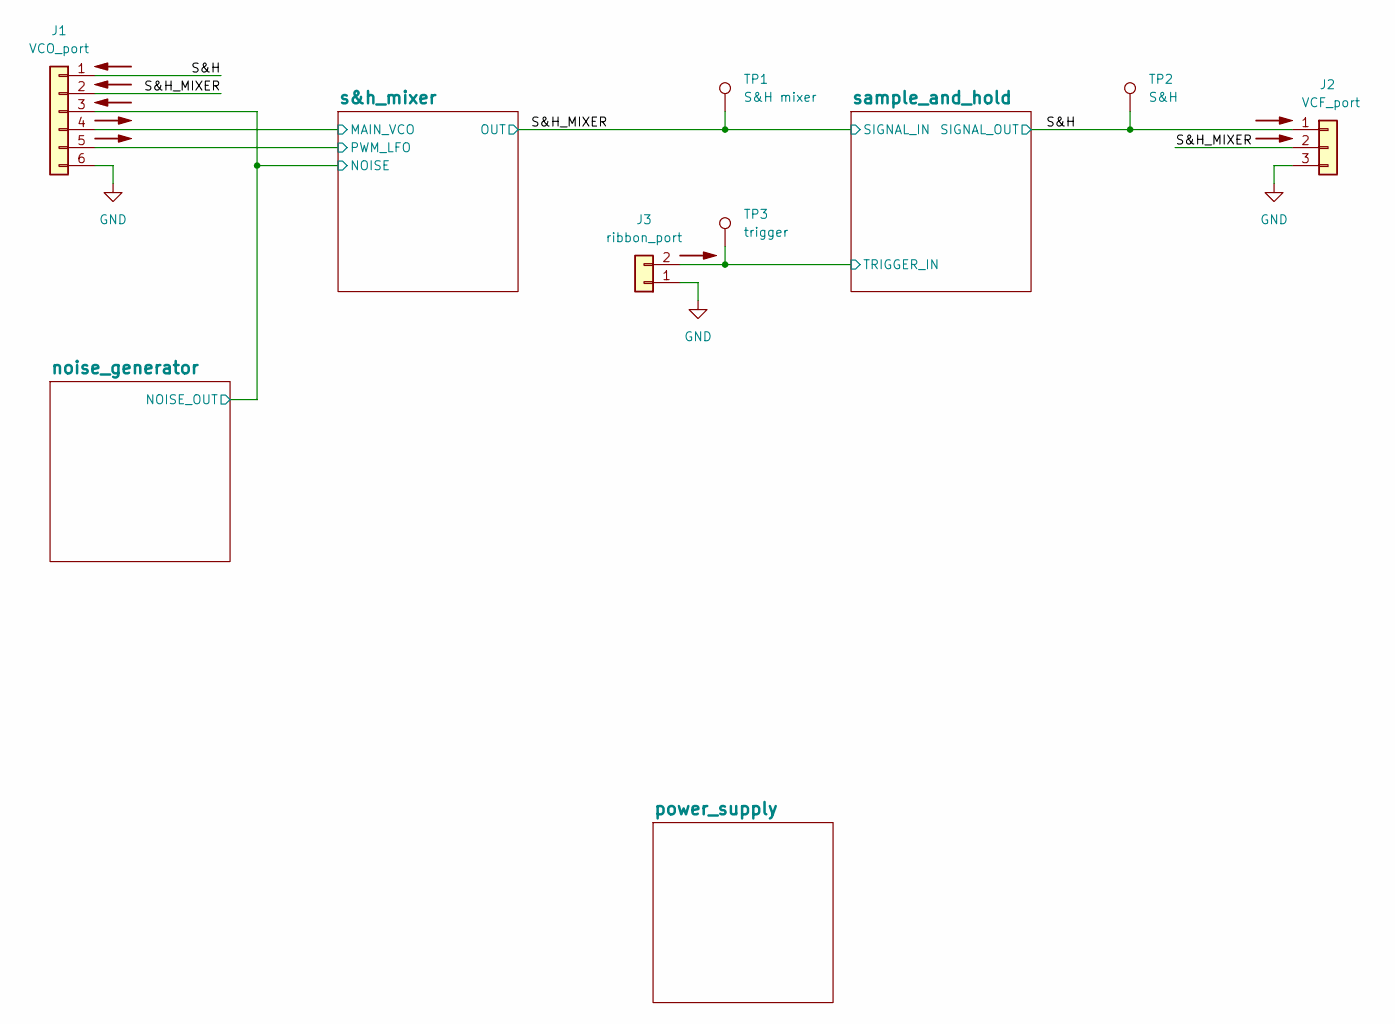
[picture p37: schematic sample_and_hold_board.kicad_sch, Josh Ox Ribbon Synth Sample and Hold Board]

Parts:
J1: VCO_port; Molex_KK-254_AE-6410-06A_1x06_P2.54mm_Vertical
J2: VCF_port; Molex_KK-254_AE-6410-03A_1x03_P2.54mm_Vertical
J3: ribbon_port; Molex_KK-254_AE-6410-02A_1x02_P2.54mm_Vertical
TP1: S&H mixer; TestPoint_Keystone_5000-5004_Miniature
TP2: S&H; TestPoint_Keystone_5000-5004_Miniature
TP3: trigger; TestPoint_Keystone_5000-5004_Miniature

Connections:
/S&H: J1.1, J2.1, TP2.1; also elsewhere on the board
/S&H_MIXER: J1.2, J2.2, TP1.1; also elsewhere on the board
/noise_generator/NOISE_OUT: J1.3; also elsewhere on the board
/s&h_mixer/MAIN_VCO: J1.4; also elsewhere on the board
/s&h_mixer/PWM_LFO: J1.5; also elsewhere on the board
/sample_and_hold/TRIGGER_IN: J3.2, TP3.1; also elsewhere on the board
GND: J1.6, J2.3, J3.1; also elsewhere on the board

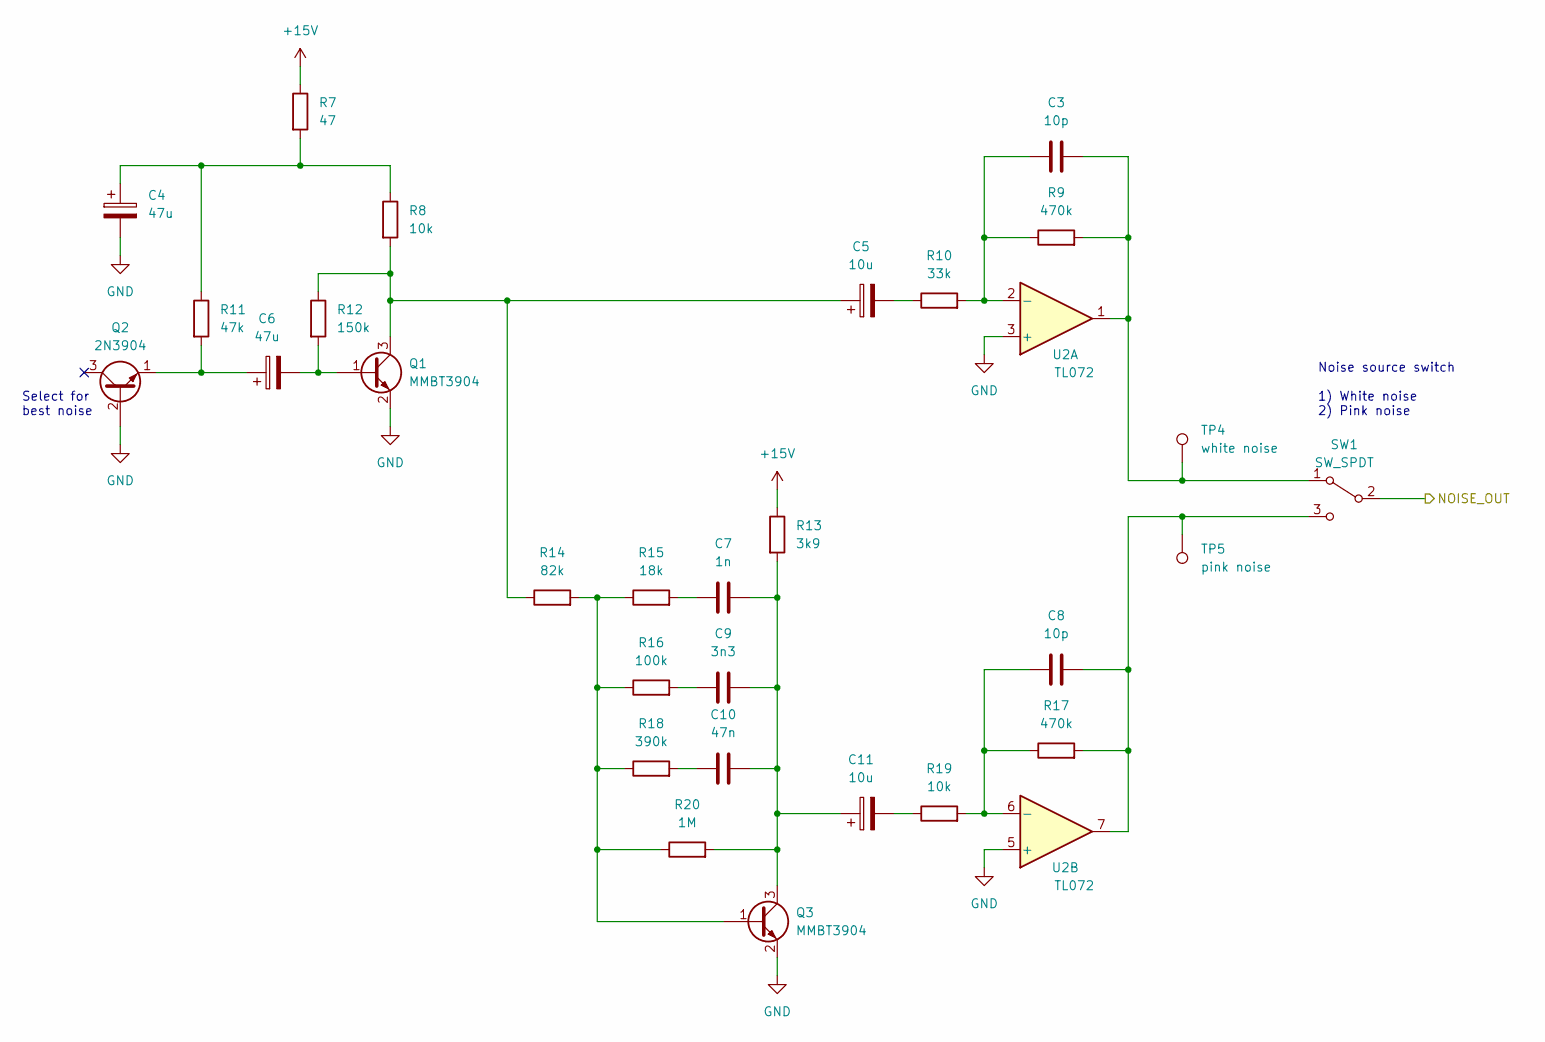
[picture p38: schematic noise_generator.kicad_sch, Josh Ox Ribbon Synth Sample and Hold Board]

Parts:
C3, C8: 10p; C_0805_2012Metric
C4, C6: 47u; CP_Radial_D6.3mm_P2.50mm
C5, C11: 10u; CP_Radial_D6.3mm_P2.50mm
C7: 1n; C_0805_2012Metric
C9: 3n3; C_0805_2012Metric
C10: 47n; C_0805_2012Metric
Q1, Q3: MMBT3904; SOT-23
Q2: 2N3904; TO-92_Inline_Wide
R7: 47; R_0805_2012Metric
R8, R19: 10k; R_0805_2012Metric
R9, R17: 470k; R_0805_2012Metric
R10: 33k; R_0805_2012Metric
R11: 47k; R_0805_2012Metric
R12: 150k; R_0805_2012Metric
R13: 3k9; R_0805_2012Metric
R14: 82k; R_0805_2012Metric
R15: 18k; R_0805_2012Metric
R16: 100k; R_0805_2012Metric
R18: 390k; R_0805_2012Metric
R20: 1M; R_0805_2012Metric
SW1: SW_SPDT; SPDT_mini_toggle
TP4: white noise; TestPoint_Keystone_5000-5004_Miniature
TP5: pink noise; TestPoint_Keystone_5000-5004_Miniature
U2: TL072; SO-8_5.3x6.2mm_P1.27mm

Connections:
+15V: R7.1, R13.1; also elsewhere on the board
/noise_generator/NOISE_OUT: SW1.2 (B); also elsewhere on the board
GND: C4.2, Q1.2 (E), Q2.2 (B), Q3.2 (E), U2.3 (+), U2.5 (+); also elsewhere on the board
unnamed: C3.1, R9.1, R10.2, U2.2 (-)
unnamed: C3.2, R9.2, SW1.1 (A), TP4.1, U2.1
unnamed: C4.1, R7.2, R8.1, R11.1
unnamed: C5.1, Q1.3 (C), R8.2, R12.1, R14.1
unnamed: C5.2, R10.1
unnamed: C6.1, Q2.1 (E), R11.2
unnamed: C6.2, Q1.1 (B), R12.2
unnamed: C7.1, R15.2
unnamed: C8.1, R17.1, R19.2, U2.6 (-)
unnamed: C8.2, R17.2, SW1.3 (C), TP5.1, U2.7
unnamed: C9.1, R16.2
unnamed: C10.1, R18.2
unnamed: C7.2, C9.2, C10.2, C11.1, Q3.3 (C), R13.2, R20.2
unnamed: C11.2, R19.1
unnamed: Q3.1 (B), R14.2, R15.1, R16.1, R18.1, R20.1

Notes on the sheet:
Noise source switch 1) White noise 2) Pink noise
Select for best noise

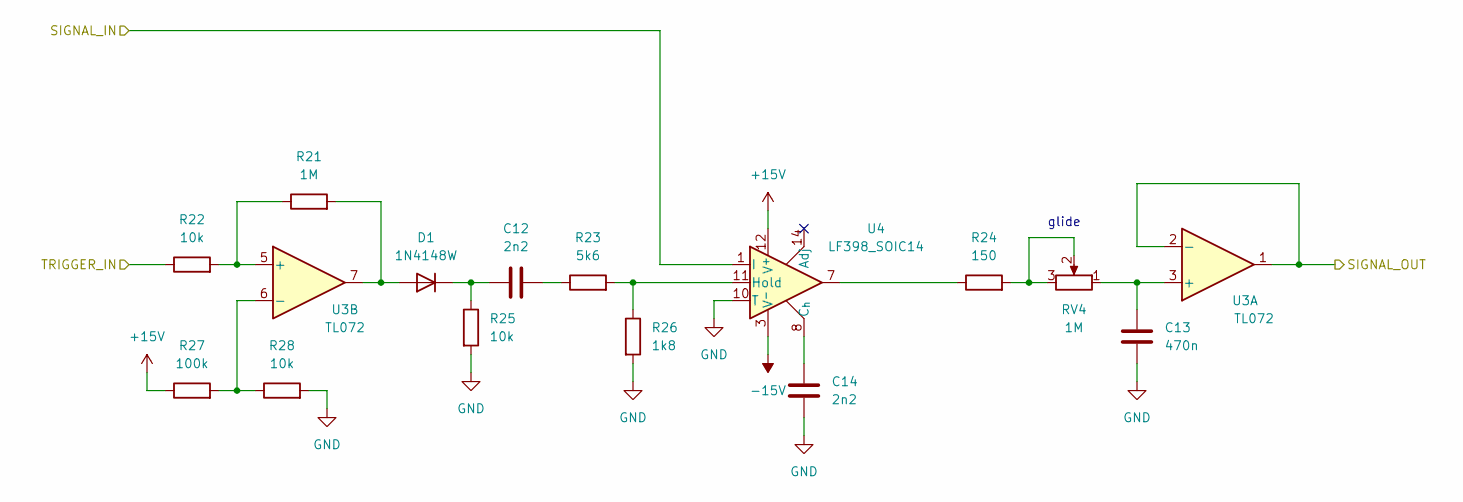
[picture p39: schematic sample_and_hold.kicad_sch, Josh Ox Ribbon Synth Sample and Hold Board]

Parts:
C12: 2n2; C_0805_2012Metric
C13: 470n; C_Rect_L7.2mm_W5.5mm_P5.00mm_FKS2_FKP2_MKS2_MKP2
C14: 2n2; C_Rect_L7.2mm_W2.5mm_P5.00mm_FKS2_FKP2_MKS2_MKP2
D1: 1N4148W; D_SOD-123
R21: 1M; R_0805_2012Metric
R22, R25, R28: 10k; R_0805_2012Metric
R23: 5k6; R_0805_2012Metric
R24: 150; R_0805_2012Metric
R26: 1k8; R_0805_2012Metric
R27: 100k; R_0805_2012Metric
RV4: 1M; Potentiometer_Alpha_RD901F-40-00D_Single_Vertical
U3: TL072; SO-8_5.3x6.2mm_P1.27mm
U4: LF398_SOIC14; SOIC-14_3.9x8.7mm_P1.27mm

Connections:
+15V: R27.1, U4.12 (V+); also elsewhere on the board
-15V: U4.3 (V-); also elsewhere on the board
/S&H: U3.1, U3.2 (-); also elsewhere on the board
/S&H_MIXER: U4.1 (I); also elsewhere on the board
/sample_and_hold/TRIGGER_IN: R22.1; also elsewhere on the board
GND: C13.2, C14.2, R25.2, R26.2, R28.2, U4.10 (T); also elsewhere on the board
unnamed: C12.1, D1.1 (K), R25.1
unnamed: C12.2, R23.1
unnamed: C13.1, RV4.1, U3.3 (+)
unnamed: C14.1, U4.8 (Ch)
unnamed: D1.2 (A), R21.2, U3.7
unnamed: R21.1, R22.2, U3.5 (+)
unnamed: R23.2, R26.1, U4.11 (Hold)
unnamed: R24.1, U4.7
unnamed: R24.2, RV4.2, RV4.3
unnamed: R27.2, R28.1, U3.6 (-)

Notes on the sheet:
glide

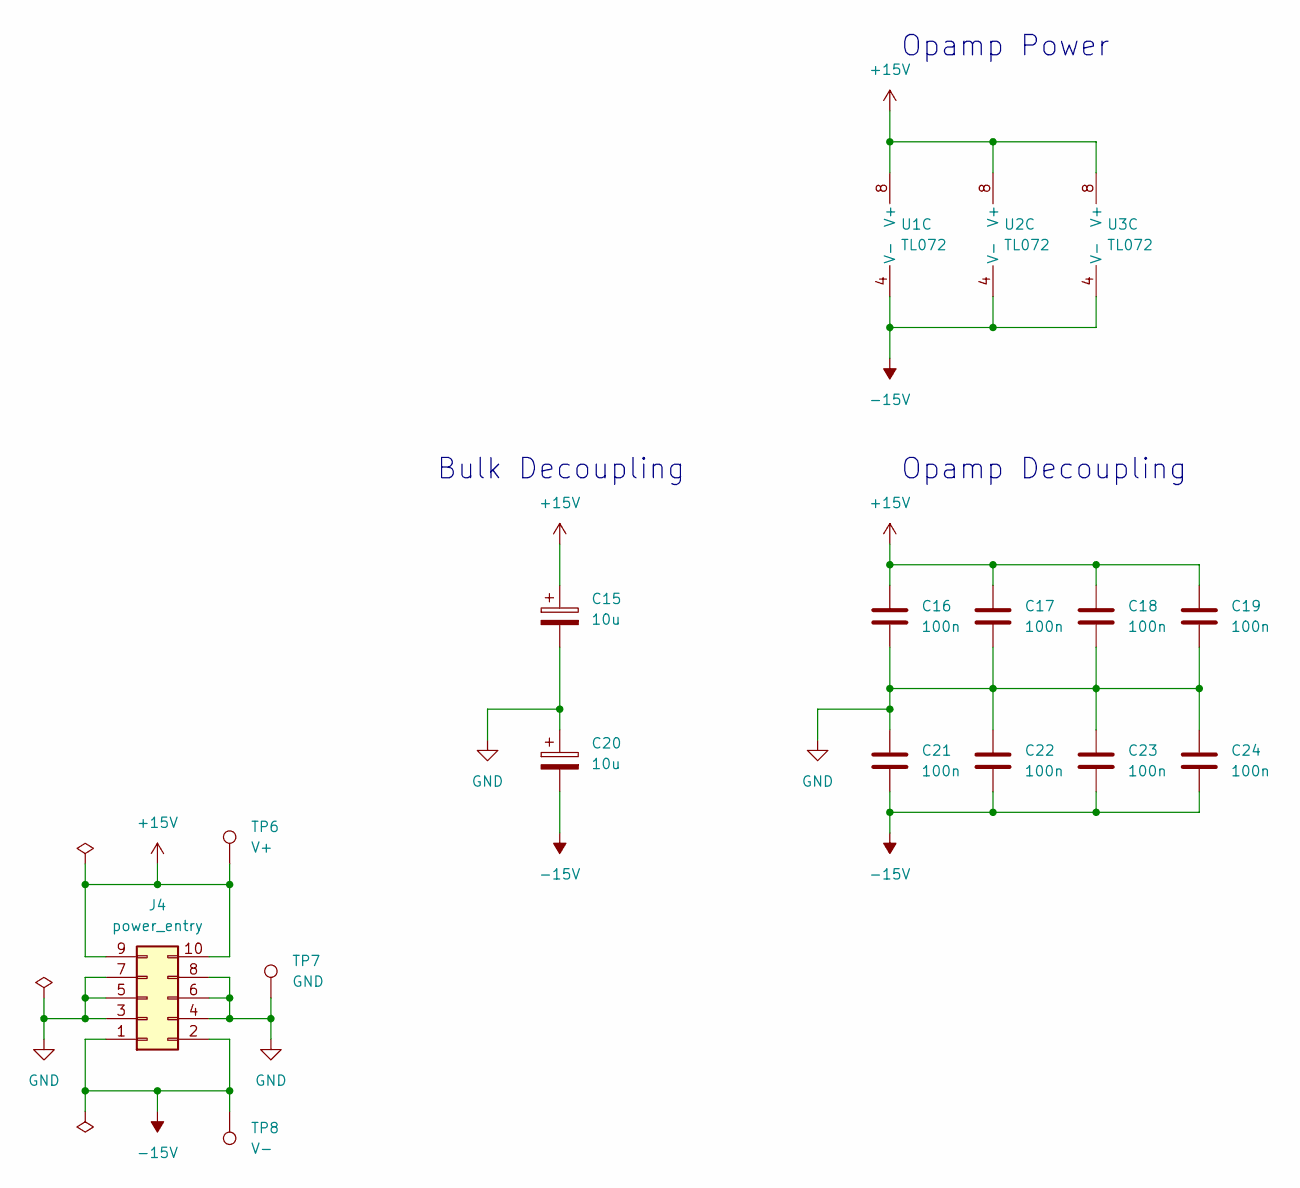
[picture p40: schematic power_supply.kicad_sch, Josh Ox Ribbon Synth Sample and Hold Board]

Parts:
C15, C20: 10u; CP_Radial_D6.3mm_P2.50mm
C16, C17, C18, C19, C21, C22, C23, C24: 100n; C_0805_2012Metric
J4: power_entry; IDC-Header_2x05_P2.54mm_Vertical
TP6: V+; TestPoint_Keystone_5000-5004_Miniature
TP7: GND; TestPoint_Bridge_Pitch7.62mm_Drill1.3mm
TP8: V-; TestPoint_Keystone_5000-5004_Miniature
U1, U2, U3: TL072; SO-8_5.3x6.2mm_P1.27mm

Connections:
+15V: C15.1, C16.1, C17.1, C18.1, C19.1, J4.9, J4.10, TP6.1, U1.8 (V+), U2.8 (V+), U3.8 (V+); also elsewhere on the board
-15V: C20.2, C21.2, C22.2, C23.2, C24.2, J4.1, J4.2, TP8.1, U1.4 (V-), U2.4 (V-), U3.4 (V-); also elsewhere on the board
GND: C15.2, C16.2, C17.2, C18.2, C19.2, C20.1, C21.1, C22.1, C23.1, C24.1, J4.3, J4.4, J4.5, J4.6, J4.7, J4.8, TP7.1; also elsewhere on the board

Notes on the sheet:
Opamp Decoupling
Opamp Power
Bulk Decoupling

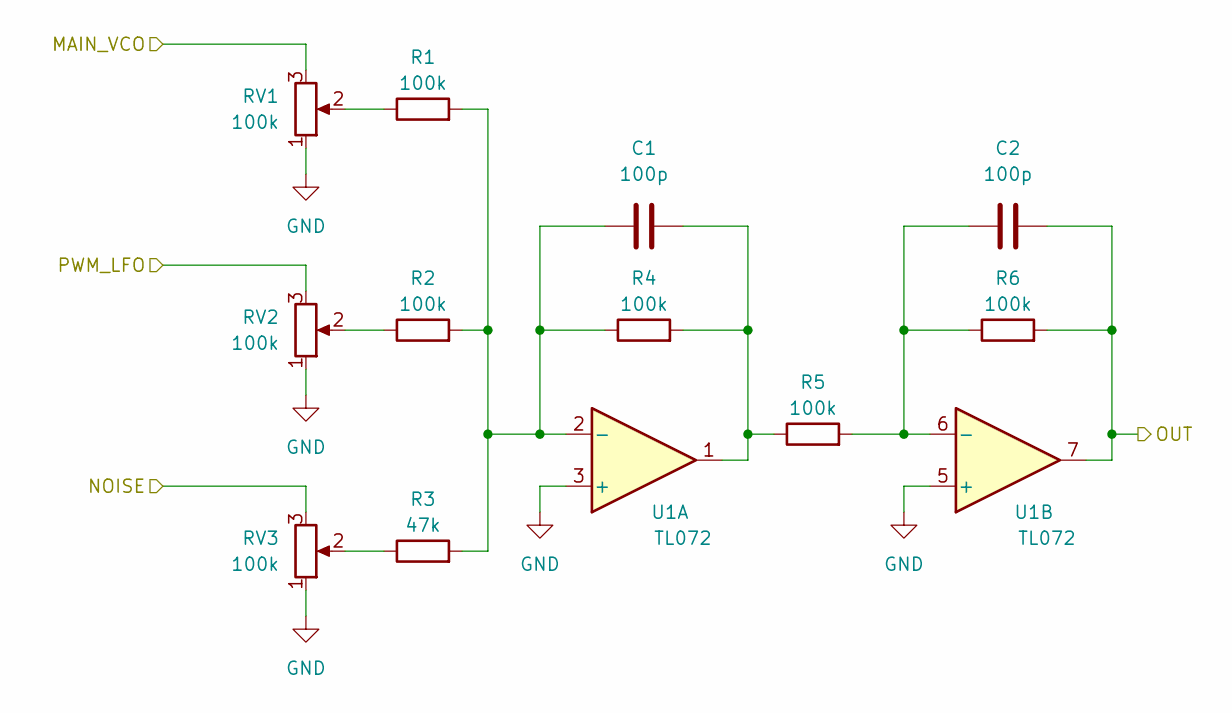
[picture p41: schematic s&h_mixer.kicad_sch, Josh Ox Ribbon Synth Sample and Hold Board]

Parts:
C1, C2: 100p; C_0805_2012Metric
R1, R2, R4, R5, R6: 100k; R_0805_2012Metric
R3: 47k; R_0805_2012Metric
RV1, RV2, RV3: 100k; Potentiometer_Alpha_RD901F-40-00D_Single_Vertical
U1: TL072; SO-8_5.3x6.2mm_P1.27mm

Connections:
/S&H_MIXER: C2.2, R6.2, U1.7; also elsewhere on the board
/noise_generator/NOISE_OUT: RV3.3; also elsewhere on the board
/s&h_mixer/MAIN_VCO: RV1.3; also elsewhere on the board
/s&h_mixer/PWM_LFO: RV2.3; also elsewhere on the board
GND: RV1.1, RV2.1, RV3.1, U1.3 (+), U1.5 (+); also elsewhere on the board
unnamed: C1.1, R1.2, R2.2, R3.2, R4.1, U1.2 (-)
unnamed: C1.2, R4.2, R5.1, U1.1
unnamed: C2.1, R5.2, R6.1, U1.6 (-)
unnamed: R1.1, RV1.2
unnamed: R2.1, RV2.2
unnamed: R3.1, RV3.2

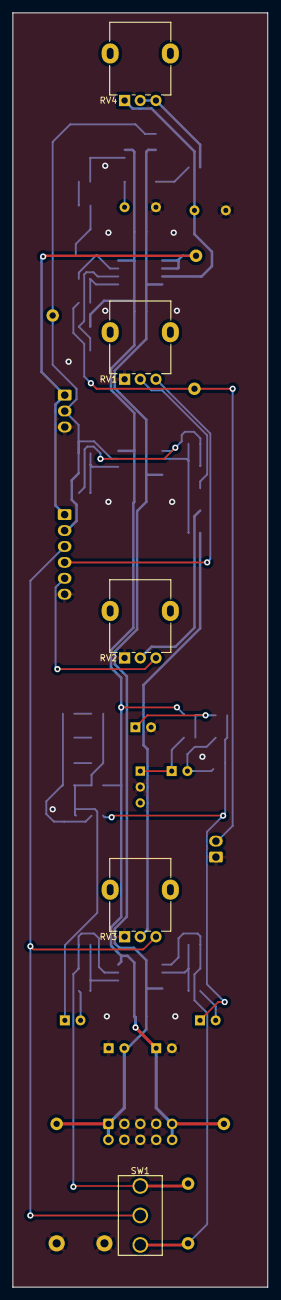
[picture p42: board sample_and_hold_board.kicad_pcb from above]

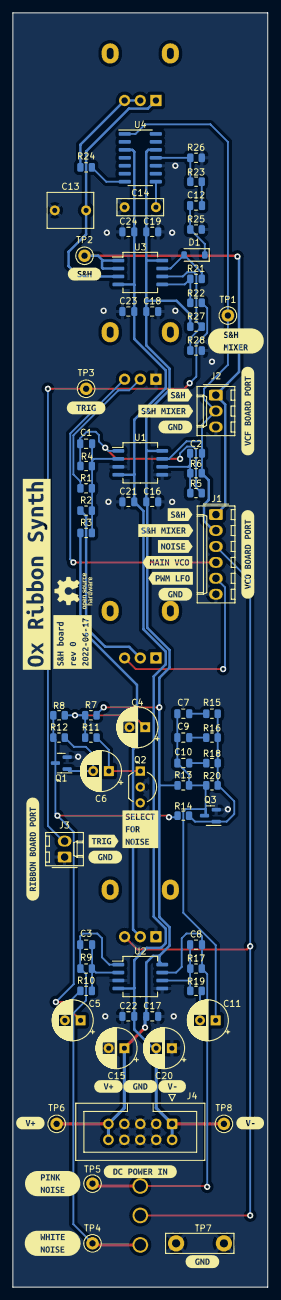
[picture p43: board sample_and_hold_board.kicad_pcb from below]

Board: 2 copper layers, 40.6 x 203.2 mm, 106 parts (101 on the bottom side), 40 nets.

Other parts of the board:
kibuzzard-62AC7A9F: G***; kibuzzard-62AC7A9F
kibuzzard-62AC78CB: G***; kibuzzard-62AC78CB
kibuzzard-62AC81C6: G***; kibuzzard-62AC81C6
kibuzzard-62AC81E3: G***; kibuzzard-62AC81E3
kibuzzard-62AC82BB: G***; kibuzzard-62AC82BB
kibuzzard-62AC82DF: G***; kibuzzard-62AC82DF
kibuzzard-62AC755C, kibuzzard-62AC755C#2, kibuzzard-62AC755C#3, kibuzzard-62AC755C#4, kibuzzard-62AC755C#5: G***; kibuzzard-62AC755C
kibuzzard-62AC791A, kibuzzard-62AC791A#2: G***; kibuzzard-62AC791A
kibuzzard-62AC792A, kibuzzard-62AC792A#2: G***; kibuzzard-62AC792A
kibuzzard-62AC813F, kibuzzard-62AC813F#2: G***; kibuzzard-62AC813F
kibuzzard-62AC818C: G***; kibuzzard-62AC818C
kibuzzard-62AC819F: G***; kibuzzard-62AC819F
kibuzzard-62AC822A: G***; kibuzzard-62AC822A
kibuzzard-62AC8121: G***; kibuzzard-62AC8121
kibuzzard-62AC8151, kibuzzard-62AC8151#2: G***; kibuzzard-62AC8151
kibuzzard-62AC8170: G***; kibuzzard-62AC8170
kibuzzard-62AC8211: G***; kibuzzard-62AC8211
kibuzzard-62AC8240: G***; kibuzzard-62AC8240
kibuzzard-62AC8254: G***; kibuzzard-62AC8254
kibuzzard-62AC8271: G***; kibuzzard-62AC8271
kibuzzard-62AC8282: G***; kibuzzard-62AC8282

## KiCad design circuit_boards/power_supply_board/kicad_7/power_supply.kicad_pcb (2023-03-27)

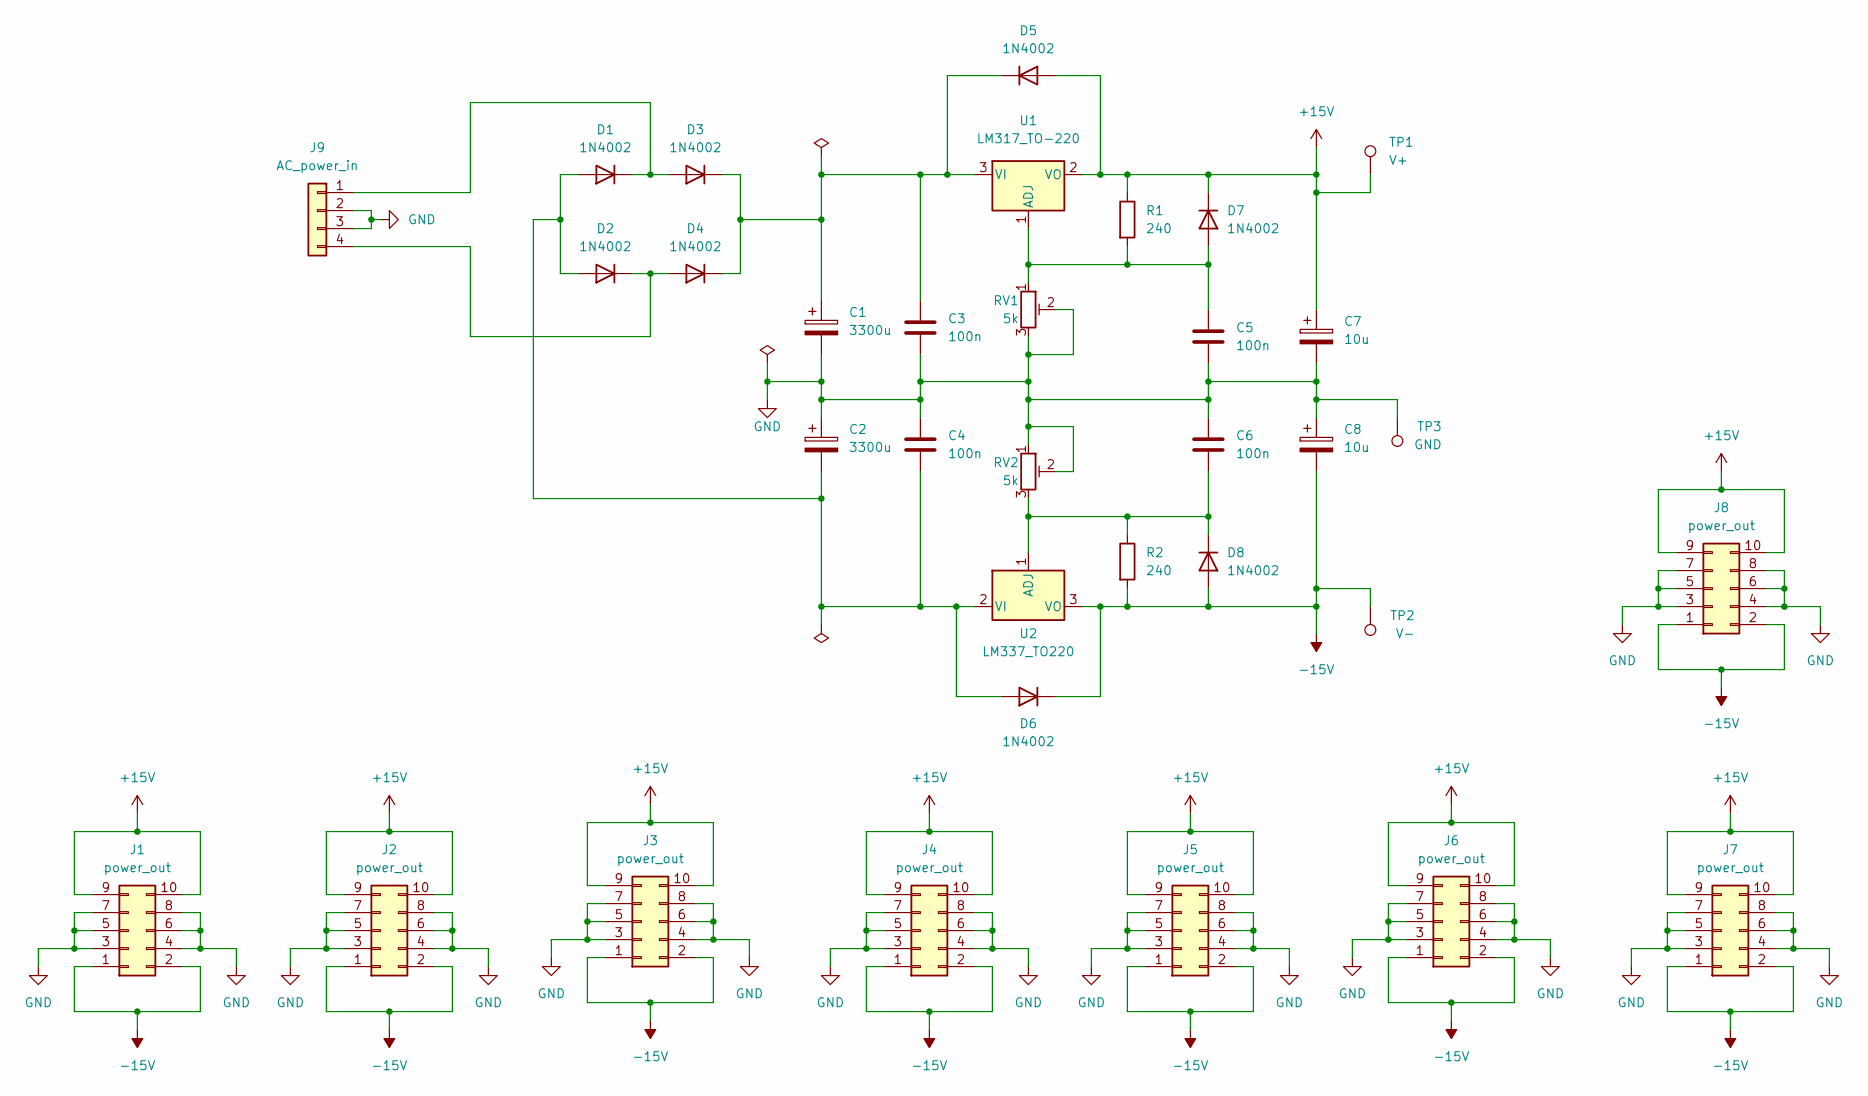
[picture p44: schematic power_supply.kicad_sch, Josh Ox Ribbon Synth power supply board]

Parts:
C1, C2: 3300u; CP_Radial_D18.0mm_P7.50mm
C3, C4, C5, C6: 100n; C_Rect_L7.0mm_W2.5mm_P5.00mm
C7, C8: 10u; CP_Radial_D6.3mm_P2.50mm
D1, D2, D3, D4, D5, D6, D7, D8: 1N4002; D_DO-41_SOD81_P10.16mm_Horizontal
J1, J2, J3, J4, J5, J6, J7, J8: power_out; IDC-Header_2x05_P2.54mm_Vertical
J9: AC_power_in; Molex_Mini-Fit_Jr_5566-04A_2x02_P4.20mm_Vertical
R1, R2: 240; R_Axial_DIN0207_L6.3mm_D2.5mm_P10.16mm_Horizontal
RV1, RV2: 5k; Potentiometer_Bourns_3296W_Vertical
TP1: V+; TestPoint_Keystone_5000-5004_Miniature
TP2: V-; TestPoint_Keystone_5000-5004_Miniature
TP3: GND; TestPoint_Bridge_Pitch7.62mm_Drill1.3mm
U1: LM317_TO-220; TO-220-3_Vertical
U2: LM337_TO220; TO-220-3_Vertical

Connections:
+15V: C7.1, D5.2 (A), D7.1 (K), J1.9, J1.10, J2.9, J2.10, J3.9, J3.10, J4.9, J4.10, J5.9, J5.10, J6.9, J6.10, J7.9, J7.10, J8.9, J8.10, R1.1, TP1.1, U1.2 (VO)
-15V: C8.2, D6.1 (K), D8.2 (A), J1.1, J1.2, J2.1, J2.2, J3.1, J3.2, J4.1, J4.2, J5.1, J5.2, J6.1, J6.2, J7.1, J7.2, J8.1, J8.2, R2.2, TP2.1, U2.3 (VO)
GND: C1.2, C2.1, C3.2, C4.1, C5.2, C6.1, C7.2, C8.1, J1.3, J1.4, J1.5, J1.6, J1.7, J1.8, J2.3, J2.4, J2.5, J2.6, J2.7, J2.8, J3.3, J3.4, J3.5, J3.6, J3.7, J3.8, J4.3, J4.4, J4.5, J4.6, J4.7, J4.8, J5.3, J5.4, J5.5, J5.6, J5.7, J5.8, J6.3, J6.4, J6.5, J6.6, J6.7, J6.8, J7.3, J7.4, J7.5, J7.6, J7.7, J7.8, J8.3, J8.4, J8.5, J8.6, J8.7, J8.8, J9.2, J9.3, RV1.2, RV1.3, RV2.1, RV2.2, TP3.1
unnamed: C1.1, C3.1, D3.1 (K), D4.1 (K), D5.1 (K), U1.3 (VI)
unnamed: C2.2, C4.2, D1.2 (A), D2.2 (A), D6.2 (A), U2.2 (VI)
unnamed: C5.1, D7.2 (A), R1.2, RV1.1, U1.1 (ADJ)
unnamed: C6.2, D8.1 (K), R2.1, RV2.3, U2.1 (ADJ)
unnamed: D1.1 (K), D3.2 (A), J9.1
unnamed: D2.1 (K), D4.2 (A), J9.4

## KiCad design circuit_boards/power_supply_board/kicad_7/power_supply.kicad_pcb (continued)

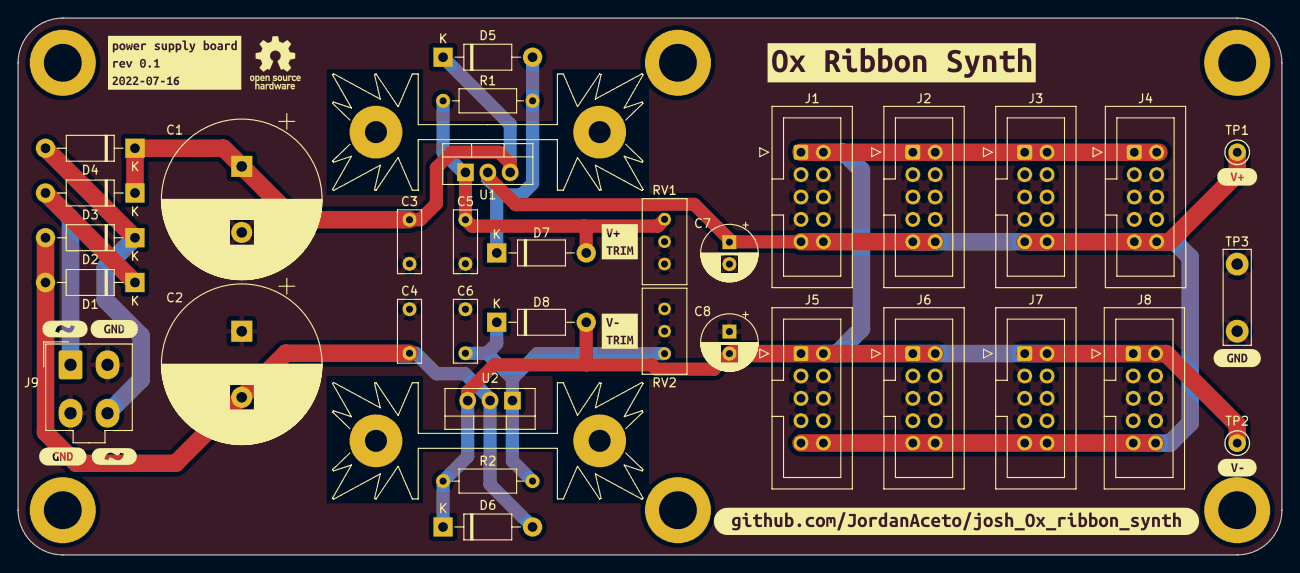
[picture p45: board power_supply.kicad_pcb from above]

Board: 2 copper layers, 143.5 x 61.0 mm, 46 parts (0 on the bottom side), 9 nets.

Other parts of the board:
kibuzzard-62AC7A9F: G***; kibuzzard-62AC7A9F
kibuzzard-62B8A02A, kibuzzard-62B8A02A#2: G***; kibuzzard-62B8A02A
kibuzzard-62B8A297: G***; kibuzzard-62B8A297
kibuzzard-62B89F9F: G***; kibuzzard-62B89F9F
kibuzzard-62B89F93, kibuzzard-62B89F93#2, kibuzzard-62B89F93#3: G***; kibuzzard-62B89F93
kibuzzard-62B89FA9: G***; kibuzzard-62B89FA9
kibuzzard-62B89FC4: G***; kibuzzard-62B89FC4
kibuzzard-62B89FD2: G***; kibuzzard-62B89FD2
kibuzzard-62D2BBF1: G***; kibuzzard-62D2BBF1

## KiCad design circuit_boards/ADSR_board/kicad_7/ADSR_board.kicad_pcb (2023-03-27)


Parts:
C101, C102: 10u; CP_Radial_D6.3mm_P2.50mm
C103, C104: 100n; C_0805_2012Metric
J1: ribbon_port; Molex_KK-254_AE-6410-05A_1x05_P2.54mm_Vertical
J2: modosc_port; Molex_KK-254_AE-6410-02A_1x02_P2.54mm_Vertical
J3: VCO_port; Molex_KK-254_AE-6410-03A_1x03_P2.54mm_Vertical
J4: VCF_port; Molex_KK-254_AE-6410-03A_1x03_P2.54mm_Vertical
J5: power_entry; IDC-Header_2x05_P2.54mm_Vertical
R101, R102: 100k; R_0805_2012Metric
TP1: MOD env; TestPoint_Keystone_5000-5004_Miniature
TP2: inv mod env; TestPoint_Keystone_5000-5004_Miniature
TP3: VCF env; TestPoint_Keystone_5000-5004_Miniature
TP4: VCA env; TestPoint_Keystone_5000-5004_Miniature
TP5: V+; TestPoint_Keystone_5000-5004_Miniature
TP6: GND; TestPoint_Bridge_Pitch7.62mm_Drill1.3mm
TP7: V-; TestPoint_Keystone_5000-5004_Miniature
U101: TL072; SOIC-8_3.9x4.9mm_P1.27mm

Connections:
+15V: C101.1, C103.1, J5.9, J5.10, TP5.1, U101.8 (V+); also elsewhere on the board
-15V: C102.2, C104.2, J5.1, J5.2, TP7.1, U101.4 (V-); also elsewhere on the board
/MOD_ENV_GATE: J1.5; also elsewhere on the board
/VCA_ADSR/OUT: J1.2, TP4.1; also elsewhere on the board
/VCA_ENV_GATE: J1.3; also elsewhere on the board
/VCF_ADSR/OUT: J4.1, TP3.1; also elsewhere on the board
/VCF_ENV_GATE: J1.4; also elsewhere on the board
/modulation_ADSR/OUT: J2.2, J3.1, J4.2, R101.1, TP1.1; also elsewhere on the board
GND: C101.2, C102.1, C103.2, C104.1, J1.1, J2.1, J3.3, J4.3, J5.3, J5.4, J5.5, J5.6, J5.7, J5.8, TP6.1, U101.3 (+), U101.5 (+); also elsewhere on the board
unnamed: J3.2, R102.2, TP2.1, U101.7
unnamed: R101.2, R102.1, U101.6 (-)
unnamed: U101.1, U101.2 (-)


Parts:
C201, C202: 1n; C_0805_2012Metric
C203: 2u2; CP_Radial_D6.3mm_P2.50mm
C204: 22u; CP_Radial_D6.3mm_P2.50mm
C205, C206, C207, C208, C209, C210: 100n; C_0805_2012Metric
D201, D202: 1N4148W; D_SOD-123
Q201: MMBT3904; SOT-23
R201, R202, R211: 100k; R_0805_2012Metric
R203, R204, R212, R214: 10k; R_0805_2012Metric
R205: 5k6; R_0805_2012Metric
R206, R207, R208: 22; R_0805_2012Metric
R209: 100; R_0805_2012Metric
R210: 2k7; R_0805_2012Metric
R213: 2M2; R_0805_2012Metric
RV201, RV202, RV204: 1MA; Potentiometer_Alpha_RD901F-40-00D_Single_Vertical
RV203: 10k; Potentiometer_Alpha_RD901F-40-00D_Single_Vertical
SW201: SW_SPDT; SPDT_mini_toggle
U201: TLC555; SOIC-8_3.9x4.9mm_P1.27mm
U202: CD4052B; SOIC-16_3.9x9.9mm_P1.27mm
U203: TL072; SOIC-8_3.9x4.9mm_P1.27mm
U204: DG470EY; SOIC-8_3.9x4.9mm_P1.27mm

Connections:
+15V: C205.1, C207.1, C209.1, C210.1, R203.1, R204.1, R205.1, RV201.1, U201.4 (R), U201.8 (VCC), U202.16 (VDD), U203.8 (V+), U204.4 (V+); also elsewhere on the board
-15V: C206.2, C208.2, U203.4 (V-), U204.7 (V-); also elsewhere on the board
/MOD_ENV_GATE: R201.1, R202.1; also elsewhere on the board
/modulation_ADSR/OUT: R210.2, U203.1, U203.2 (-); also elsewhere on the board
GND: C202.2, C203.2, C205.2, C206.1, C207.2, C208.1, C209.2, C210.2, D201.2 (A), Q201.2 (E), R201.2, R211.2, R214.2, RV203.1, RV204.1, SW201.2 (B), U201.1 (GND), U202.6 (INH), U202.7 (VEE), U202.8 (VSS), U204.3 (GND), U204.5 (~EN); also elsewhere on the board
unnamed: C201.1, Q201.3 (C), R203.2, U202.10 (A)
unnamed: C201.2, R204.2, U201.2 (TR)
unnamed: C202.1, U201.5 (CV)
unnamed: C203.1, C204.1, R209.2, U201.6 (THR), U203.3 (+)
unnamed: C204.2, SW201.3 (C)
unnamed: D201.1 (K), Q201.1 (B), R202.2
unnamed: D202.1 (K), R214.1, U204.6
unnamed: D202.2 (A), R213.1, U203.7
unnamed: R205.2, RV203.3
unnamed: R206.1, U204.1
unnamed: R206.2, U202.12 (X0)
unnamed: R207.1, RV204.2, RV204.3
unnamed: R207.2, U202.11 (X3), U202.14 (X1)
unnamed: R208.1, U202.15 (X2)
unnamed: R208.2, RV201.2, RV201.3
unnamed: R209.1, U202.13 (X)
unnamed: R210.1, R211.1, U203.6 (-)
unnamed: R212.1, RV202.1, RV203.2, U204.8
unnamed: R212.2, R213.2, U203.5 (+)
unnamed: RV202.2, RV202.3, U204.2
unnamed: U201.3 (Q), U202.9 (B)

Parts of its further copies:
C301, C302, C401, C402: 1n; C_0805_2012Metric
C303, C403: 2u2; CP_Radial_D6.3mm_P2.50mm
C304, C404: 22u; CP_Radial_D6.3mm_P2.50mm
C305, C306, C307, C308, C309, C310, C405, C406, C407, C408, C409, C410: 100n; C_0805_2012Metric
D301, D302, D401, D402: 1N4148W; D_SOD-123
Q301, Q401: MMBT3904; SOT-23
R301, R302, R311, R401, R402, R411: 100k; R_0805_2012Metric
R303, R304, R312, R314, R403, R404, R412, R414: 10k; R_0805_2012Metric
R305, R405: 5k6; R_0805_2012Metric
R306, R307, R308, R406, R407, R408: 22; R_0805_2012Metric
R309, R409: 100; R_0805_2012Metric
R310, R410: 2k7; R_0805_2012Metric
R313, R413: 2M2; R_0805_2012Metric
RV301, RV302, RV304, RV401, RV402, RV404: 1MA; Potentiometer_Alpha_RD901F-40-00D_Single_Vertical
RV303, RV403: 10k; Potentiometer_Alpha_RD901F-40-00D_Single_Vertical
SW301, SW401: SW_SPDT; SPDT_mini_toggle
U301, U401: TLC555; SOIC-8_3.9x4.9mm_P1.27mm
U302, U402: CD4052B; SOIC-16_3.9x9.9mm_P1.27mm
U303, U403: TL072; SOIC-8_3.9x4.9mm_P1.27mm
U304, U404: DG470EY; SOIC-8_3.9x4.9mm_P1.27mm

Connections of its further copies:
+15V: C305.1, C307.1, C309.1, C310.1, C405.1, C407.1, C409.1, C410.1, R303.1, R304.1, R305.1, R403.1, R404.1, R405.1, RV301.1, RV401.1, U301.4 (R), U301.8 (VCC), U302.16 (VDD), U303.8 (V+), U304.4 (V+), U401.4 (R), U401.8 (VCC), U402.16 (VDD), U403.8 (V+), U404.4 (V+); also elsewhere on the board
-15V: C306.2, C308.2, C406.2, C408.2, U303.4 (V-), U304.7 (V-), U403.4 (V-), U404.7 (V-); also elsewhere on the board
/VCA_ADSR/OUT: R410.2, U403.1, U403.2 (-); also elsewhere on the board
/VCA_ENV_GATE: R401.1, R402.1; also elsewhere on the board
/VCF_ADSR/OUT: R310.2, U303.1, U303.2 (-); also elsewhere on the board
/VCF_ENV_GATE: R301.1, R302.1; also elsewhere on the board
GND: C302.2, C303.2, C305.2, C306.1, C307.2, C308.1, C309.2, C310.2, C402.2, C403.2, C405.2, C406.1, C407.2, C408.1, C409.2, C410.2, D301.2 (A), D401.2 (A), Q301.2 (E), Q401.2 (E), R301.2, R311.2, R314.2, R401.2, R411.2, R414.2, RV303.1, RV304.1, RV403.1, RV404.1, SW301.2 (B), SW401.2 (B), U301.1 (GND), U302.6 (INH), U302.7 (VEE), U302.8 (VSS), U304.3 (GND), U304.5 (~EN), U401.1 (GND), U402.6 (INH), U402.7 (VEE), U402.8 (VSS), U404.3 (GND), U404.5 (~EN); also elsewhere on the board
unnamed: C301.1, Q301.3 (C), R303.2, U302.10 (A)
unnamed: C301.2, R304.2, U301.2 (TR)
unnamed: C302.1, U301.5 (CV)
unnamed: C303.1, C304.1, R309.2, U301.6 (THR), U303.3 (+)
unnamed: C304.2, SW301.3 (C)
unnamed: C401.1, Q401.3 (C), R403.2, U402.10 (A)
unnamed: C401.2, R404.2, U401.2 (TR)
unnamed: C402.1, U401.5 (CV)
unnamed: C403.1, C404.1, R409.2, U401.6 (THR), U403.3 (+)
unnamed: C404.2, SW401.3 (C)
unnamed: D301.1 (K), Q301.1 (B), R302.2
unnamed: D302.1 (K), R314.1, U304.6
unnamed: D302.2 (A), R313.1, U303.7
unnamed: D401.1 (K), Q401.1 (B), R402.2
unnamed: D402.1 (K), R414.1, U404.6
unnamed: D402.2 (A), R413.1, U403.7
unnamed: R305.2, RV303.3
unnamed: R306.1, U304.1
unnamed: R306.2, U302.12 (X0)
unnamed: R307.1, RV304.2, RV304.3
unnamed: R307.2, U302.11 (X3), U302.14 (X1)
unnamed: R308.1, U302.15 (X2)
unnamed: R308.2, RV301.2, RV301.3
unnamed: R309.1, U302.13 (X)
unnamed: R310.1, R311.1, U303.6 (-)
unnamed: R312.1, RV302.1, RV303.2, U304.8
unnamed: R312.2, R313.2, U303.5 (+)
unnamed: R405.2, RV403.3
unnamed: R406.1, U404.1
unnamed: R406.2, U402.12 (X0)
unnamed: R407.1, RV404.2, RV404.3
unnamed: R407.2, U402.11 (X3), U402.14 (X1)
unnamed: R408.1, U402.15 (X2)
unnamed: R408.2, RV401.2, RV401.3
unnamed: R409.1, U402.13 (X)
unnamed: R410.1, R411.1, U403.6 (-)
unnamed: R412.1, RV402.1, RV403.2, U404.8
unnamed: R412.2, R413.2, U403.5 (+)
unnamed: RV302.2, RV302.3, U304.2
unnamed: RV402.2, RV402.3, U404.2
unnamed: U301.3 (Q), U302.9 (B)
unnamed: U401.3 (Q), U402.9 (B)

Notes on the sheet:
range: [0v, +10v]
DECAY
RELEASE
SUSTAIN
ATTACK
short/long
The comparator and analog switch ensure that when the ADSR is in the sustain phase the SUSTAIN pot responds quickly to the user adjusting the knob. Otherwise if the DECAY pot is set to a long time constant, the SUSTAIN pot will respond sluggishly when adjusted.
approx. threshold: +2.5v
1 any 0 1 0 0
4052 logic: A B -------------- At rest/release Attack Decay/Sustain



Board: 2 copper layers, 172.7 x 107.9 mm, 156 parts (141 on the bottom side), 75 nets.

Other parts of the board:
kibuzzard-62AC7A9F: G***; kibuzzard-62AC7A9F
kibuzzard-62AC77C9: G***; kibuzzard-62AC77C9
kibuzzard-62AC77E4: G***; kibuzzard-62AC77E4
kibuzzard-62AC77FB: G***; kibuzzard-62AC77FB
kibuzzard-62AC78CB: G***; kibuzzard-62AC78CB
kibuzzard-62AC79A3: G***; kibuzzard-62AC79A3
kibuzzard-62AC79C5: G***; kibuzzard-62AC79C5
kibuzzard-62AC755C, kibuzzard-62AC755C#2, kibuzzard-62AC755C#3, kibuzzard-62AC755C#4, kibuzzard-62AC755C#5, kibuzzard-62AC755C#6: G***; kibuzzard-62AC755C
kibuzzard-62AC758B, kibuzzard-62AC758B#2: G***; kibuzzard-62AC758B
kibuzzard-62AC762D: G***; kibuzzard-62AC762D
kibuzzard-62AC769B: G***; kibuzzard-62AC769B
kibuzzard-62AC791A, kibuzzard-62AC791A#2: G***; kibuzzard-62AC791A
kibuzzard-62AC792A, kibuzzard-62AC792A#2: G***; kibuzzard-62AC792A
kibuzzard-62AC7596: G***; kibuzzard-62AC7596
kibuzzard-62AC7711: G***; kibuzzard-62AC7711
kibuzzard-62AC7737: G***; kibuzzard-62AC7737
kibuzzard-62AC7758: G***; kibuzzard-62AC7758
kibuzzard-62AC7771: G***; kibuzzard-62AC7771
kibuzzard-62AC7810: G***; kibuzzard-62AC7810
kibuzzard-62AC7972: G***; kibuzzard-62AC7972
kibuzzard-62AC7989: G***; kibuzzard-62AC7989

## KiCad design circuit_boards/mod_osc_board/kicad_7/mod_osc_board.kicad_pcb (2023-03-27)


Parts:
J1: ext_port; Molex_KK-254_AE-6410-03A_1x03_P2.54mm_Vertical
J2: ribbon_board_port; Molex_KK-254_AE-6410-03A_1x03_P2.54mm_Vertical
J3: adsr_board_port; Molex_KK-254_AE-6410-02A_1x02_P2.54mm_Vertical
J4: vco_board_port; Molex_KK-254_AE-6410-02A_1x02_P2.54mm_Vertical
J5: vcf_board_port; Molex_KK-254_AE-6410-02A_1x02_P2.54mm_Vertical
RV101, RV102: 10k; Potentiometer_P260T
SW101: SW_SPDT_MSM; SPDT_mini_toggle
TP101: square_out; TestPoint_Keystone_5000-5004_Miniature
TP102: modosc_out; TestPoint_Keystone_5000-5004_Miniature

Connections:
+5V: RV101.3, RV102.1, SW101.1; also elsewhere on the board
-5V: RV101.1, SW101.3; also elsewhere on the board
/MOD_ADSR: J3.1, RV102.3
/MOD_OSC_OUT: J1.1, J4.1, J5.1, TP102.1; also elsewhere on the board
/VCO_core/COARSE_TUNE_IN: RV101.2; also elsewhere on the board
/VCO_core/RANGE_CV_IN: SW101.2; also elsewhere on the board
/VCO_core/SQUARE_OUT: J2.2, TP101.1; also elsewhere on the board
/VCO_core/VOLUME_CV_IN: RV102.2; also elsewhere on the board
/VCO_core/V_PER_OCT_IN_1: J1.2; also elsewhere on the board
/VCO_core/V_PER_OCT_IN_2: J2.1; also elsewhere on the board

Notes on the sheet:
Range switch 1) +5 octave 2) normal 3) -5 octaves
Modulation delay


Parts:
C201: 10u; C_0805_2012Metric
C202: 47n COG; C_0805_2012Metric
C203: 10n; C_0805_2012Metric
C204: 100p; C_0805_2012Metric
D201, D202: 1N4148W; D_SOD-123
JP201: saw_pol; SolderJumper-3_P1.3mm_Bridged12_RoundedPad1.0x1.5mm
R201, R208, R216, R220: 10k; R_0805_2012Metric
R202: 27k; R_0805_2012Metric
R203: 150k; R_0805_2012Metric
R204, R205, R206, R207, R222, R223, R224: 100k; R_0805_2012Metric
R209: 1M; R_0805_2012Metric
R210: 270k; R_0805_2012Metric
R211: 47k; R_0805_2012Metric
R212: 270; R_0805_2012Metric
R213, R215, R218: 4k7; R_0805_2012Metric
R214: 3k9; R_0805_2012Metric
R217: 12k; R_0805_2012Metric
R219, R221: 200k; R_0805_2012Metric
R225: 18k; R_0805_2012Metric
RV201, RV202, RV203: 5k; Potentiometer_Bourns_3296W_Vertical
SW201: alpha_SR2612F-0112; apha_SR2612F-0112
U201: SSI2130; PQN32_HandSoldering
U202, U301: TL072; SO-8_5.3x6.2mm_P1.27mm

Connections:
+2V5_REF: R202.2, R209.2, R216.1, R217.2, RV201.3, RV202.2, RV202.3, U201.23 (vref); also elsewhere on the board
+5V: C201.2, D201.1 (K), JP201.3 (B), R213.2; also elsewhere on the board
-5V: R221.1; also elsewhere on the board
/VCO_core/COARSE_TUNE_IN: R203.2; also elsewhere on the board
/VCO_core/INV_SAW: C204.2, R224.2, U201.5 (aux_in_2), U202.1
/VCO_core/RANGE_CV_IN: R204.2; also elsewhere on the board
/VCO_core/SINE: U201.4 (aux_in_1), U201.24 (sine_out)
/VCO_core/SQUARE_OUT: U301.1, U301.2 (-); also elsewhere on the board
/VCO_core/SWITCHED_OUT: R225.2, U201.25 (mix_out); also elsewhere on the board
/VCO_core/VOLUME_CV_IN: R219.1; also elsewhere on the board
/VCO_core/V_PER_OCT_IN_1: R205.2; also elsewhere on the board
/VCO_core/V_PER_OCT_IN_2: R206.2; also elsewhere on the board
unnamed: C201.1, R201.1
unnamed: C203.1, R212.2
unnamed: D201.2 (A), D202.1 (K), R201.2, R208.1, U201.17 (hard_sync)
unnamed: JP201.2 (C), U201.18 (time_rev)
unnamed: R207.2, RV201.2
unnamed: R210.1, RV203.2
unnamed: R211.1, RV202.1
unnamed: R219.2, SW201.13
unnamed: RV203.3, U201.6 (hf_track)
unnamed: R209.1, U201.21 (lin_freq)
unnamed: R213.1, U201.28 (square_out), U301.3 (+)
unnamed: C202.1, U201.14 (tcap)
unnamed: R214.2, U201.1 (tri_out), U201.31 (pwm_in_-)
unnamed: R222.1, R223.1, U201.29 (saw_out)
unnamed: R216.2, R220.1, U201.32 (pwm_in_+)
unnamed: R212.1, U201.26 (bw_comp)
unnamed: R202.1, R203.1, R204.1, R205.1, R206.1, R207.1, R210.2, U201.7 (expo_freq)
unnamed: R211.2, U201.22 (expo_scale)
unnamed: R214.1, R215.2, U201.2 (sine_in_+)
unnamed: R217.1, R218.2, U201.3 (sine_in_-)
unnamed: SW201.1, U201.12 (aux_1_mix)
unnamed: SW201.4, U201.13 (aux_2_mix)
unnamed: SW201.5, U201.11 (pulse_mix)
unnamed: SW201.3, U201.10 (saw_mix)
unnamed: SW201.2, U201.9 (tri_mix)
unnamed: C204.1, R221.2, R222.2, R223.2, R224.1, U202.2 (-)

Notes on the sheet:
Waveform Select Switch 1) Sine 2) Triangle 3) Up Saw 4) Down Saw 5) Square
high freq trim
Pulse is set to 50% duty cycle
expo scale trim
Sync "kick start" circuit to ensure that the VCO starts up.
base freq trim


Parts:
D401: red_green; LED_D5.0mm
R401: 1k2; R_0805_2012Metric
U301: TL072; SO-8_5.3x6.2mm_P1.27mm

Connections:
/MOD_OSC_OUT: U301.5 (+); also elsewhere on the board
unnamed 19: D401.2 (AK), U301.7; also elsewhere on the board
unnamed 20: D401.1 (KA), R401.2, U301.6 (-); also elsewhere on the board


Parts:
C301: 100p; C_0805_2012Metric
R301: 47k; R_0805_2012Metric
R302: 200k; R_0805_2012Metric
U202: TL072; SO-8_5.3x6.2mm_P1.27mm

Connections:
/MOD_OSC_OUT: C301.2, R302.2, U202.7; also elsewhere on the board
/VCO_core/SWITCHED_OUT: R301.1; also elsewhere on the board
unnamed: C301.1, R301.2, R302.1, U202.6 (-)

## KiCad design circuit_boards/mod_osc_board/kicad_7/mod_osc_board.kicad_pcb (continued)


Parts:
C501, C502: 470n; C_0805_2012Metric
C503, C504, C507, C508, C509, C510, C511, C512, C513: 100n; C_0805_2012Metric
C505, C506: 10u; CP_Radial_D6.3mm_P2.50mm
J6: power_entry; IDC-Header_2x05_P2.54mm_Vertical
R501: 1k8; R_0805_2012Metric
TP501: V+; TestPoint_Keystone_5000-5004_Miniature
TP502: V-; TestPoint_Keystone_5000-5004_Miniature
TP503: GND; TestPoint_Bridge_Pitch7.62mm_Drill1.3mm
TP504: +5v; TestPoint_Keystone_5000-5004_Miniature
TP505: -5v; TestPoint_Keystone_5000-5004_Miniature
TP506: 2v5_ref; TestPoint_Keystone_5000-5004_Miniature
U201: SSI2130; PQN32_HandSoldering
U202, U301: TL072; SO-8_5.3x6.2mm_P1.27mm
U501: L78L05_SOT89; SOT-89-3
U502: L79L05_SOT89; SOT-89-3
U503: LM4040C-2.5; SOT-23

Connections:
+2V5_REF: C507.1, R501.2, TP506.1, U503.1 (K); also elsewhere on the board
+5V: C503.1, C508.1, R501.1, TP504.1, U201.27 (V+), U501.1 (OUT); also elsewhere on the board
+15V: C501.1, C505.1, C510.1, C512.1, J6.9, J6.10, TP501.1, U202.8 (V+), U301.8 (V+), U501.3 (IN)
-5V: C504.2, C509.2, TP505.1, U201.8 (V-), U502.3 (VO); also elsewhere on the board
-15V: C502.2, C506.2, C511.2, C513.2, J6.1, J6.2, TP502.1, U202.4 (V-), U301.4 (V-), U502.2 (VI)

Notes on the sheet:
2130 Decoupling
Opamp Decoupling
2130 Power
Opamp Power
Bulk Decoupling

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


Board: 2 copper layers, 123.2 x 76.2 mm, 113 parts (108 on the bottom side), 46 nets.

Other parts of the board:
kibuzzard-62AC7A9F: G***; kibuzzard-62AC7A9F
kibuzzard-62AC7C76, kibuzzard-62AC7C76#2, kibuzzard-62AC7C76#3: G***; kibuzzard-62AC7C76
kibuzzard-62AC7CCE: G***; kibuzzard-62AC7CCE
kibuzzard-62AC7CEB: G***; kibuzzard-62AC7CEB
kibuzzard-62AC7D00: G***; kibuzzard-62AC7D00
kibuzzard-62AC7D1D: G***; kibuzzard-62AC7D1D
kibuzzard-62AC7D8B: G***; kibuzzard-62AC7D8B
kibuzzard-62AC7D30: G***; kibuzzard-62AC7D30
kibuzzard-62AC7D44: G***; kibuzzard-62AC7D44
kibuzzard-62AC7D55: G***; kibuzzard-62AC7D55
kibuzzard-62AC7D68: G***; kibuzzard-62AC7D68
kibuzzard-62AC7D79: G***; kibuzzard-62AC7D79
kibuzzard-62AC7DA9: G***; kibuzzard-62AC7DA9
kibuzzard-62AC7DB6: G***; kibuzzard-62AC7DB6
kibuzzard-62AC7DF7: G***; kibuzzard-62AC7DF7
kibuzzard-62AC7EA8: G***; kibuzzard-62AC7EA8
kibuzzard-62AC7EE1: G***; kibuzzard-62AC7EE1
kibuzzard-62AC7EFA: G***; kibuzzard-62AC7EFA
kibuzzard-62AC7F0B: G***; kibuzzard-62AC7F0B
kibuzzard-62AC78CB: G***; kibuzzard-62AC78CB
kibuzzard-62AC755C, kibuzzard-62AC755C#2, kibuzzard-62AC755C#3, kibuzzard-62AC755C#4, kibuzzard-62AC755C#5, kibuzzard-62AC755C#6, kibuzzard-62AC755C#7: G***; kibuzzard-62AC755C
kibuzzard-62AC791A, kibuzzard-62AC791A#2: G***; kibuzzard-62AC791A
kibuzzard-62AC792A, kibuzzard-62AC792A#2: G***; kibuzzard-62AC792A
kibuzzard-62AC911A: G***; kibuzzard-62AC911A
kibuzzard-62ACB089: G***; kibuzzard-62ACB089
locked: red_green; LED_D5.0mm

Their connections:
unnamed 19: locked.2 (AK); also elsewhere on the board
unnamed 20: locked.1 (KA); also elsewhere on the board

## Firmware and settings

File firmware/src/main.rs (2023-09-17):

#![no_std]
#![no_main]

mod board;
mod ui;

use synth_utils::{mono_midi_receiver, quantizer, ribbon_controller};

use crate::{
    board::{AdcPin, Board, Dac8164Channel},
    ui::{LevelPot, PitchMode, UiState},
};

use panic_halt as _;

use cortex_m_rt::entry;

const FAST_RIBBON_SAMPLE_RATE: u32 = board::TIM2_FREQ_HZ;

const RIBBON_PIN: AdcPin = AdcPin::PA4;

const RIBBON_BUFF_CAPACITY: usize =
    ribbon_controller::sample_rate_to_capacity(FAST_RIBBON_SAMPLE_RATE);

// 4 octaves of range
const MAIN_RIBBON_NUM_SEMITONES: f32 = 49.0_f32;
// a small fudge factor is added to make sure we can hit the highest note
const RIBBON_FUDGE_FACTOR: f32 = quantizer::SEMITONE_WIDTH;
const MAIN_RIBBON_MAX_VOUT: f32 = MAIN_RIBBON_NUM_SEMITONES / 12.0_f32 + RIBBON_FUDGE_FACTOR;

#[entry]
fn main() -> ! {
    let mut board = Board::init();
    let mut ui = UiState::new();

    // we need to use the sample rate for both the parameter and argument, if
    // rust support for generic expressions improves then this should be refactored
    let mut ribbon = ribbon_controller::RibbonController::<RIBBON_BUFF_CAPACITY>::new(
        FAST_RIBBON_SAMPLE_RATE as f32,
        19_354.0_f32, // end-to-end resistance of the softpot as measured
        12_014.0_f32, // resistance of the series resistor going to vref as measured
        1E6,          // pullup resistor from the wiper to the positive voltage refererence
    );

    let mut vco_quantizer = quantizer::Quantizer::new();

    let mut midi_receiver = mono_midi_receiver::MonoMidiReceiver::new(0);

    midi_receiver.set_note_priority(mono_midi_receiver::NotePriority::Last);

    let mut offset_when_finger_pressed_down: f32 = 0.0_f32;

    // small delay to allow the ribbon voltage to settle before beginning
    board.delay_ms(100);

    ui.update(&mut board);

    loop {
        if let Some(b) = board.serial_read() {
            midi_receiver.parse(b)
        }

        // slow timer for updating UI, reading pots and such
        if board.get_tim6_timeout() {
            ui.update(&mut board);
        }

        // fast timer for polling the ribbon
        if board.get_tim2_timeout() {
            let raw_adc_val = board.read_adc(RIBBON_PIN);
            ribbon.poll(raw_adc_val);
        }

        // timer to update analog and MIDI outputs
        if board.get_tim15_timeout() {
            // expand the ribbon signal to 1volt/octave range
            let ribbon_as_1v_per_oct = ribbon_to_dac8164_1v_per_oct(ribbon.value());

            // attenuate the ribbon signals with the front panel controls
            let vco_ribbon_contrib = ui.attenuate(ribbon_as_1v_per_oct, LevelPot::Vco);
            let modosc_ribbon_contrib = ui.attenuate(ribbon_as_1v_per_oct, LevelPot::ModOsc);
            let vcf_ribbon_contrib = ui.attenuate(ribbon_as_1v_per_oct, LevelPot::Vcf);
            let delay_ribbon_contrib = ui.attenuate(ribbon_as_1v_per_oct, LevelPot::Delay);

            // only the VCO signal gets quantized, little offset added in makes the range feel right to the user
            let quantized_vco_ribbon = vco_quantizer
                .convert(vco_ribbon_contrib + quantizer::HALF_SEMITONE_WIDTH / 2.0_f32);

            let finger_just_pressed = ribbon.finger_just_pressed();

            // the VCO can be one of three modes
            let vco_ribbon_contrib = match ui.pitch_mode() {
                // hard-quantize and smooth modes are simple to calculate
                PitchMode::HardQuantize => quantized_vco_ribbon.stairstep,
                PitchMode::Smooth => {
                    // a small fudge factor helps keep smooth mode in tune with the other modes
                    let fudge_factor = quantizer::HALF_SEMITONE_WIDTH;
                    vco_ribbon_contrib - fudge_factor
                }
                // assist mode has more going on
                PitchMode::Assist => {
                    if finger_just_pressed {
                        // When the user first presses down after having lifted their finger record the offset between the
                        // finger position and the center of the note. We'll use this offset to make sure that it plays
                        // a nice in-tune note at first-press.
                        offset_when_finger_pressed_down = quantized_vco_ribbon.fraction;
                        // use the stairstep for the first press for a nice in-tune note
                        quantized_vco_ribbon.stairstep
                    } else {
                        // The user is continuing to press the ribbon and maybe sliding around, use the smooth val but
                        // remove the offset
                        vco_ribbon_contrib - offset_when_finger_pressed_down
                    }
                }
            };

            let midi_1v_per_oct = note_num_to_dac8164_1v_per_oct(midi_receiver.note_num())
                + (midi_receiver.pitch_bend() * 2.0_f32 / 12.0_f32);

            // VCO always gets un-attenuated MIDI note information so it plays in-tune
            let vco_midi_contrib = midi_1v_per_oct;
            // MODOSC, VCF, and deley attenuate the MIDI pitch signal with the same knob used to attenuate the ribbon
            let modosc_midi_contrib = ui.attenuate(midi_1v_per_oct, LevelPot::ModOsc);
            let vcf_midi_contrib = ui.attenuate(midi_1v_per_oct, LevelPot::Vcf);
            let delay_midi_contrib = ui.attenuate(midi_1v_per_oct, LevelPot::Delay);

            let final_vco_ribbon = vco_ribbon_contrib + vco_midi_contrib;
            let final_modosc_ribbon = modosc_ribbon_contrib + modosc_midi_contrib;
            let final_vcf_ribbon = vcf_ribbon_contrib + vcf_midi_contrib;
            let final_delay_ribbon = delay_ribbon_contrib + delay_midi_contrib;

            // set the analog outputs
            board.dac8164_set_vout(final_vco_ribbon, Dac8164Channel::A);
            board.dac8164_set_vout(final_modosc_ribbon, Dac8164Channel::B);
            board.dac8164_set_vout(final_vcf_ribbon, Dac8164Channel::C);
            board.dac8164_set_vout(final_delay_ribbon, Dac8164Channel::D);

            // set the gate high with either the ribbon or MIDI signal
            board.set_gate(ribbon.finger_is_pressing() | midi_receiver.gate());
        }
    }
}

/// `ribbon_to_dac8164_1v_per_oct(r)` is the ribbon value in `[0.0, 1.0]` scaled to 1 volt per octave
fn ribbon_to_dac8164_1v_per_oct(ribb: f32) -> f32 {
    ribb * MAIN_RIBBON_MAX_VOUT
}

/// `note_num_to_dac8164_1v_per_oct(n)` is the note number `n` scaled to 1volt/octave
fn note_num_to_dac8164_1v_per_oct(note_num: u8) -> f32 {
    note_num as f32 / 12.0_f32
}

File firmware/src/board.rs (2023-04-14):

use stm32l4xx_hal::{
    adc::{SampleTime, Sequence, ADC},
    delay::Delay,
    device::SPI1,
    gpio::{Alternate, Input, Output, Pin, PullUp, PushPull, H8, L8},
    hal::spi::{Mode, Phase, Polarity},
    pac::{ADC1, DMA1, TIM15, TIM2, TIM6, USART1},
    prelude::*,
    serial,
    spi::Spi,
    timer::Timer,
};

// type aliase so clippy doesn't complain, pins are as required by the physical PCB layout
type SpiBus = Spi<
    SPI1,
    (
        Pin<Alternate<PushPull, 5>, L8, 'B', 3>,
        Pin<Alternate<PushPull, 5>, L8, 'B', 4>,
        Pin<Alternate<PushPull, 5>, L8, 'B', 5>,
    ),
>;

/// The physical board structure is represented here
pub struct Board {
    // USART for MIDI
    _midi_tx: serial::Tx<USART1>,
    midi_rx: serial::Rx<USART1>,

    // SPI for DAC
    spi: SpiBus,
    nss: Pin<Output<PushPull>, H8, 'A', 15>, // manual chip select

    // general purpose delay
    delay: Delay,

    // 2 pins for the 3-position QUANTIZE MODE switch
    mode_switch: (
        Pin<Input<PullUp>, L8, 'B', 6>,
        Pin<Input<PullUp>, L8, 'B', 7>,
    ),

    // ribbon gate output
    gate_pin: Pin<Output<PushPull>, L8, 'A', 5>,
}

impl Board {
    /// `Board::init()` is the board structure with all peripherals initialized.
    pub fn init() -> Self {
        ////////////////////////////////////////////////////////////////////////
        //
        // general peripheral housekeeping, core peripherals and clocks
        //
        ////////////////////////////////////////////////////////////////////////
        let cp = cortex_m::Peripherals::take().unwrap();
        let dp = stm32l4xx_hal::pac::Peripherals::take().unwrap();
        let mut flash = dp.FLASH.constrain();
        let mut rcc = dp.RCC.constrain();
        let mut pwr = dp.PWR.constrain(&mut rcc.apb1r1);

        let clocks = rcc
            .cfgr
            .sysclk(SYST_CLK_FREQ_MHZ.MHz())
            .pclk1(SYST_CLK_FREQ_MHZ.MHz())
            .pclk2(SYST_CLK_FREQ_MHZ.MHz())
            .freeze(&mut flash.acr, &mut pwr);

        let mut gpioa = dp.GPIOA.split(&mut rcc.ahb2);
        let mut gpiob = dp.GPIOB.split(&mut rcc.ahb2);

        let dma_channels = dp.DMA1.split(&mut rcc.ahb1);

        let mut delay = Delay::new(cp.SYST, clocks);

        ////////////////////////////////////////////////////////////////////////
        //
        // ADC
        //
        ////////////////////////////////////////////////////////////////////////

        // gpio pins which are configured as analog inputs on the physical PCB
        let mut adc_pins = (
            gpioa.pa0.into_analog(&mut gpioa.moder, &mut gpioa.pupdr),
            gpioa.pa1.into_analog(&mut gpioa.moder, &mut gpioa.pupdr),
            gpioa.pa2.into_analog(&mut gpioa.moder, &mut gpioa.pupdr),
            gpioa.pa3.into_analog(&mut gpioa.moder, &mut gpioa.pupdr),
            gpioa.pa4.into_analog(&mut gpioa.moder, &mut gpioa.pupdr),
        );

        // configure DMA1 to transfer ADC readings to the buffer
        let mut dma1_ch1 = dma_channels.1;
        unsafe {
            dma1_ch1.set_peripheral_address(&dp.ADC1.dr as *const _ as u32, false);
            dma1_ch1.set_memory_address(ADC_DMA_BUFF.as_ptr() as u32, true);
        }
        dma1_ch1.set_transfer_length(NUM_ADC_DMA_SIGNALS as u16);
        unsafe {
            (*DMA1::ptr()).ccr1.modify(|_, w| {
                w.msize()
                    .bits16()
                    .psize()
                    .bits16()
                    .minc()
                    .enabled()
                    .circ()
                    .enabled()
                    .en()
                    .set_bit()
            });
        }

        // configure the ADC
        let mut adc1 = ADC::new(
            dp.ADC1,
            dp.ADC_COMMON,
            &mut rcc.ahb2,
            &mut rcc.ccipr,
            &mut delay,
        );
        adc1.configure_sequence(&mut adc_pins.0, Sequence::One, SampleTime::Cycles640_5);
        adc1.configure_sequence(&mut adc_pins.1, Sequence::Two, SampleTime::Cycles640_5);
        adc1.configure_sequence(&mut adc_pins.2, Sequence::Three, SampleTime::Cycles640_5);
        adc1.configure_sequence(&mut adc_pins.3, Sequence::Four, SampleTime::Cycles640_5);
        adc1.configure_sequence(&mut adc_pins.4, Sequence::Five, SampleTime::Cycles640_5);
        unsafe {
            // configure hardware oversampler for 16 bit resolution
            (*ADC1::ptr()).cfgr2.modify(|_, w| {
                w.ovss()
                    .bits(0b0001) // shift right by 1
                    .ovsr()
                    .bits(0b100) // oversample 32x
                    .rovse()
                    .set_bit()
            });
            // enable continuous DMA mode
            (*ADC1::ptr())
                .cfgr
                .modify(|_, w| w.dmacfg().set_bit().dmaen().set_bit().cont().set_bit());
        }

        dma1_ch1.start();
        adc1.start_conversion();

        ////////////////////////////////////////////////////////////////////////
        //
        // TIMx periodic timers
        //
        ////////////////////////////////////////////////////////////////////////
        let _tim2 = Timer::tim2(dp.TIM2, TIM2_FREQ_HZ.Hz(), clocks, &mut rcc.apb1r1);

        let _tim6 = Timer::tim6(dp.TIM6, TIM6_FREQ_HZ.Hz(), clocks, &mut rcc.apb1r1);

        let _tim15 = Timer::tim15(dp.TIM15, TIM15_FREQ_HZ.Hz(), clocks, &mut rcc.apb2);

        ////////////////////////////////////////////////////////////////////////
        //
        // USART
        //
        ////////////////////////////////////////////////////////////////////////

        // configure DMA1 to transmit bytes via the UART
        let mut dma1_ch4 = dma_channels.4;
        unsafe {
            dma1_ch4.set_peripheral_address(&dp.USART1.tdr as *const _ as u32, false);
            dma1_ch4.set_memory_address(MIDI_USART_DMA_BUFF.as_ptr() as u32, true);
        }
        unsafe {
            (*DMA1::ptr()).ccr4.modify(|_, w| {
                w.pl()
                    .high()
                    .msize()
                    .bits8()
                    .psize()
                    .bits8()
                    .minc()
                    .enabled()
                    .dir()
                    .from_memory()
            });
            // map DMA channel 4 to UART tx
            (*DMA1::ptr()).cselr.modify(|_, w| w.c4s().bits(0b0010));
        }

        let tx_pin = gpioa
            .pa9
            .into_alternate(&mut gpioa.moder, &mut gpioa.otyper, &mut gpioa.afrh);
        let rx_pin =
            gpioa
                .pa10
                .into_alternate(&mut gpioa.moder, &mut gpioa.otyper, &mut gpioa.afrh);

        let usart = serial::Serial::usart1(
            dp.USART1,
            (tx_pin, rx_pin),
            serial::Config::default().baudrate(MIDI_BAUD_RATE_HZ.bps()),
            clocks,
            &mut rcc.apb2,
        );
        let (tx, rx) = usart.split();
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

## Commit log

2018-12-15 initial commit, add adsr/pwm lfo board
    [vc_adsr.sch]
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2018-12-15 add modulation/ring mod board
    [modulation-ring_mod_board.sch]
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2018-12-15 add sub osc board
    [sub_osc_board.sch]
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2022-06-01 Begin big summer 22 refurb
    [CV_mixer.kicad_sch, PWM_mixer.kicad_sch, SVF.kicad_sch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]
2022-06-06 Progress on refurb boards, all incomplete and messy still
    [ADSR.kicad_sch, ADSR_board.kicad_pcb, ADSR_board.kicad_sch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]
2022-06-09 Initial S&H board layout
    [noise_generator.kicad_sch, power_supply.kicad_sch, s&h_mixer.kicad_sch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]
2022-06-09 Initial VCF/VCA board layout
    [CV_mixer.kicad_sch, SVF.kicad_sch, VCA.kicad_sch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]
2022-06-09 Change glide cap footprint, tweak silkscreen
    [noise_generator.kicad_sch, power_supply.kicad_sch, s&h_mixer.kicad_sch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]
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2022-06-11 Progress on ADSR board, need to decide between VC version or 555 version
    [ADSR.kicad_sch, ADSR_board.kicad_pcb, ADSR_board.kicad_sch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]
2022-06-11 Initial ADSR board layout, 555 version
    [ADSR.kicad_sch, ADSR_board.kicad_pcb, ADSR_board.kicad_sch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]
2022-06-12 Progress on modosc schematic
    [VCA.kicad_sch, VCO_core.kicad_sch, level_shifter.kicad_sch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]
2022-06-12 Progress on ADSR layout
    [ADSR.kicad_sch, ADSR_board.kicad_pcb, ADSR_board.kicad_sch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]
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2022-06-14 Initial mod osc layout
    [VCO_core.kicad_sch, led_driver.kicad_sch, level_shifter.kicad_sch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]
2022-06-15 Add VCF base freq trimmers, tweak track widths
    [CV_mixer.kicad_sch, SVF.kicad_sch, VCA.kicad_sch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]
2022-06-15 Move some headers for better alignment
    [ADSR_board.kicad_pcb, VCF_VCA_board.kicad_pcb, mod_osc_board.kicad_pcb]
2022-06-15 Create pcb sandbox, for checking header alignment and such
    [pcb_sandbox.kicad_sch]
2022-06-16 Progress on ribbon board
    [10_kHz_clock.kicad_sch, VCA_CV_scaler.kicad_sch, basic_s_and_h.kicad_sch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]
2022-06-16 Ribbon board progress, tidy up schem
    [10_kHz_clock.kicad_sch, VCA_CV_scaler.kicad_sch, basic_s_and_h.kicad_sch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]
2022-06-16 Rotate VCF mode switches
    [CV_mixer.kicad_sch, SVF.kicad_sch, VCA.kicad_sch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]
2022-06-17 Change directory structure, minor schem and pcb tweaks
    [10_kHz_clock.kicad_sch, ADSR.kicad_sch, ADSR_board.kicad_pcb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]
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2022-06-17 Add cool kibuzzard labels, minor tweaks
    [ADSR_board.kicad_pcb, ADSR_board.kicad_sch, VCF_VCA_board.kicad_pcb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]
2022-06-17 Fix incorrect notch filter amp
    [SVF.kicad_sch, VCF_VCA_board.kicad_pcb, VCF_VCA_board.kicad_sch]
2022-06-17 Fix rotation of separation pot, regenerate construction docs
    [CV_mixer.kicad_sch, VCF_VCA_board.kicad_pcb]
2022-06-17 Buffer square, add saw polarity jumper
    [VCO_core.kicad_sch, led_driver.kicad_sch, level_shifter.kicad_sch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]
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2022-06-18 Progress on main VCO, schem getting close but not done
    [PWM_generator.kicad_sch, VCO_core.kicad_sch, audio_mixer.kicad_sch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]
2022-06-18 Remove white/pink noise switch from VCO, use the one on the S&H board
    [audio_mixer.kicad_sch, main_VCO_board.kicad_sch, power_supply.kicad_sch]
2022-06-19 Main VCO rough parts placement
    [PWM_generator.kicad_sch, VCO_core.kicad_sch, audio_mixer.kicad_sch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]
2022-06-20 Begin VCO pcb layout
    [VCO_core.kicad_sch, level_shifter.kicad_sch, main_VCO.kicad_sch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]
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2022-06-21 Initial ribbon board layout
    [clocked_s_and_h.kicad_sch, gate_conditioner.kicad_sch, gate_logic.kicad_sch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]
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2022-06-26 Update sample and hold board
    [noise_generator.kicad_sch, power_supply.kicad_sch, s&h_mixer.kicad_sch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]
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2022-06-26 Small VCO silkscreen changes
    [basic_pulse_shaper.kicad_sch, harmonic_pulse_shaper.kicad_sch, main_VCO_board.kicad_sch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]
2022-06-26 Add power supply board
    [power_supply.kicad_pcb, power_supply.kicad_sch]
2022-06-28 Change some ADSR board values
    [ADSR.kicad_sch, ADSR_board.kicad_pcb, ADSR_board.kicad_sch]
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2022-07-07 Change ADSR pot values
    [ADSR.kicad_sch, ADSR_board.kicad_pcb, ADSR_board.kicad_sch]
2022-07-08 Fix VCO issues, suboct switching, component values
    [PWM_generator.kicad_sch, VCO_core.kicad_sch, audio_mixer.kicad_sch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]
2022-07-09 Update ribbon board values
    [10_kHz_clock.kicad_sch, VCA_CV_scaler.kicad_sch, gate_controller.kicad_sch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]
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2022-07-10 Add ribbon assembly screw holes
    [panel_dims.kicad_pcb]
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2022-07-15 Remove copper pour underneath heatsinks
    [power_supply.kicad_pcb]
2022-07-15 Mounting holes to M4, trimmers in easier to reach spot
    [power_supply.kicad_pcb]
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2022-07-21 Update some S&H board values
    [noise_generator.kicad_sch, power_supply.kicad_sch, s&h_mixer.kicad_sch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]
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2022-07-22 Fix calibration typo
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2022-07-23 Increase noise gain in audio mixer
    [PWM_generator.kicad_sch, VCO_core.kicad_sch, audio_mixer.kicad_sch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]
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2022-07-23 Increase linear FM gain on main VCO board
    [lin_FM_conditioner.kicad_sch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]
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2022-08-14 Change VCA R for smoother volume knob action
    [VCA.kicad_sch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]
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2022-08-14 Fix ribbon schematic link
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2023-02-06 Upgrade ADSR board to new analog switch version
    [ADSR.kicad_sch, ADSR_board-B_Cu.dxf, ADSR_board-B_Mask.dxf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]
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2023-03-10 Change value of ribbon scaler R for 1v/oct trimming
    [ribbon_board.kicad_pcb, ribbon_scalers.kicad_sch]
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2023-03-25 Change ribbon DAC scaling resistors for 10v max out
    [ribbon_board.kicad_pcb, ribbon_scalers.kicad_sch]
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2023-03-27 Change all pcbs and panels to KiCad 7, change docs structure
    [ADSR.kicad_sch, ADSR_board-B_Cu.dxf, ADSR_board-B_Mask.dxf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]
2023-03-27 Fix broken schematic links
2023-03-27 Bold ADSR sheet titles, use plotted ADSR schematic
    [ADSR_board.kicad_sch]
2023-04-07 Make upper ribbon R much bigger to mitigate noise issues
    [main.rs]
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2023-04-14 Fix some clippy warnings in board module
    [board.rs]
2023-09-03 Change ribbon panel silkscreen GLIDE knob to DELAY knob
    [ribbon_pcb_panel.kicad_pcb, ribbon_pcb_panel.step]
2023-09-03 Change ribbon GLIDE ctl to DELAY ctl on ribbon board
    [VCA_CV_scaler.kicad_sch, gate_controller.kicad_sch, gate_logic.kicad_sch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]
2023-09-03 Fix ribbon schematic font to match rest of schems
